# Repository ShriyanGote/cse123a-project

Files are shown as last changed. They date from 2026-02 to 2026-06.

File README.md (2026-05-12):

# 123a-project: Smart Pitcher Base

This repo contains all the code, hardware notes, and documentation for our Smart Pitcher Base project. The system is made up of three pieces:

1. **ESP32C3 firmware** — reads the load cell (HX711) on the pitcher base and POSTs readings to the web server.
2. **Web server / dashboard** — a Vite + React app (deployed on Vercel) that ingests readings into Supabase. Account sign-in and a setup guide live at https://cse123a-project-6a3s.vercel.app/.
3. **Mobile app** — an Expo / React Native app that talks to the web server, displays the water level, and receives low-water push notifications.

Everything lives under [`Code/`](Code). Each sub-project has its own README with run instructions.

```
Code/
├── ESP32/         # firmware (ESP-IDF)
├── web-server/    # Vite + React dashboard + Vercel API routes
├── mobile-app/    # Expo / React Native app
└── 3D Designs/    # printable parts for the base
```

---

# Other things in this repo

- [Documentation/](Documentation) — write-ups and design docs
- [Hardware Notes/](Hardware%20Notes) — schematics, PCB revisions, wiring notes
- [HardwarePicture/](HardwarePicture) — photos of the assembled hardware
- [Meeting Notes/](Meeting%20Notes) — weekly meeting notes
- [Status Updates/](Status%20Updates) — milestone / status reports
- [Code/Links to Test Cases.md](Code/Links%20to%20Test%20Cases.md) — index of test cases
- `git-contribution-report.sh` + `aliases.json` + `folders.json` — helpers for generating per-author contribution metrics

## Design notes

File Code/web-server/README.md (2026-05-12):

# Water Level Web Server

Our Web App: https://cse123a-project-6a3s.vercel.app/

Our Webserver Github Repo: https://github.com/ShriyanGote/cse123a-project/tree/54d26662f9176a54d48d1e06c6b1f1091e2e5d16/Code/web-server

This app shows your latest pitcher level from Supabase and receives new sensor readings through `api/ingest.js`.
It can also send low-water notifications via Expo push when the water level is below 20%.

### Mobile / server API (Vercel)

The React Native app calls these routes instead of Supabase directly:

- `GET /api/app-state` — JSON `{ reading, calibration }` (latest row from `water_readings` and `calibration`).

Set `EXPO_PUBLIC_API_BASE_URL` in the Expo app (optional; defaults to the production URL in `src/api.js`).

## Local dev

Install dependencies:

`npm install`

Run the app:

`npm run dev`

## Testing

Run frontend tests:

`npm run test:run`

## Notification Behavior

- `POST /api/ingest` stores each reading, computes water level percent, and sends low-water alerts via Expo push to tokens registered by the mobile app.

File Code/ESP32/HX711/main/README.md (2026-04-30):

# Custom BLE provisioning (CSE 123A)

Firmware replaces Espressif `wifi_prov_scheme_ble` with a small NimBLE GATT server.

## Build

Requires [ESP-IDF](https://docs.espressif.com/projects/esp-idf/) 5.1+ (test with your installed version).

```bash
cd Code/ESP32/provisioning/custom_ble_prov
idf.py set-target esp32
idf.py fullclean
idf.py build
idf.py -p /dev/ttyUSB0 flash monitor
```

## Configuration

- **API URL**: edit `CSE123A_API_BASE` in `main/main.c` (default matches the deployed Vercel app in this repo).
- **UUIDs**: 128-bit service and characteristics match `ProvisionDeviceScreen.js` defaults (`a0b40001…`–`a0b40004…`).
- **Partition size**: this project uses `partitions.csv` with a 2MB factory app partition (default 1MB is too small for this binary).

## Behavior

1. On boot, Wi‑Fi STA is initialized (not associated). BLE advertises with name `ESP32_XXXXXX` (MAC-based).
2. Serial logs print QR JSON: `{"device_name":"…","device_id":"…"}` (same as on-screen QR if your board supports the component).
3. Mobile app writes **AUTH** (base64 JSON `{"auth_token":"<uuid>"}`) then **WIFI** (base64 JSON `{"ssid":"…","password":"…"}`).
4. **STATUS** notifies: `auth_ok`, `wifi_connecting`, `wifi_connected` / `wifi_failed`.
5. After DHCP, firmware POSTs `POST /api/ingest` with `Authorization: Bearer <auth_token>` and body `device_id`, `weight_g`, `battery_mv`.

Apply `Code/web-server/sql/migration_devices_ble_columns.sql` in Supabase so `devices.auth_token` exists before relying on ingest.

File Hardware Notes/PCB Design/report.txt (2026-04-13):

Info: Processing symbol '3.7v1:'.
Info: Processing symbol '4.1:'.
Info: Processing symbol '4.2:'.
Info: Processing symbol '4.3:'.
Info: Processing symbol '4.4:'.
Info: Processing symbol '4.5:'.
Info: Processing symbol '4.6:'.
Info: Processing symbol '4.7:'.
Info: Processing symbol 'J1:'.
Info: Processing symbol 'L1:'.
Info: Processing symbol 'R1:'.
Info: Processing symbol 'R2:'.
Info: Processing symbol 'R3:'.
Info: Processing symbol 'R4:'.
Info: Processing symbol 'U1:Package_DFN_QFN:QFN-20-1EP_4x4mm_P0.5mm_EP2.5x2.5mm'.
Info: Processing symbol 'U2:'.
Info: Processing symbol 'U3:Package_SO:SOIC-16_3.9x9.9mm_P1.27mm'.
Changed U1 value from QFN-20-1EP_4x4mm_P0.5mm_EP2.5x2.5mm to MCP73871.
Updated U1 symbol association from  to /b3683d0f-a161-44e6-8180-e48fbe466e83.
Updated U1 fields.
Updated U1 sheetname to '/'.
Updated U1 sheetfile to '123-pcb-design.kicad_sch'.
Updated U1 footprint filters to 'QFN*4x4mm*P0.5mm*'.
Add net Net-(J1-CC1).
Connected U1 pin 18 to Net-(J1-CC1).
Add net unconnected-(U1-CE-Pad17).
Connected U1 pin 17 to unconnected-(U1-CE-Pad17).
Add net unconnected-(U1-PROG2-Pad4).
Connected U1 pin 4 to unconnected-(U1-PROG2-Pad4).
Add net unconnected-(U1-~{PG}-Pad6).
Connected U1 pin 6 to unconnected-(U1-~{PG}-Pad6).
Add net Net-(U2-IO6).
Connected U1 pin 20 to Net-(U2-IO6).
Add net unconnected-(U1-PROG1-Pad13).
Connected U1 pin 13 to unconnected-(U1-PROG1-Pad13).
Add net unconnected-(U1-STAT1/~{LBO}-Pad8).
Connected U1 pin 8 to unconnected-(U1-STAT1/~{LBO}-Pad8).
Add net unconnected-(U1-SEL-Pad3).
Connected U1 pin 3 to unconnected-(U1-SEL-Pad3).
Connected U1 pin 1 to Net-(U2-IO6).
Add net unconnected-(U1-THERM-Pad5).
Connected U1 pin 5 to unconnected-(U1-THERM-Pad5).
Add net Net-(U1-V_{SS}-Pad10).
Connected U1 pin 10 to Net-(U1-V_{SS}-Pad10).
Add net Net-(3.7v1-+).
Connected U1 pin 15 to Net-(3.7v1-+).
Connected U1 pin 14 to Net-(3.7v1-+).
Connected U1 pin 21 to Net-(U1-V_{SS}-Pad10).
Add net unconnected-(U1-STAT2-Pad7).
Connected U1 pin 7 to unconnected-(U1-STAT2-Pad7).
Add net unconnected-(U1-PROG3-Pad12).
Connected U1 pin 12 to unconnected-(U1-PROG3-Pad12).
Add net unconnected-(U1-V_{BAT_SENSE}-Pad16).
Connected U1 pin 16 to unconnected-(U1-V_{BAT_SENSE}-Pad16).
Add net unconnected-(U1-VPCC-Pad2).
Connected U1 pin 2 to unconnected-(U1-VPCC-Pad2).
Connected U1 pin 11 to Net-(U1-V_{SS}-Pad10).
Add net unconnected-(U1-~{TE}-Pad9).
Connected U1 pin 9 to unconnected-(U1-~{TE}-Pad9).
Connected U1 pin 19 to Net-(J1-CC1).
Updated U1 unit metadata.
Added U1 (footprint 'Package_DFN_QFN:QFN-20-1EP_4x4mm_P0.5mm_EP2.5x2.5mm').
Changed REF** reference designator to U1.
Added U3 (footprint 'Package_SO:SOIC-16_3.9x9.9mm_P1.27mm').
Changed REF** reference designator to U3.
Changed U3 value from SOIC-16_3.9x9.9mm_P1.27mm to HX711.
Updated U3 symbol association from  to /539b080a-a2a2-44ba-a118-466ed1deb788.
Updated U3 fields.
Updated U3 sheetname to '/'.
Updated U3 sheetfile to '123-pcb-design.kicad_sch'.
Updated U3 footprint filters to '*SO*3.9x9.9mm*P1.27mm*'.
Add net E-.
Connected U3 pin 5 to E-.
Add net GPIO_4/ADC_1.
Connected U3 pin 12 to GPIO_4/ADC_1.
Add net unconnected-(U3-RATE-Pad15).
Connected U3 pin 15 to unconnected-(U3-RATE-Pad15).
Add net unconnected-(U3-XI-Pad14).
Connected U3 pin 14 to unconnected-(U3-XI-Pad14).
Add net unconnected-(U3-XO-Pad13).
Connected U3 pin 13 to unconnected-(U3-XO-Pad13).
Add net unconnected-(U3-BASE-Pad2).
Connected U3 pin 2 to unconnected-(U3-BASE-Pad2).
Add net unconnected-(U3-INB+-Pad10).
Connected U3 pin 10 to unconnected-(U3-INB+-Pad10).
Add net Net-(U3-AVDD).
Connected U3 pin 3 to Net-(U3-AVDD).
Add net unconnected-(U3-DVDD-Pad16).
Connected U3 pin 16 to unconnected-(U3-DVDD-Pad16).
Add net Net-(U3-INA-).
Connected U3 pin 7 to Net-(U3-INA-).
Add net Net-(U3-VBG).
Connected U3 pin 6 to Net-(U3-VBG).
Add net VSUP.
Connected U3 pin 1 to VSUP.
Add net Net-(U3-VFB).
Connected U3 pin 4 to Net-(U3-VFB).
Add net unconnected-(U3-INB--Pad9).
Connected U3 pin 9 to unconnected-(U3-INB--Pad9).
Add net GPIO_5/ADC_2.
Connected U3 pin 11 to GPIO_5/ADC_2.
Add net Net-(U3-INA+).
Connected U3 pin 8 to Net-(U3-INA+).
Updated U3 unit metadata.

Info: Total warnings: 0, errors: 0.

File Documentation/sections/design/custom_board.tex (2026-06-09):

\subsection{Prototype Implementation of Custom Design PCB}

In order to produce large amounts of product, the cheapest and fastest method is to use a custom circuit board. This circuit board would ideally integrate all necessary components with as little extra work as possible. We provide an example prototype implementation using available components. These components can be swapped with other similar types, as long as their main functionality is still met. 

The cost of this custom board will depend on the available components and their individual prices. With the design we have created, the estimated cost for the components of 1 board is \$9.99. This price does not include getting a bare board from a fab, or the cost to place the components. As production scales these costs will go down slightly as higher quantities of materials get a discounted per unit price. This board is designed to be simple to manufacture so that time is not spent in the build process. 

\subsubsection{Processor}

The selected processor is the ESP32-C3-MINI-1. This processor is widely available and was selected for the following reasons. It includes 2.4GHz Wi-Fi and Bluetooth antennas in the packaging. This is ideal for our design as it reduces the number of required components. Adding a separate antenna is possible but would require a different chip selection that includes the required pins for Wi-Fi and Bluetooth. 

The pins we use are the GPIO 4 and 5 pins. On this specific chip they are the ADC channels 0 and 4 respectively. These pins allow us to read data from our amplifier chip, and through the code we are able to interpret that as a weight value. These pins are required for this setup. Using another method like I2C or UART might be possible but would require a complete redesign to match our requirements. Analog to Digital pins are the simplest method for this design. 

The power supply for the chip is provided through the 3.3v pin. We selected a power method that was capable of powering both the amplifier board and the ESP chip. Both can be powered with 3.3 volts. For most of their operational time, the ESP chip will be in standby mode which consumes very little power. The most power intensive time is when transmitting via WiFi as that has a tendency to spike the power consumption. In order to handle this, a power management circuit is required to prevent spikes in current. 

Using a voltage divider to GPIO pin 2, a rough estimate of battery charge can be included in software. The board is set up to make this possible with the proper software implementation. By dividing down the voltage from the battery input, measurements can be made occasionally to determine the voltage output from the battery. This can be used with the knowledge that Lithium Ion batteries have a range in voltage output depending on their store of charge. The lower the output the lower the charge. 

\subsubsection{Power Components}

For this design we provide the MCP73871 as an example chip selection. This is a power management IC that is capable of switching between a USB or AC/DC power source, and a lithium ion battery. When the USB or AC/DC source is providing power, it will power the circuit load and charge the lithium ion battery. This chip selection includes a lot more features than our design takes advantage of, meaning room for expansion of features if desired. 

The requirements a selected chip needs to include are the following. First, it needs to output the correct voltage for the selected amplifier and CPU combo. If not using an amplifier but some other method of data collection, then it needs to be able to output the required power for that method. Second, it needs to take two inputs, a USB or AC/DC input, and a lithium ion battery input. Third, it needs to be capable of charging the lithium ion battery, otherwise the product will only last a single charge and then not be useful to the customer. 

Our selection for this design is to use a USB-C charging receptacle. This would allow us to place a floating port anywhere on the base that would be cheap to supply the cables to users. USB-C is a simple standard that can supply enough power if selecting a part that has only power pins enabled. The selected USB-C port in our designs contains the positive and negative power pins and nothing else. This meets the requirements for the selected power management chip. In order to use the design the way we intend you must select a USB-C or other power method that provides a positive and negative feed to the power chip. 

\subsubsection{Load Cell Amplifier}

The load cell amplifier is a required component for this specific design. Changing the design significantly to where it uses a different load cell than we had intended will require a redesign of this specific circuit component as it is only required for the load cell method selected. The load cell we describe requires a board which amplifies the microvolt output it provides. This chip selection is very important for processing the sensitive weight data produced by a load cell. 

The amplifier board must be powered from the same circuitry as the main chip to keep compatibility. In this design we specify 3.3 volts as the power source, but selecting a chip with a 5 volt or higher input would mean the selected amplifier chip must also be capable of 5 volt power, or wired up using a voltage divider circuit to get the required voltage.

The output of the amplifier board is used by the main CPU and program to determine the current weight placed on the sensor. In our design we specify that output going to analog to digital converter pins meaning the output of this device must be an analog signal, or something that can be interpreted by GPIO pins. 

The inputs for this board come from four pins. We have designed the board so that it can be connected through a 4 pin JST connector. Any four pin connector that is small in form factor and can be soldered to the board horizontally, to lower the height requirements, is the best choice for this design. Keeping the height of the board minimal will mean the plastic base can be smaller and take up less space in a customers fridge. A 4 pin connector keeps the product from requiring soldering wires directly to a board, rather the wires for the load cell can be placed in a connector housing and plugged in directly. In order to seal the product well and prevent movement during shipping, a connector with a locking mechanism is the best choice for the design. 

\subsubsection{Load Cell}

The load cell selection makes a big difference in how much the product can handle. For our prototype and our design we selected a 10 kilogram load cell which should be capable of weighing almost all commercial water filter pitchers. This selection means the most compatibility for the most consumers. Selecting a smaller load cell would limit the number of customers who can purchase it if they have larger pitchers capable of holding more than 4 liters of water. Even if the majority of consumers have smaller pitchers, we hope to provide the most availability. 

The load cell in our design uses four wires to provide readings through a load cell amplifier. The design involves connecting the four wires of the load cell to the board using a 4 pin JST connector. The specific connector choice is described in the amplifier section. The boards will be physically separated by plates that have a small hole for cable routing. The cables should run from the load cell, through the hole, to the pin connection point on the custom PCB. 

\subsubsection{Power Preservation}

The boarded will operating through the use of a battery making it vital for the board to consume less power for longer operation duration. Developing a sleeping cycle to shut off components that do not be turned on all day. Wifi and Bluetooth require the most power in operation, making it necessary to have them on only when necessary, such as sending data or BLE provisioning. Since developing sleep and power, memory must be able to preserved through sleep or sudden power shut offs to not lose data.

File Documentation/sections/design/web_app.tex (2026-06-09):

\subsection{Web Application}

The web application serves as the account-management and onboarding companion to the mobile app. 
It is built using React and deployed on a cloud platform, while being backed by a managed relational database. 
Sensor readings, group membership, device records, and authentication data are all managed within the backend infrastructure, 
which is shared between the web and mobile applications. The interface is organized into two side-by-side panels: 
an \textbf{Account} panel (the Settings page) and a \textbf{Setup guide} panel (the Guide page). The web app exists to let users manage the 
account that the mobile app signs in with, review the devices and groups associated with that account, and consult the first-time setup instructions.

\subsubsection{System Architecture}
The deployed architecture has three coordinated layers:

\begin{itemize}
    \item \textbf{Frontend:} Renders the Settings panel and the Guide panel.
    \item \textbf{Backend Server:} Hosts the sensor-ingestion service used by the microcontroller and authenticated REST services used by both the web app and the mobile app to read and update account, group, and device data.
    \item \textbf{Database:} Provides authentication, a Postgres database for groups/devices/readings, and row-level-security enforcement.
\end{itemize}

\subsubsection{Settings Page}
The Settings page is the Account panel of the web app. It serves two states depending on whether the user is signed in.

\paragraph{Signed out.}
The panel renders a Sign-In form with email and password fields. A hint reminds the user to sign in with the same account they use in the mobile app, since the two clients share the same database authentication system.

\paragraph{Signed in.}
After authentication, the panel displays:
\begin{itemize}
    \item The signed-in user's email and a sign-out control.
    \item \textbf{My Groups} --- a list of the groups the user belongs to, including the user's role in each group and the associated device ID where applicable. Group and device data are fetched from the authenticated REST services.
    \item \textbf{My Devices} --- a list of devices owned by the user, showing each device's name and status.
    \item \textbf{Security} --- a button to sign out of all devices currently signed in to the account and a button to delete the account. Deleting the account will revoke all devices and groups associated with the account.
\end{itemize}

\noindent All requests from the Settings page attach the database access token as a Bearer token; the REST services validate the token before returning data scoped to the user.

\subsubsection{Setup Guide Page}
The Guide page is a static, step-by-step walkthrough for first-time setup of a Smart Base. It is intended to be readable on a desktop screen while the user follows along with the mobile app. The guide covers:

\begin{enumerate}
    \item Unboxing and powering on the base.
    \item Installing the mobile app.
    \item Signing in (or creating an account) and granting Bluetooth and Camera permissions.
    \item Opening the Provision Device flow from the mobile dashboard.
    \item Scanning the QR sticker on the base, which auto-fills the device name and ID.
    \item Entering the Wi-Fi SSID and password the base should join.
    \item Sending the authentication token and Wi-Fi credentials to the base over Bluetooth Low Energy.
    \item Waiting for the base to confirm Wi-Fi connectivity and begin reporting readings.
\end{enumerate}

\noindent The Guide page deliberately mirrors the mobile-app provisioning flow so users have a reference while completing setup on their phone.

\subsubsection{REST API}
The backend server exposes a small REST API shared by the web app, the mobile app, and the microcontroller. User-facing requests carry the database access token as a Bearer credential; sensor uploads use a per-device credential established during provisioning.

\begin{itemize}
    \item \textbf{Authentication} --- Handles email/password sign-in, sign-up, and email verification, and issues access tokens for authenticated sessions. The web Settings sign-in form and the mobile Auth screen obtain tokens through the shared database authentication service; all other user-facing REST endpoints require a valid Bearer token before returning account, group, or device data.
    \item \textbf{Account and profile} --- Read the signed-in user's profile, update display name, sign out all active sessions, and permanently delete the account. Used by the Settings page Security actions.
    \item \textbf{App state} --- Returns aggregated state the clients need on load, including recent reading context for the signed-in user. Used by the Settings page and the Guide page. 
    \item \textbf{Device registry} --- List devices owned by the user and register a new device during mobile BLE provisioning (hardware identity plus one-time credential). Listing is used by the Settings page and mobile dashboard; registration is used by the mobile provisioning flow.
    \item \textbf{Group membership} --- List the user's groups, create a new group, join an existing group by invite code, and fetch detailed group data including members and the latest reading. Listing is used by the Settings page and mobile dashboard; create, join, and detail are used primarily by the mobile app.
    \item \textbf{Group management} --- Rename or delete a group, transfer ownership, and update member roles or remove members. Used by the mobile app.
    \item \textbf{Group calibration} --- Set empty and full reference weights for a group's associated device. Used by the mobile Group screen.
    \item \textbf{Sensor ingestion} --- Accept weight readings from the microcontroller over HTTPS, store them, derive water level from calibration data, and optionally trigger low-water push notifications. Used by the Smart Base firmware.
\end{itemize}

\subsubsection{Data Model}
The shared database stores the entities both clients rely on:

\begin{itemize}
    \item \textbf{Devices} --- Registered bases tied to a user account, including identity, display name, and provisioning credentials where applicable. Shown on the Settings page under My Devices and on the mobile app dashboard.
    \item \textbf{Groups and membership} --- Shared groups with invite codes, role-based membership, associated devices, and per-group calibration values. Shown on the Settings page under My Groups and on the mobile app dashboard.
    \item \textbf{User profiles} --- One record per user, including display name and authentication linkage. Used by both the web app and mobile app.
    \item \textbf{Water readings} --- Timestamped weight readings uploaded by the microcontroller. Consumed by the mobile app to show live water level.
\end{itemize}

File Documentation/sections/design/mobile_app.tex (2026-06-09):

\subsection{Mobile Application}

The mobile application is the primary user-facing interface for the Smart Water Filter Base. 
It is the client that displays live water-level readings for shared groups, handles device provisioning over Bluetooth Low Energy, 
manages device groups, and displays low-water notifications on the user's phone. The web application is limited to 
account management and the setup guide while the mobile app is where day-to-day interaction with the system happens.
The mobile app shares its backend database with the web application. The same email/password account works in both applications, allowing users to manage their account and devices from both the web and mobile interfaces.

\subsubsection{System Architecture}
The mobile app interacts with the rest of the system in three ways:

\begin{itemize}
    \item \textbf{Database Authentication} --- Used for sign-in, sign-up, and live profile state. The same database authentication system is used for the web application and the mobile app.
    \item \textbf{Authenticated REST calls} --- Sent to the backend server to fetch and update account, group, device, and calibration data, using the database access token as a Bearer credential.
    \item \textbf{Bluetooth Low Energy (BLE)} --- For the initial device-provisioning handshake with a Smart Base. The BLE path is currently gated to iOS only.
\end{itemize}

\noindent Low-water notifications are scheduled by the mobile app itself and pushed directly to the user's phone.

\subsubsection{Screens and User Flow}
The mobile app is organized as a stack navigator with the following screens:

\begin{itemize}
    \item \textbf{Intro Screen} --- Shown on first launch. Introduces the product before the user can sign up and sign into the app.
    \item \textbf{Auth Screen} --- Email/password sign-in and sign-up, backed by the database authentication system. Sign-up optionally captures a display name. After account creation, the user receives a confirmation email and is required to verify their email before they can sign in.
    \item \textbf{Dashboard Screen} --- The home screen lists the user's groups and devices, lets the user create a new group, join an existing group by invite code, open the device-provisioning flow, and sign out.
    \item \textbf{Provision Device Screen} --- Walks the user through pairing a new base: scan the QR code on the base, enter Wi-Fi credentials, then transmit them to the base over BLE.
    \item \textbf{Group Screen} --- Detailed view for a single group. Displays the latest reading for the group's associated device, includes calibration controls for empty and full water levels, and is the destination opened when the user taps a low-water notification. Calibration is stored per group rather than as a single global record.
\end{itemize}

\subsubsection{Device Provisioning}
The Provision Device flow is the bridge between an out-of-the-box Smart Base and a cloud-connected device tied to the user's account. The flow proceeds in three stages:

\begin{enumerate}
    \item \textbf{Scan QR} --- The user scans a QR code on the physical base with the device camera. The app decodes the provisioning payload and pre-fills device identity and Bluetooth connection parameters for the next steps.
    \item \textbf{Register on the server} --- The app generates a one-time authentication token and registers the device with the backend so future sensor readings can be attributed to the user's account.
    \item \textbf{Transmit over BLE} --- The app connects to the base over Bluetooth Low Energy, sends the authentication token and Wi-Fi credentials, optionally reads a status response from the base, then polls the server until the newly registered device appears before returning the user to the Dashboard.
\end{enumerate}

\subsubsection{Groups and Sharing}
A user's smart bases are accessed through groups. The Dashboard supports creating a new group (optionally associating it with a device the user owns) and joining an existing group via an invite code. Group owners have the option to remove members, transfer ownership, and delete the group.

The Group screen also allows groups owners to calibrate empty and full reference points. Calibration is stored per group (against the group's associated device) rather than as a single global record.

\subsubsection{Low-Water Notifications}
The mobile app monitors its own group devices for low-water conditions and surfaces local notifications when the level drops below threshold. Three pieces work together:

\begin{itemize}
    \item \textbf{Background monitoring} --- While the user is signed in and the app is active, a background process periodically fetches the latest reading for each group that has an attached device.
    \item \textbf{Threshold detection} --- The app computes each group's water-level percentage and compares it against a fixed low-water threshold. Per-group state ensures one notification per low-water event rather than repeated alerts while the level stays low.
    \item \textbf{Local notifications} --- When a group crosses below threshold, the app schedules a local notification. Tapping it opens the corresponding Group screen.
\end{itemize}

\subsection{Summary of Prototype Implemented Features}

\begin{itemize}

\item \textbf{Smart Base}

\begin{itemize}
    \item \textbf{Implementation:}
    \begin{itemize}
        \item ESP32-C3
        \item 900 mAh Li-ion battery
        \item 3D printed container
        \item Load cell, HX711 amplifier
    \end{itemize}

    \item \textbf{Implemented features:}
    \begin{itemize}
        \item Setup and connection with mobile application
        \item Send weight through HTTPS
    \end{itemize}

    \item \textbf{Missing features:}
    \begin{itemize}
        \item Reset button
        \item Humidity proofing
    \end{itemize}
\end{itemize}

\item \textbf{Mobile App and Server}

\begin{itemize}
    \item \textbf{Implementation:}
    \begin{itemize}
        \item React Native on Expo iOS
        \item Vercel hosting, Supabase database
    \end{itemize}

    \item \textbf{Implemented features:}
    \begin{itemize}
        \item Setup, add, and calibrate devices
        \item Create/join/manage groups
        \item View live water level
        \item Receive low-water notifications
    \end{itemize}

    \item \textbf{Missing features:}
    \begin{itemize}
        \item Customize water level threshold to notify
        \item Full push notifications capabilities (locked by Apple paywall)
    \end{itemize}
\end{itemize}

\end{itemize}

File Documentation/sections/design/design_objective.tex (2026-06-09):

\subsection{Design Objective}

Through the goal statement, it is needed that water level is known at all times to the user.
To approach the goal, two parts needed being what hardware is needed to get accurate readings and what software is needed to communicate
the information to the user.

\subsubsection{Hardware}
We will be collecting data from the users through the weight of their water filters. All of the hardware will be contained in a plastic base which the filter will be set on. This will provide space for all of the internal electronics to be enclosed and kept dry in the humid refrigerator environment. The internal components will need to be sealed in completely to prevent them from getting wet. 

The internal hardware components need to complete a few simple tasks. Detail about specific design choices will be explained in later sections focusing on specific component requirements. The following is a list of requirements for the hardware:

\begin{itemize}
	\item Collect real time weight data
	\item Package weight data in an HTTPS packet and send it through Wi-Fi
	\item Work on battery power for long periods of time
	\item Charge the internal battery using a power port
	\item Have Wi-Fi and Bluetooth for initial setup and active use. 
\end{itemize}

With these requirements in mind, our design uses a few internal components. Most components can be mounted to a custom designed circuit board. Others are connected with built in pins to the circuit board. 

%\subsubsection{Load Cell +  Amplifier + Microcontroller}
%Here are the choices made for the load cell we chose:
%\begin{itemize}
%    \item Using a 20kg Load Cell, it gives sufficient room for most consumer water filter pitchers
%    \item HX711 is a high resolution 24-bit analog to digital converter. The amplifier is specifically built for load cells.
%    \item Microcontroller will have functionalities of Wifi, 2 Pins, GND, 3.3V VCC as essential components.
%    \item Small footprint provided by microcontroller paired with a load cell means saving space and weight.
%\end{itemize}

\subsubsection{Software}

The requirements for the software design involve a few segments. They can be split into categories based on which components they interface with. Starting with the microcontroller code, this code needs to be capable of reading in values from the amplifier which provides serial data through an analog to digital converter. This serial data needs to be converted to a weight value and sent to the data collection server using a secure protocol. The microcontroller should also be capable of sending battery status values including a percentage estimate of the battery charge. 

The software from the microcontroller will send packets containing info to the data collection server. This server must be capable of mapping incoming data to related user accounts that are subscribed to the specific device. Using a unique device ID and authentication token given by the server, incoming data can be assigned to the correct point. The device ID should be sent at the time of setup and will not change through operation. The server should keep tables containing users and their subscribed devices. This server needs to be secure and able to handle the traffic of a large number of devices communicating in real time. 

Once the data is at the server, the mobile application used by users should get up to date information about the status of their filter and active fill value. This data should be updated close to real time in order for features such as notifications to work as intended. The mobile application must be capable of authenticating users using username and passwords unique to the user. The application must include information about each subscribed base, and have accurate information about their status. The app should include a notifications system that will alert users that the fill value has passed below the threshold. The application should communicate using secure protocols to prevent user data from being sent unsafely. 

Notifications will be sent to everyone in the associated group when the water level drops below the threshold. This allows all users to be aware of the water level and give everyone the opportunity to refill it when it is empty, making it more likely that it will be refilled.

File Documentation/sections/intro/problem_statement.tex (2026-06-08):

\subsection{Problem Statement}

Living with roommates can sometimes mean your filtered water device is empty when you need water. 
This can be very frustrating and leave you needing to drink tap water while other roommates get to drink cold refrigerated and filtered water.

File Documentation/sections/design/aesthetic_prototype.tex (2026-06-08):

\subsection{Physical Base Design}
The physical base must consist of:
\begin{itemize}
    \item A compartment containing all components (MCU, battery, load cell, amplifier)
    \item A place to rest a pitcher that can then be weighed
    \item A reset button to restart the device
    \item Humidity-proof seals that allow the device to operate inside the fridge environment
\end{itemize}

\noindent{}Our prototype implementation meets these requirements through the following specifications:\\

The physical base consists of two 3D-printed circular plates sandwiching a 75mm bar-type strain gauge load cell. Each plate is 110mm in diameter and 8mm thick, 
printed in PLA/PETG. The top plate has countersink pockets on the bottom face for M4 bolts 
that secure it to one end of the load cell, and the bottom plate attaches to the other end, sitting flat on the surface. The load cell wires route out to the amplifier and microcontroller on a nearby breadboard.

\subsubsection{Exploded View}
    Figure~\ref{fig:exploded} shows the exploded view of the load cell assembly with all components labeled.
    \begin{figure}[H]
    \centering
    
    \caption{Exploded view of the load cell assembly showing top plate, bottom plate, load cell, and M4 hardware.}
    \label{fig:exploded}
    \end{figure}

\subsubsection{Base Plate Schematic}
    Figure~\ref{fig:schematic} shows the design schematic of the base plate with dimensions and screw hole placement.
    \begin{figure}[H]
    \centering
    
    \caption{Design schematic of the base plate.}
    \label{fig:schematic}
    \end{figure}

\subsubsection{Rendering}
    Figure~\ref{fig:full_assembly} shows how the complete system looks when assembled with a water filter pitcher placed on the scale platform.
    \begin{figure}[H]
    \centering
    
    \caption{Diagram of the full system assembly showing the water filter pitcher resting on the load cell platform, with wiring to the microcontroller and amplifier on the breadboard.}
    \label{fig:full_assembly}
    \end{figure}

\subsubsection{Assembled View}
    Figure~\ref{fig:sideview} shows the assembled base from a side view, with the load cell mounted between the two plates and wired to the breadboard.
    \begin{figure}[H]
    \centering
    
    \caption{Side view of the assembled base showing the two base plates, load cell, and wiring to the microcontroller.}
    \label{fig:sideview}
    \end{figure}

\subsubsection{Completed Prototype}
    Figure~\ref{fig:completed} shows the completed smart base prototype.
    \begin{figure}[H]
    \centering
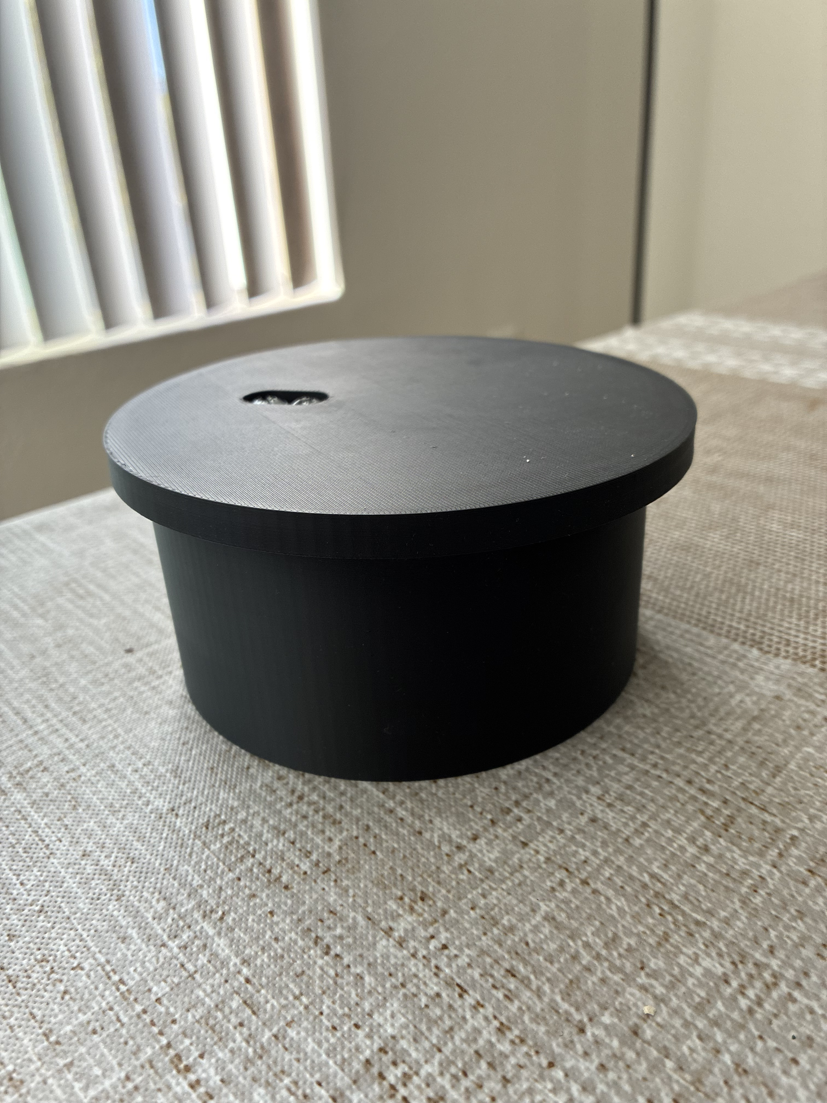
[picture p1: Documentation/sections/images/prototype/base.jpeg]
    
    \caption{Completed smart base prototype sealed.}
    \label{fig:completed}
    \end{figure}

\subsubsection{Typical Use Case}
    Figure~\ref{fig:usecase} shows the finished smart base prototype in a typical use case.
    \begin{figure}[H]
    \centering
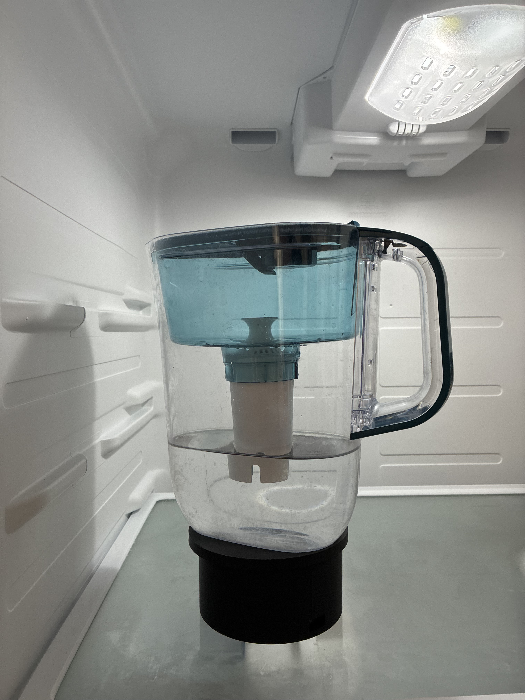
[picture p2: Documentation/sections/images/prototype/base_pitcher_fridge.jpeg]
    
    \caption{Completed smart base prototype with a water filter pitcher on the scale.}
    \label{fig:usecase}
    \end{figure}

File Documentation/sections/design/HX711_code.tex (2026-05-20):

\subsubsection{Amplifier}
The selected load cell for this design requires an amplifier in order to function properly. This amplifier powers the gauge and measures the return voltage through the resistor network. The design includes an amplifier capable of taking in microvolts and outputting 24-bit serial data. This serial data is interpreted by the microcontroller where it is turned to grams. 

\subsubsection{Digital Converter}
To use the design, the software and hardware must be capable of interpreting analog data, converting it to digital data, and performing mathematical operations on the data to convert it to a unit of measurement. Our current design performs the interpretation and conversion to digital at the load cell. The digital data is sent to the microcontroller using GPIO pins where it is operated on by the formulas for conversion to grams. 

\subsubsection{Average Sampling}
To reduce the chance of noise having a heavy affect on our readings, our design implemented an average sampling algorithm, where data is read in for a period of time, averaged, then interpreted as results. This not only prevents high spikes from noise, but also smooths the updating process, so a user placing or removing the filter rapidly will not have an unintended affect on the application, or cause issues like spamming notifications. 

\subsubsection{Tare}
For handling offset, it is required to create to create a baseline state value that represents an empty pitcher. It means future data is can be compared to the baseline value to get the water weight readings. In our prototyping we found the offset value for our specific setup, but this value can change depending on the writing, pathway, and other factors. The offset value must be programmed into the device before is ready to ship.

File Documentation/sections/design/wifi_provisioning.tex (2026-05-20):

\subsection{Smart Base WiFi Provisioning}

In order for the microcontroller to connect to the home network, the user must be able to send the WiFi credentials to the device. This is called WiFi provisioning. In our design, the user connects to the device through BLE and sends the data through the mobile app.

\subsubsection{On Boot}
When the device starts, it will attempt to load saved WiFi credentials and connect to the network. If this fails, it will enter provisioning mode. In our design, the MCU hosts a BLE access point that the user connects to through the mobile app. Once connected, the user will send the WiFi credentials through BLE to the device. The mobile app will also request a unique authentication token from the server for the device to use in the future, which will also be sent over BLE. The MCU will then attempt to connect to the specified WiFi network using the provided credentials. If the connection is sucessful, the device will save the wifi credentials to non-volatile storage and reboot.

\subsubsection{Lost Connection}
If WiFi connection is lost for any reason, the device will enter recovery mode. It will repeatedly attempt to reconnect, exponentially backing off over time to save resources. If connection is restored, the device will go back to normal functioning.

\subsubsection{Manual Reset}
If the user changes WiFi networks or needs to restart the device for any other reason, they can use the reboot button found on the smart base.

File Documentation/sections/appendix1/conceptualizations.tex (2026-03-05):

\subsection{Conceptualizations for Design Approach}
\subsubsection{Contactless Capacitive Water Level Sensing}
A contactless sensor is a small puck that attaches to the side of the water filter. It would work by detecting when the level goes below a certain point, and sending that information to the microcontroller. It's a simple and easy way to do one level detection. It produces a binary output of either above or below the detected level.\\
\noindent\textbf{Pros}
    \begin{itemize}
    \item Low-cost
    \item No contact
    \item Small mechanical approach
    \end{itemize}
\noindent\textbf{Cons}
    \begin{itemize}
    \item Need a good environment for sensor, not humid so not great inside a fridge
    \item Users need to install device themselves, making it hard to standardize what's considered "empty"
    \item Binary output doesn't allow for percentage based information, or any form of consumption metrics. 
    \end{itemize}
    
Because of the noted cons to this design style, we decided to find another solution. The user needing to place the sensor on their own device could throw off any configuration we could complete on our side. It puts too much onto the user for it to work well. 

\subsubsection{Weight based, Load}
The design places the pitcher unto a load cell to measure the weight. We will calibrate it to the changes in weight.\\
\noindent\textbf{Pros}
    \begin{itemize}
    \item Highest accuracy of all designs
    \item Fits to many pitcher dimensions
    \end{itemize}
\noindent\textbf{Cons}
    \begin{itemize}
    \item Need a good environment for sensor, not humid so not great inside a fridge
    \end{itemize}

\subsubsection{Ultrasonic}
An ultrasonic sensor estimates the water level by measuring the echo time of sound waves reflected from the water surface. The sensor would be installed attached to the side of the filter as close to the top of the water compartment. \\
\noindent\textbf{Pros}
    \begin{itemize}
    \item Inexpensive
    \item Easy implementation
    \end{itemize}
\noindent\textbf{Cons}
    \begin{itemize}
    \item Humidity problem
    \item Mounting hardware and wiring sensor is difficult without modifications to container. 
    \end{itemize}
    
If there are modifications to the filter itself in order for a design to work, then the design could not be possible to produce. If we chose this design and needed to modify the pitcher to mount the hardware or get the wiring right, then we would have to sell pre-modified pitchers as well, otherwise users might not be able to use the device properly. Because of these reasons we decided against using this design style. 

\subsubsection{Laser}
A laser or time-of-flight sensor measures the distance from the sensor to the water surface.
The measured distance is converted into liquid height and volume. \\
\noindent\textbf{Pros}
    \begin{itemize}
    \item Continous measurements
    \item Non contact
    \end{itemize}
\noindent\textbf{Cons}
    \begin{itemize}
    \item Humidity problem
    \item Clear line of sight
    \item Mounting problems
    \end{itemize}
    
Some of the same reasons we didn't choose the ultrasonic sensor apply to this laser sensor design. On top of that in order for us to use continuous measurements, the battery power required would raise and we'd have to figure out how to power the device for long periods of time.

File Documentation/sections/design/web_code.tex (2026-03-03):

\subsection{Web Application}

The web application is the user-facing interface for the smart water-level monitor. The design goal is to provide a clear 
real-time estimate of remaining water in the container, allow user calibration for different pitcher sizes, and send refill 
notifications when the water level becomes low.

\subsubsection{Initial Design}

In its most simple form it must be able to display static data on a web page. We have created a .html file with this basic information, shown in the following figure. 

\begin{figure}[h]
\begin{center}

\caption{Output of Initial HTML Code}
\label{basic_html}
\end{center}
\end{figure}

\noindent From here there are a few changes that can be made. These changes follow the line of next steps to test this code and our designs. 

\begin{itemize}
    \item Dynamically updating data with a controller (Proof of concept testing w/ simple text)
    \item Sending and interpreting sensor data 
    \item Graphic interface changes
    \item Sending push notifications to a phone
\end{itemize}

In order to test these things we will create a local server interface using one of our computers that hosts this data. 
Then we will use a microcontroller to send HTTP PUT requests. Finally, using the received data to change what gets displayed. 

\subsubsection{Current Design}

The current design is a React application deployed on Vercel, with a Supabase backend for data storage. The frontend displays the latest water level reading as a percentage, 
along with a visual representation of the water level in the pitcher. Users can calibrate the system by setting empty and full reference points, which allows for accurate 
level estimation regardless of pitcher size or sensor placement. The application also includes functionality to send push notifications to users when the water level falls 
below a certain threshold.

\subsubsection{System Architecture}
The deployed architecture has three coordinated layers:

\begin{itemize}
	\item \textbf{Frontend dashboard:} Displays the latest reading, computes estimated level percentage, and status indicators.
    \item \textbf{Vercel backend:} Receives sensor uploads and notification subscriptions.
	\item \textbf{Supabase Storage:} Stores water readings, calibration parameters, and browser push subscription tokens.
\end{itemize}

\noindent The frontend was designed using the following languages: HTML, CSS, and JavaScript. It utilizes a React framework for building user interfaces. The backend is 
implemented on Vercel, written in JavaScript (Node.js), with API endpoints for data ingestion and notification management. We are using Supabase, which provides a 
PostgreSQL database for persistent storage and real-time capabilities.

\subsubsection{Frontend Design and User Experience}
The current dashboard is minimal and task-focused. Core interface elements are:

\begin{itemize}
	\item A large water-level visualization (pitcher graphic with animated fill height).
	\item A numerical percentage readout for quick interpretation.
	\item A water-present/empty status indicator.
	\item Metadata showing last update timestamp, measured weight, and battery voltage (when available).
\end{itemize}

\noindent Users can quickly assess whether refill action is needed without interpreting raw sensor values.

\subsubsection{API Endpoints}
The application has two primary API endpoints:

\begin{itemize}
    \item \textbf{POST /api/ingest:} Receives sensor readings (device ID, weight, battery) from the microcontroller and stores the data in Supabase. 
    If the weight is below a configured threshold, triggers a low-water notification to registered users.
    
    \item \textbf{POST /api/register-token:} Registers browser push subscriptions from the frontend and saves them in the database.
\end{itemize}

\noindent Sensor data is sent to the ingestion endpoint with an API key, validated, and inserted into a table on Supabase. The dashboard reads the newest 
value from Supabase on a polling interval and renders the latest state. The token registration endpoint enables user devices to register for alert notifications.
When invoked, it associates a device with a user account and stores the device token in a table on Supabase for later use in push notification delivery.

\subsubsection{Supabase Tables}
Supabase serves as persistent storage for both backend APIs and the frontend dashboard state. The ingestion and token-registration endpoints write data to
Supabase using a service-role key, while the frontend dashboard queries the same tables to render the latest readings and calibration settings.\\

\noindent The current deployment uses the following tables:

\begin{itemize}
	\item \textbf{\texttt{water\_readings}} --- Stores time-series sensor uploads from the microcontroller. Each row represents one sample and includes the
	device name, weight in grams, and battery voltage in millivolts (e.g., \texttt{device\_id}, \texttt{weight\_g}, \texttt{battery\_mv}) with a timestamp (\texttt{created\_at}).

	\item \textbf{\texttt{notification\_tokens}} --- Stores browser/device push tokens used for low-water alerts. Tokens are inserted or upserted on
	registration and are later queried by the ingest pipeline when a low-water event occurs.

	\item \textbf{\texttt{calibration}} --- Stores user calibration references for level estimation. The dashboard upserts a single calibration record
	(using \texttt{id} constant) containing empty and full reference values (\texttt{empty}, \texttt{full}), then reads the latest entry when computing displayed percentage.
\end{itemize}

\subsubsection{Calibration}
To support different pitcher geometries and sensor offsets, the application includes user calibration controls:

\begin{itemize}
	\item \textbf{Calibrate empty:} Stores the current reading as the empty reference.
	\item \textbf{Calibrate full:} Stores the current reading as the full reference.
	\item \textbf{Reset calibration:} Clears stored values and falls back to default constants.
\end{itemize}

\noindent The level estimate is computed by linearly mapping measured weight between empty and full references, 
then clamping the result between 0\% and 100\%. This makes the UI behavior predictable while still allowing practical 
adjustments.

\subsubsection{Push Notifications}
The push notification feature is designed as an event-driven subsystem that alerts users only when refill action is needed. 
The implementation uses standard Web Push protocols with VAPID authentication and is integrated into the ingest API used for sensor data.

\paragraph{1) Subscription Registration}

When the dashboard is loaded, the browser requests notification permission. If permission is granted, a service worker is registered and 
a Push API subscription is created (or reused if it already exists). The subscription object is sent to the backend endpoint and stored 
in the \texttt{notification\_tokens} table in Supabase.

\noindent This registration path has two design goals:
\begin{itemize}
	\item maintain a durable list of reachable user devices, and
	\item avoid duplicate subscriptions by upserting on token value.
\end{itemize}

\paragraph{2) Alert Trigger Condition}

Sensor readings are received by the ingestion endpoint and stored in \texttt{water\_readings} table. For each new reading, the backend 
computes current and previous water-level percentages and checks for a low-level threshold crossing. The low-water threshold is currently set to 20\%.
This design prevents repeated notifications while the level remains continuously low.

\paragraph{3) Delivery}

If the trigger condition is true, the backend loads all stored subscriptions and sends a Web Push payload to each valid endpoint. The payload includes a:
\begin{itemize}
	\item notification title
    \item notification body
	\item structured data (event type and level percentage) for client-side handling.
\end{itemize}

\noindent The service worker receives the push event, displays the notification, and handles click interaction by focusing an existing app tab or opening the web page.

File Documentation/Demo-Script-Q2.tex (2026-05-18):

\documentclass[12pt]{article}

\usepackage{graphicx}
\usepackage{fancyhdr}
\usepackage{geometry}
\usepackage{xcolor}
\usepackage{enumitem}
\usepackage{url}

\geometry{margin=1in}

\title{CSE 123 - Demo Script\\Smart Water Pitcher Base\\NOT TURNED IN DONT MAKE IT LOOK GOOD}
\author{Group 8}
\date{}

\begin{document}
\pagestyle{fancy}
\maketitle
\fancyfoot{}
\fancyhead{}
% \fancyfoot[R]{\thepage}

%% --------------------------------------------------------
\section*{Introduction}
\noindent\textbf{Presenter:} Pieter\\  
\noindent\textbf{Estimated Time:} 1.5 minutes

\noindent\textbf{Action:} Hold up or gesture toward the water pitcher.

\bigskip
\noindent\textit{Script:}

\begin{quote}

Sharing a communal water filter can lead to unfortunate moments where you want water, but there is none left in the pitcher. What can be done about this issue? What are the root causes of this problem? And how can we design a solution to reduce the number of times this happens to you. 

We all have that one person who returns the filter back empty. They just took a large bottle's worth of water but didn't take the time to refill the pitcher for the next person. With this smart base two things will happen. First, you will be able to access an app that tells you how much water is in the pitcher at any given time. This can let you know how much water is in the pitcher at any given time. Second, a notification will alert you if the pitcher is returned with water below 20\% full. 

With all of these features in mind, how do they work, and how will you the user interact with our product? 

\end{quote}

%% --------------------------------------------------------
\section{Typical Usage}
\noindent\textbf{Presenter:} TODO\\  
\noindent\textbf{Estimated Time:} TODO\\

\noindent\textbf{Action:} Screen should show app and camera pointed at prototype.

\bigskip
\noindent\textit{Script:}

\begin{itemize}[itemsep=-3pt]
\item screen shows current water lvl
\item \textbf{Action: }\textit{Take out some water}
\item now it shows the new level
\item now i'll completely empty it
\item \textbf{Action: }\textit{Empty pitcher}
\item as you can see the water level updated and everyone in the group rcvd a notification to refill
\item \textbf{Action: }\textit{Refill pitcher}
\item and now it shows that its full again
\end{itemize}

%% --------------------------------------------------------
\section{Account Creation}
\noindent\textbf{Presenter:} TODO\\  
\noindent\textbf{Estimated Time:} TODO\\

\noindent\textbf{Action:} Screen should show app and camera pointed at prototype.

\bigskip
\noindent\textit{Script:}

\begin{itemize}[itemsep=-3pt]
\item create account w email, name etc
\item show email verification and verify
\item sign in on app
\end{itemize}

%% --------------------------------------------------------
\section{Provisioning}
\noindent\textbf{Presenter:} TODO\\  
\noindent\textbf{Estimated Time:} TODO

\bigskip
\noindent\textit{Script:}

\begin{quote}

``When first purchasing product, users need to set up the device. they start by opening app and click setup.''
\vspace{5px}\\\textbf{Action: }\textit{Open setup page on mobile app}\vspace{5px}\\
``First scan qr code that comes with the device to connect to it over bluetooth.''
\vspace{5px}\\\textbf{Action: }\textit{Scan QR code}\vspace{5px}\\
``Next enter the home wifi name and password, which will be sent to the device along with an auth token so it can communicate with the server.''
\vspace{5px}\\\textbf{Action: }\textit{Enter WiFi credentials}\vspace{5px}\\
``Once it is connected, users can create a group and invite other users to it, so they can all see the water level and get notifications when it needs to be refilled.''
\\\textit{}\\
\end{quote}

%% --------------------------------------------------------
\section{Joining a Group}
\noindent\textbf{Presenter:} TODO\\  
\noindent\textbf{Estimated Time:} TODO

\bigskip
\noindent\textit{Script:}

\begin{itemize}[itemsep=-3pt]
\item open group page
\item select device, enter name,  and create group
\item open group and show current water level
\item pour some water out and show it reflects change
\item show group code, let other person join, show that they joined on the group page
\item textbf{hold other phone under camera for other person joining}
\item empty water filter and show both ppl got the notif
\item change group name
\item delete group
\end{itemize}

%% --------------------------------------------------------
\section{Calibration}
\noindent\textbf{Presenter:} Pieter\\
\noindent\textbf{Estimated Time:} 2 minutes

\bigskip
\noindent\textit{Script:}

\begin{itemize}[itemsep=-3pt]
\item open group
\item explain why calibrate
\item do empty and full
\end{itemize}

In order for the product to be useful to every possible customer, a calibration sequence is required when setting it up. This calibration feature is also available at any time if the user purchases a new filter. Setting the calibration requires an empty and a full value. 

We'll start with full. First, take the pitcher at a full level and place it on the base. Then navigate through the app to find the calibration buttons. Once the full pitcher is on the scale, press "Calibrate Full".  Next, pour out the water from the filter until it is all empty. Place the pitcher back on the scale and press "Calibrate Empty". Now the levels will be accurate to your specific water filter. 

%% --------------------------------------------------------
\section{Webpage}
\noindent\textbf{Presenter:} TODO\\
\noindent\textbf{Estimated Time:} TODO

\noindent\textbf{Action:} Screen should show the webpage open in a browser.

\bigskip
\noindent\textit{Script:}

\begin{quote}
``Alongside the mobile app, we also have a webpage that users can access from the browser.''
\vspace{5px}\\\textbf{Action: }\textit{Setup Guide panel}\vspace{5px}\\
``The webpage hosts our setup guide, so a new user can go through the steps and setup their Smart base. These steps cover from openeing the packaage to having it connected to wifi.''
\vspace{5px}\\\textbf{Action: }\textit{Open the webpage and sign in}\vspace{5px}\\
``The second part of thewebpage  focuses on account management. Once a user signs in, they come to their account page, where they can see all the groups they are in  and all the devices linked to their account. They  also have some security features like signing out everywhere and deactiviting their account, in case their phone gets lost or stolen.''
\vspace{5px}\\\textbf{Action: }\textit{Show signing out everywhere feature}\vspace{5px}\\
``Clicking on the singing out feature, will sign all devices that are loggged in this account out.''
\vspace{5px}\\\textbf{Action: }\textit{Show delete account}\vspace{5px}\\
``Clicking on the delete account button, will delete the account. Once you delete it, it is gone. After that you must create a new account.''\end{quote}
%% --------------------------------------------------------

% conclusion
\end{document}

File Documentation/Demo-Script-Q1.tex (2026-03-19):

\documentclass[12pt]{article}

\usepackage{graphicx}
\usepackage{fancyhdr}
\usepackage{geometry}
\usepackage{xcolor}
\usepackage{enumitem}
\usepackage{url}

\geometry{margin=1in}

\title{CSE 123A - Demo Script\\Water Level Monitoring System}
\author{Group 8}
\date{}

\begin{document}
\pagestyle{fancy}
\maketitle
\fancyfoot{}
\fancyhead{}
% \fancyfoot[R]{\thepage}

%% --------------------------------------------------------
\section*{Part 1: Introduction}
\noindent\textbf{Presenter:} Pieter\\  
\noindent\textbf{Estimated Time:} 1 minute

\noindent\textbf{Action:} Hold up or gesture toward the water pitcher.

\bigskip
\noindent\textit{Script:}

\begin{quote}
``Has this ever happened to you? You come home after a long day, you're thirsty, and you go to grab the water filter pitcher---only to find it completely empty. Nobody refilled it.
This is a common problem in shared living spaces---dorms, family homes, offices. Everyone uses the filtered water, but nobody knows when it's running low until it's too late. We want a way to know if the container is out of water when we need water. The goal is if the container is empty, we inform users.
Our project hopes to solve this. We built a smart water level monitoring system that sits underneath your water filter pitcher, continuously tracking how much water is left, and sends a notification to everyone in the household when it's time to refill.''
\end{quote}

%% --------------------------------------------------------
\section*{Part 2: Overview }
\noindent\textbf{Presenter:} Reid\\  
\noindent\textbf{Estimated Time:} 1.5 minutes

\noindent\textbf{Action:} Point at the various system components as they are mentioned.

\bigskip
\noindent\textit{Script:}

\begin{quote}
``Our design has three main components: the smart base, the web server, and the mobile app.

The smart base sits beneath the water pitcher and measures the weight of the pitcher, which can be used later to determine how much water is left. This weight data is sent to our web server over WiFi using HTTP packets, where it's stored in a database and processed. 

The mobile app is connected to the web server and is able to access this weight data. When the water level drops below a certain threshold, the mobile app will send push notifications to the users. The app also allows users to view the current water level and configure various settings.

\textit{[Switch to prototype diagram.]}
Today, we will be demonstrating the prototype of our design. We are simulating the connection between the smart base and the web server through two laptops: one connected to the microcontroller to read the sensor data, and another sending simulated weight data to the web server. Our mobile app is currently in the form of a webapp on a laptop, but still has the core functionality that the mobile app would have.'' 

\end{quote}

%% ------------------------
\section*{Part 3: Hardware \& Live Demo}
\noindent\textbf{Presenters:} Dev \& Logan\\  
\noindent\textbf{Estimated Time:} 3 Minutes

\noindent\textbf{Action:} Dev places the pitcher on the platform with the terminal open on the connected laptop. Logan picks up or points to each hardware component as he explains it.

\bigskip
\noindent\textit{Script:}

\medskip
\noindent\textbf{Dev:}
\begin{quote}
``Let me set up the live demo first. I'm going to place this empty water pitcher on the sensor base. Over here on the laptop we have the terminal open, where you can see the raw weight readings coming in from the microcontroller via USB. The load cell is now measuring the weight of the pitcher.

While this sits on base, Logan is going to walk you through the hardware that makes this work.''
\end{quote}

\medskip
\noindent\textbf{Logan:}
\begin{quote}
So let me break down what's going on inside this base. The system has three main components:

\textbf{First, the load cell.} This is a strain-gauge weight sensor. When weight is applied, it bends slightly, and that bending changes its electrical resistance. The change is very tiny---so we use the \textbf{HX711 amplifier board} to boost the signal into something our microcontroller can read. The HX711 gives us 24-bit resolution, which means we can detect very small changes in weight.

\textbf{Second, the microcontroller.} This is the brain of our system. It reads the weight data from the HX711 and outputs the readings to the terminal you see on the laptop.

\textbf{Third, the mounting base.} We designed and 3D-printed two circular plates that sandwich the load cell. The pitcher sits on top. We designed these with M4 screw holes so everything stays secure and aligned.''
\end{quote}

\medskip
\noindent\textbf{Dev:}
\begin{quote}
``Now that you know how the hardware works, let me show you how it reads in action. So right now the terminal is showing the current weight value with the pitcher on the base.

So now let me pour some water in to simulate a user putting water in the pitcher.

\textit{[Pour water into the pitcher.]}

Now if you watch the terminal, you can see the weight values increasing as we pour water into the pitcher. The microcontroller is reading the load cell continuously, so the changes show up right away.''
Now let me pour some water out to simulate someone using the pitcher throughout the day.

Now let me pour some water out to simulate a user using some of the water from the pitcher.
\textit{[Pour water out of the pitcher into a cup.]}
 
And just like before, you can see the values in terminal drop as the water after we put the pitcher back on the base.

\end{quote}

% show how software works

\section*{Part 5: Software Demo}
\noindent\textbf{Presenter:} Shriyan\\  
\noindent\textbf{Estimated Time:} 4 minutes

\noindent\textbf{Action:} Open laptop to the web server to demonstrate navigating the page

\bigskip
\noindent\textit{Script:}

\begin{quote}
``The initial prototype uses a web dashboard to display important device information. This dashboard is also where the initial configuration of the product happens. When a user first starts up this device, they need to calibrate it with empty and full weights. 

\textit{[Highlight calibration buttons]} Both an empty and a full value are required for the product to work as intended. In the startup sequence the user will be prompted for an empty pitcher of water to be placed on the base. After pressing the calibration button they will be asked to fill it up and return it to the base to calibrate the full value. 

Full and empty values are adjustable and configurable at any time, so if a user buys a new filter that holds a larger quantity of water, they can simply change the calibration values and continue using the device as intended. 

When the values are calibrated, the system is able to use the data sent by the microcontroller to adjust the visible water level."
\end{quote}

% show how notifications work
\section*{Part 6: Notification Demo}
\noindent\textbf{Presenter:} Sam\\  
\noindent\textbf{Estimated Time:} 3 minutes

\noindent\textbf{Action:} Keep the dashboard visible and reset the water level to above the low-water threshold 20\%.

\bigskip
\noindent\textit{Script:}

\begin{quote}
``Now we will demonstrate the push notification feature and how we can subscribe to notifications for when the water level is running low.

\textit{[Point to the current percentage on the dashboard.]}
As you can see here on the dashboard, right now, the water level is at [read water level value]. Our low-water threshold is currently set to 20\% and as you can see, the pitcher level is above 20\% right now, so no notifications will be sent. 
Once the level drops below that threshold, the web app will trigger a push notification to subscribed devices. But to see this happen, we have to first subscribe to notifications. 

\textit{[Point to "Enable Notifications" button on the dashboard.]} Once you click on this button here that says "Enable Notifications", it will prompt you to allow notifications for our web app. Once you press allow on the prompt, your device will be subscribed and ready to receive notifications.
Now lets try clicking on the button and allowing notifications.

\textit{[Click on "Enable Notifications" button and allow]} Ok, now that we have enabled notifications, you can see on the dashboard under the Water Pitcher Status that it says "Notifications are enabled".
Now, we can test it out by first measuring the pitcher when it is near empty. [Water Refiller Person] will now pour out water from the pitcher until it is almost empty and put it back on the base. 

\textit{[Pour out water from the pitcher]} And since our base is currently not integrated with the webapp, we will simulate this change by manually sending a low weight value to the web server to trigger the notification. Once the low weight value is sent, 
you should see the dashboard update to show the new water level and you will also be able to see the push notification appear on the top right corner of the screen, so please watch closely. We will now send the low weight value.

\textit{[Simulate water level to less than 20\%]} As you can see on the dashboard, it now reads [read value below 20\%]. You should've also seen the push notification pop up on the top right corner of the screen. If you were paying attention, you would've seen that the message payload in the notification 
showed that the filter is running low and needs to be refilled. It also showed the current water level percentage. Now [Water Refiller Person] will refill the pitcher to a percentage that is above the low-water threshold. 

\textit{[Refill the pitcher to above the low-water threshold and put on base]} After the pitcher is refilled and the percentage rises, the system returns to normal and waits for the next low-water event.''
\end{quote}

% Q&A

\section*{Part 7: Questions}
\noindent\textbf{Presenter:} Pieter (prof suggested same as intro person)\\  
\noindent\textbf{Estimated Time:} 5 minutes

\noindent\textbf{Action:} Leave all components visible on the center of the demo table, ready to be moved or pointed at for any questions regarding hardware. 

% conclusion
\end{document}

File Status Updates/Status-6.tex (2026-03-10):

% status report 6
\documentclass[12pt]{article}
\usepackage{graphicx}
\usepackage{fancyhdr}
\usepackage{geometry}
\usepackage{hyperref}
\usepackage{xcolor}
\usepackage{url}
\geometry{margin=1in}

\title{CSE 123A - Week 6 Status}
\author{Group 8}
\date{}

\begin{document}
\pagestyle{fancy}
\maketitle

\fancyfoot{}
\fancyhead{}
\fancyfoot[R]{\thepage}

\noindent Link to Status Updates section in our repo \\
\url{https://git.ucsc.edu/pnauwela/123a-project/-/tree/main/Status\%20Updates?ref_type=heads}\\
\noindent Demo\\
\url{https://git.ucsc.edu/pnauwela/123a-project/-/blob/main/Documentation/Demo-Script.pdf?ref_type=heads}\\
\noindent Design Schematic\\
\url{https://git.ucsc.edu/pnauwela/123a-project/-/blob/main/Documentation/Diagrams/Architecture_Diagram.pdf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}\\
 % whats been completed 
\section*{What we Did}
This week we conducted code tests on important system functionality. The tests were created for the microcontroller code and focused on verifying logic for the sensor. We also updated significant portions of documentation and diagrams to prepare for presentations. These design documents will be important when presenting the initial prototype. 

Another major improvement came in the hardware. They were reprinted to recess the screws and create a flat plane for more accurate measurements. We now also have code working for HTTP GET and POST requests from a separate microcontroller. This is just as a proof of concept and will eventually be included in the main system code. 
 
% whats in progress
\section*{What we are Working On}

We are working on preparing a script for the initial prototype presentation. We are also working on system connections to prepare for the next iteration of our prototype. Most of the work in-progress is documentation as we wrote code and now need to document how it works and why we chose to write it this way. 

% what next on the agenda 
\section*{What's next}

The next step is to complete the presentation script. It is also to have a more complete document to provide for the design document. We also need to prepare for the next changes we will be implementing in spring quarter. The next iteration of the design is already in the planning stages and we have an idea of what direction we will be going in. 
% Individual contributions

\section*{Individual Contributions}

\noindent\textbf{Dev Chodavadiya}:

This week I focused on hardware iteration and documentation. 

On the hardware side, I reprinted the base plates to fix a flatness issue — the previous prints were slightly slanted, so I adjusted the print settings to ensure the bottom plate sits level on a surface. 

On the documentation side, I made progress on the design document by writing the research into existing designs section, the sustainability statement, and the aesthetic prototype section with CAD renders and photos of the current assembly.

I will design and print washers to go between the load cell sensor and the plates for better contact and stability. The team will continue working on the demo script to have it ready for the demonstration.\\

\noindent\textbf{Logan Bossuwe}:

This week I focused integrating Wifi and Http post with the weight code using Rieds code. Currently harded coded credentials for network access but HTTP post working correctly with sending Grams. I created a main file to modularize our code for future adds on.

For documentation, I focused on updating Design document for the HX711 sensor. Additionaly, I added towards the brainstorming and conceptualisation that are I already briefly wrote earlier in the quarter. I reformatted and edited it to match the Design Document theme. In addition, I started documenting collaboration.

I will be working on creating a proper Wiring Diagram next week and working toward more test plan documentation and code simulations.\\
\noindent\textbf{Pieter Nauwelaerts}:

This week I created the testing code for the HX711 sensor. The major changes include a different way of approaching how we design the microcontroller code in order to allow us to switch between the microcontroller, and test code. This was done using a C header file to define the shared functions, and having two separate main files, one for microcontroller deployment, and one for testing. 

The test code simulates the Wheatstone bridge sensor and passes the functions data that would come in or out. Simulated weight readings go into the functions, the logic is the same as the logic used by the microcontroller, and the output comes out as is verified agains what we should expect to see. The logic we use in the microcontroller can now be verified and tested. This includes pushing it to the limit by having very fast sequences of activity and checking that the outputs come out in the same order. 

\noindent\textbf{Reid Graham}:

This week, I created the code for the microcontroller to connect to a WiFi network and send HTTP GET and POST requests. I also created header files for organization and relavant functions, as well as helped to integrate this functionality into the main file. I also created some test code for the WiFi provisioning code, including testing important functions like url decoding. For the physical sensor, I installed a new base plate for the scale that made it more stable.

I also worked on the design document, including editing the architecture diagram, adding to the block diagrams section, and writing some of the documentation for the WiFi provisioning functionality.

For the next week, I want to prioritize finalizing the design document, including the sections on test plan and results and MCU HTTP functionality.

\noindent\textbf{Sam Lai}:

This week, I worked on reimplementing the push notification logic for the webapp to use Push API instead of Firebase Cloud Messaging. 
The web app is now able to receive push notifications on all browsers on desktop, android, and on IOS safari home screen apps. The app
will prompt the user to allow notifications, and if they accept, it will subscribe them to push notifications. I also worked on the web 
app section of the design document. This includes writing about the initial design and the current design of the web app which includes 
detailed sub sections about the architecture, frontend design, backend api endpoints, database tables, and the push notification system. 
I will continue to work on the design document and will be focusing on the testing section next. I will also be working on creating unit 
tests for the notification system and subscription prompt.

\noindent\textbf{Shriyan Gote}:

This week, I wrote C files to test the server connection using POST HTTP requests from the microcontroller. I also wrote documentation about the web app code, re-did the calibration flow in the dashboard, and worked on adding environment variables to Vercel for deployment.\\

\end{document}

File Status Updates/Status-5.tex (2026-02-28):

% status report 5
\documentclass[12pt]{article}
\usepackage{graphicx}
\usepackage{fancyhdr}
\usepackage{geometry}
\usepackage{hyperref}
\usepackage{xcolor}
\usepackage{url}
\geometry{margin=1in}

\title{CSE 123A - Week 5 Status}
\author{Group 8}
\date{}

\begin{document}
\pagestyle{fancy}
\maketitle

\fancyfoot{}
\fancyhead{}
\fancyfoot[R]{\thepage}

\noindent Link to Status Updates section in our repo \\
\url{https://git.ucsc.edu/pnauwela/123a-project/-/tree/main/Status%20Updates?ref_type=heads}

 % whats been completed 
\section*{What we Did}
This week, we calibrated the load cell to within 1-2 grams for current tests, redesigned the base plate to be thicker, and changed 
the screw hole layout to ensure the bottom stays flat. We also updated our engineering drawings and architecture diagram 
to match our new initial prototype scope. We restructured the web app to support calibration directly from the UI and also created 
web app unit tests for water-level calculation and calibration logic. The user can now calibrate the empty and full states, which 
are used to calculate the water level percentage. 
 
% whats in progress
\section*{What we are Working On}
We are working on bridging the gap between each others smaller works. Best example is starting to send/recieve data to the webserver. Additionaly, the plates
for the prototype had a mistake in the initial design, so we are revising for more accuracate weight measures. We also began working 
on a demo script for our end-of-quarter presentation and the push notification logic is being reimplemented using Push API instead of 
Firebase Cloud Messaging, which will allow us to send push notifications on IOS devices.

% what next on teh agenda 
\section*{What's next}
We plan to print the newly redesigned base plates, which has a flat bottom to provide more accurate and stable weight 
readings. We are also increasing the plate thickness to handle heavier loads and expanding the plate dimensions to accommodate 
a wider variety of container sizes.

% also have indivudal secitons of what each persion did and is working on

\section*{Individual Contributions}

\noindent\textbf{Dev Chodavadiya}:
This week, I redesigned the base plate to increase its thickness and revised the screw hole layout to a racetrack pattern, 
ensuring the bottom surface sits flat. I also created engineering drawings for the base plates and worked on developing a 
demo script for our end-of-quarter initial prototype presentation.\\

\noindent\textbf{Logan Bossuwe}:
This week I calibrated the weight to the accuracy within 1-2 grams of the weight. I will test future weights heavier than 5kg. I began looking at combining the code Ried wrote so we can start sending data through http.
I also began adding toward the design document with the calibrating code document. \\

\noindent\textbf{Pieter Nauwelaerts}:
Significant updates to diagrams for the initial prototype presentation. Changes include noting that we will be showing the smart base reporting data to a laptop serial connection rather than through a WiFi to server connection. We will also be demonstrating a web app rather than a working phone app. 
I also began the process of creating test programs for the current sensor setup so we can test the code written and determine if any fixes or possible corner cases were left out. This also includes limit testing how fast the data can be updated, as well as how it handles repeated changes to the state. \\

\noindent\textbf{Reid Graham}:
This week, I restructured the design document to better match the outline in Canvas and to include important information on the architecture of our product.
I also updated the architecture diagram after our discussion on communication between the microcontroller and web server. It now shows that the MCU will only send data, the weight, and calculations and calibration will happen on the webapp side. \\ 

\noindent\textbf{Sam Lai}:
This week, I worked on creating unit tests for the web app, specifically for the water level calculation and calibration actions. 
The unit tests cover several cases, such as when there is no weight data available, whether the water level is correctly calculated 
based on the weight data, and whether the calibration action correctly updates the calibration data. I am currently working on reimplementing 
the notifications using Push API instead of Firebase Cloud Messaging. Push API has all the features of Firebase Cloud Messaging, but 
it is able to send push notifications on IOS devices, which is a major advantage over Firebase Cloud Messaging. \\

\noindent\textbf{Shriyan Gote}:
\noindent This week, I worked on calibration and end-to-end testing with the ESP32 by sending sample weight readings and validating 
the computed water level against expected base values. I also restructured the web app to support calibration directly from the UI 
by adding configuration controls (calibrate empty/full) that store values in Supabase and update the percentage calculation based on 
those calibration points.\\

\end{document}

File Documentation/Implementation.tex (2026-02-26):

\documentclass[12pt]{article}
\usepackage{graphicx}
\usepackage{fancyhdr}
\usepackage{geometry}
\usepackage{xcolor}
\usepackage{pgfgantt}
\usepackage{url}
\geometry{margin=1in}

\title{Implementation Doc}
\author{Group 8}
\begin{document}
\pagestyle{fancy}
\section{Design Approach}
\subsection{Contactless Capacitive Water Level Sensing}
The strip will be placed vertically on the exterior side of the brita/pitcher to detect exact water level. 
Works as long as plastic is not too thick which britas fit the description. 

\subsubsection{Pros}
    \begin{itemize}
    \item Low-cost
    \item No contact
    \item Small mechanical approach
    \item Customizable for future addons
    \end{itemize}
\subsubsection{Cons}
    \begin{itemize}
    \item Need a good environment for sensor, not humid so not great inside a fridge
    \end{itemize}

\subsection{Weight based, Load}
The design places the pitcher unto a load cell to measure the weight. We will calibrate it to the changes in weight.
\subsubsection{Pros}
    \begin{itemize}
    \item Highest accuracy of all designs
    \item Fits to many pitcher dimensions
    \end{itemize}
\subsubsection{Cons}
    \begin{itemize}
    \item Need a good environment for sensor, not humid so not great inside a fridge
    \end{itemize}

\subsection{Ultrasonic}
An ultrasonic sensor estimates the water level by measuring the echo time of sound waves reflected from the water surface.
\subsubsection{Pros}
    \begin{itemize}
    \item Inexpensive
    \item Easy implementation
    \end{itemize}
\subsubsection{Cons}
    \begin{itemize}
    \item Humidity problem
    \end{itemize}

\subsection{Laser}
A laser or time-of-flight sensor measures the distance from the sensor to the water surface.
The measured distance is converted into liquid height and volume.
\subsubsection{Pros}
    \begin{itemize}
    \item Continous measurements
    \item Non contact
    \end{itemize}
\subsubsection{Cons}
    \begin{itemize}
    \item Humidity problem
    \item Clear line of sight
    \end{itemize}

    \section{Decision Matrix}

Criteria will be scored on a scale from 1 (poor) to 5 (excellent). Weights were assigned according to relative importance. The final score for is calculated as:

\[
\textbf{Total Score} = sum(weight × score)
\]

\subsection{Evaluation Criteria}

\begin{itemize}
\item \textbf{Cost}: Estimated hardware and implementation expense
\item \textbf{Power}: Power consumption and low-power operation
\item \textbf{Complexity}: Mechanical, electrical, software integration difficulty
\item \textbf{Measurement Data}: Quality of information provided (Continous water level, binary off or on, ability to track water usage)
\end{itemize}

\subsection{Weighted Decision Matrix}

\begin{table}[h]
\centering
\begin{tabular}{lcccc}
\hline
\textbf{Criteria (Weight)} & \textbf{Capacitive} & \textbf{Weight} & \textbf{Laser} & \textbf{Ultrasonic} \\
\hline
Cost (0.30) & 5 & 4 & 3 & 5 \\
Power (0.20) & 5 & 4 & 3 & 4 \\
Complexity (0.25) & 5 & 3 & 2 & 3 \\
Measurement Data (0.25) & 3 & 5 & 3 & 3 \\
\hline
\textbf{Weighted Total} & \textbf{4.40} & \textbf{3.95} & \textbf{2.70} & \textbf{3.85} \\
\hline
\end{tabular}
\caption{Decision matrix comparing feasible sensing approaches (1 = poor, 5 = excellent)}
\end{table}

\end{document}

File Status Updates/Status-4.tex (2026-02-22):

% status report 4

\documentclass[12pt]{article}
\usepackage{graphicx}
\usepackage{fancyhdr}
\usepackage{geometry}
\usepackage{hyperref}
\usepackage{xcolor}
\usepackage{url}
\geometry{margin=1in}

\title{CSE 123A - Week 4 Status}
\author{Group 8}
\date{}

\begin{document}
\pagestyle{fancy}
\maketitle

\fancyfoot{}
\fancyhead{}
\fancyfoot[R]{\thepage}

 % whats been completed 
\section*{What we Did}

% talk about the sensor we are setting up and designing a base for

We have purchased the power module for this device. For the prototype we will be using a 3.7V 950mAh lithium ion 
battery. It will be connected to the ESP32 using the battery contact pins and a soldered on connector. Once we 
have set the device up in a way that we don't need to talk to it using USB for testing, we can power it solely 
from this battery. It should have more than enough power to support the board and the connected sensor. 
We also began designing custom 3D-printed mounting plates for the Digital Load Cell Weight Sensor. The circular 
plates (110mm diameter) went through several design iterations to get the M4 screw hole positioning and sizing 
right, with test prints done to verify fitment against the actual load cell.
 
% whats in progress
\section*{What we are Working On}
We are currently calibrating the load cell sensor now that the mounting plates have been built and tested. This 
involves configuring the HX711 breakout board and tuning the readings to ensure accurate weight measurements. 
We are also working on an improved plate design that includes countersunk screw holes so the base sits flat on 
a surface, as the current version leans slightly due to the screw heads protruding from the bottom. 

% what next on teh agenda 
\section*{What's next}
We will be working on implementing push notifications for users when the water level is low. This will involve 
integrating Firebase Cloud Messaging (FCM) into our web server and setting up the necessary infrastructure to 
send notifications to users. We will also be working on writing unit tests for receiving sample water level data 
and triggering notifications. Additionally, we will continue refining the hardware design and calibration of the 
load cell sensor to ensure accurate and reliable measurements.

% also have indivudal secitons of what each persion did and is working on

\section*{Individual Contributions}

\noindent\textbf{Dev Chodavadiya}:
\begin{itemize}
    \item Designed custom circular mounting plates (110mm diameter) for the Load Cell Weight Sensor using OpenCAD
    \item Went through multiple design revisions to achieve proper M4 screw hole placement, aligning holes at 22mm and 32mm from the 
        plate center to match the load cell mounting points
    \item Test printed plates to verify fitment and adjusted hole diameter sizing to ensure proper M4 screw compatibility
\end{itemize}

\noindent Next steps include designing and printing spacers to go between the load cell and the mounting plates, as well as adding 
a recessed countersink around the screw holes on the bottom of the plate so the screw heads sit flush and the base lays flat on a surface.\\

\noindent\textbf{Logan Bossuwe}:
\begin{itemize}
    \item From Dev's constructed plates, we communicated plate designs and I built the weight prototype with the 3D printed designs. I used 2 screws for both the top and bottom plate to lock them wit the load cell. Additionally added 5 washers with the screws to put a small buffer that will later be a proper 3D printed design.
    \item I soldered the Load Cells, 4 wires to their respective connections on the HX711. The load cell itself is a wheatstoen bridge circuit, and the HX711 is the amplifier.
    \item Successfully communicated a connection between each respective component, ESP32, HX711, and load cell to produce raw data. At the moment it is noisy.
    \item Began making debugging prints for future edge case testing.
\end{itemize}
\noindent Next, I will calibrate the raw data into a useable data being Grams. I will start to build a main file that will connect all ESP32 code together for running.
I will begin creating tests the functions and check the calibration through known weights.
\\

\noindent\textbf{Pieter Nauwelaerts}:
\begin{itemize}
\item Purchased battery and required hardware to mount it to the ESP device. 
\item Updated working document and information regarding testing procedure and initial HTTP Code
\item Created design drawings representing multiple stages of the design process
\item Created design drawing representing the finalized and ideal product deployment. 

\end{itemize}

\noindent\textbf{Reid Graham}:
\begin{itemize}
    \item Created basic architecture diagram for code and communication between the ESP and Webapp
    \item Coded the ESP to host a soft access point for sending WiFi credentials
    \item Coded the ESP host an HTTP server and HTML page which can receive user input
    \item Helped to solder the sensor to the amplifier
\end{itemize}

\noindent My next tasks are to code the ESP to attempt to connect to the given WiFi credentials and exit the setup phase. If it cannot connect, it should stay in setup and ask the user to submit again through the HTML page. I also plan to create the basic HTTP send and receive code so the ESP is able to connect to our web server once it is on the WiFi.
\\

\noindent\textbf{Sam Lai}:

\begin{itemize}
    \item Cloned the separate web server repository and tested if I can deploy to Vercel successfully
    \item Tested the server locally and made myself familiar with the codebase
    \item Researched ways to implement notifications to users when the water level is low
    \item Found two methods: text message notifications and push notifications.
\end{itemize}

\noindent I am leaning towards push notifications since they are more user friendly and can be implemented using a service like 
Firebase Cloud Messaging (FCM). Text message notifications would require integrating with a service like Twilio, which 
have additional costs, while FCM has a free tier that should be sufficient for our needs. I will be working on integrating 
FCM into our web server and setting up the necessary infrastructure to send push notifications to users when the water level 
is low. I will also be working on writing some unit tests for receiving sample water level data and triggering notifications.\\

\noindent\textbf{Shriyan Gote}:
\begin{itemize}
    \item Styled the web dashboard as a Brita water level checker with a pitcher graphic, animated water fill, and percentage display
    \item Added last-updated timestamp and a green status indicator when water is present in the pitcher
    \item Implemented demo mode with mock sensor data so the UI can be tested without live hardware
    \item Fixed the water level animation so it shows the current level immediately on page load and only animates when the value changes from new data
    \item Set up deployment workflow to push to both the UCSC (GitLab) and GitHub repositories
\end{itemize}

\noindent Next steps include keeping the web server in sync with the team repo and continuing to refine the dashboard as sensor data becomes available.\\
\noindent Additionally, I will be working with Sam to implement additional features for the server and web app..\\

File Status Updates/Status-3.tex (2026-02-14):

% mention collabrative tools that we use
% format
% - waht we did 
% what we are currently working
% what to do in the future

%todo:
% script for demonstration
% timeline

% status report 3

% put gitlab link in report and give access to prof and ta
% https://git.ucsc.edu/pnauwela/123a-project/-/tree/d3ba4457ead67f81f786f53da5bf10631144b1ea/

\documentclass[12pt]{article}
\usepackage{graphicx}
\usepackage{fancyhdr}
\usepackage{geometry}
\usepackage{hyperref}
\usepackage{xcolor}
\usepackage{url}
\geometry{margin=1in}

\title{CSE 123A - Week 3 Status}
\author{Group 8}
\date{}

\begin{document}
\pagestyle{fancy}
\maketitle

\fancyfoot{}
\fancyhead{}
\fancyfoot[R]{\thepage}

% talk about what we did week
\section*{What we Did}
For this week we continued researching parts and other components we will need for our project. We also started to think about everything will be implemented and what we want to for our working demo. 
We also now have a few design and concept drawings demonstrating the first design we will be implementing. These drawings will likely change and become more detailed as we iterate over ideas. 

For parts, we have ordered the load cells and amplifier from Amazon and are waiting for them to arrive so we can start work on soldering. Code decisions have been made and we are in the process of setting up initial prototypes for each segment. 

\section*{In progress}
We just emailed BELS about the parts for that we will need for our design, and until they respond, we are researching what is the best type of 
load cell we should use. for the other components we will be using an ESP32c3 as the microcontroller, and we plan on hosting a server using Vercel and Supabase 
for the web app database. For the housing of the project, we will plan various designs and out of those we will 3D print each design and test them to see which one would be the best.

\section*{What we need to}
While waiting on all the components to arrive, we are working on the implementation of the web app and the server, and we are working on the design of the housing. 
We will also start building the firmware for the microcontroller and the sensor, so we can start testing and soon it arrives. For our prototype demonstration, we will have load cell sensor 
connected to our microcontroller to which all of it will be connected to a computer that will output the water level by showing either a graph, or a number that will indicate the water level. 
We will also have a web app that will show the water level, however it will not be fully connected to the microcontroller, but it will be able to show the water level by using a mock data that we will generate.

%Script for the demonstration

\end{document}

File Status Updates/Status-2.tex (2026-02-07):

% mention collabrative tools that we use
% format
% - waht we did 
% what we are currently working
% what to do in the future
% email bels about items we may neeed

%todo:
% morphologic table:
   %% sensor/way of measuring
   %% power source (batteries, rechargable, etc)
   %% how to send/store status (http)
   %% app (webapp, ios app)
   %% app code language, hosting method, etc
% decision table (weight, distance, outside sensor)
% timeline
% items list to bels soon
% status report 2

% put gitlab link in report and give access to prof and ta
% https://git.ucsc.edu/pnauwela/123a-project/-/tree/d3ba4457ead67f81f786f53da5bf10631144b1ea/

\documentclass[12pt]{article}
\usepackage{graphicx}
\usepackage{fancyhdr}
\usepackage{geometry}
\usepackage{hyperref}
\usepackage{xcolor}
\usepackage{url}
\geometry{margin=1in}

\title{CSE 123A - Week 2 Status}
\author{Group 8}
\date{}

\begin{document}
\pagestyle{fancy}
\maketitle

\fancyfoot{}
\fancyhead{}
\fancyfoot[R]{\thepage}

% talk about what we did week
This week, we focused on transition from initial setup into planning the project. We reviewed and refined our overall project timeline to better align the task and goals across the remaining weeks. We also began looking at potential hardware components by identify key parts and comparing possible options using a decision table.

% section timeline
\section*{Timeline}
The team finalized a detailed timeline outlining goals from initial decisions through prototyping and testing. This timeline establishes clear goals for part selection, hardware/software development, and end-to-end testing, providing a structured plan to complete the project within the remaining weeks. By having these goals early on, we have a clear expectation for what we need to deliver and reduce the chances of falling behind during the build and testing phase. 

% section decision table
\section*{Decision Table}
We came up with a few ideas for what hardware we could use. For the microcontroller, we decided on using the esp32 because we are familiar with it from CSE121. Our main discussion was on what sensor we should use to measure the water level in the container. We have the following sensors to decide from: ultrasonic, load cell/weight, laser, camera, and non-contact strip sensor. For the server, we decided on a basic HTTP server for now; there are also other options we could use, like AWS and Vercel. After discussing these resources, we identified some challenges such as wifi connectivity/signal in the fridge, size constraints, contact vs no-contact sensors, and what power source to use (battery, usb, etc).

\section*{Todo Next Week}
In the next week, we plan to finalize our contribution tools using a local LaTeX compiler with the GitLab separated files. Once everyone has switched over, we will delete the older version. We also plan to research possible sensors for our initial and stretch goals, along with ordering them from BELS and downloading the documentation for the sensors. We will also create the decision table, using the details above, so that we can make a final decision during our Monday meeting with the TA.

\section*{Project Decisions}
We have selected GitLab as our project location. We will be using \LaTeX\ documents in the shared repository to keep track of documentation, research, and work completed. We have also decided that our issues tracking manager of choice is in GitLab using their issues board. We have set it up to include starting issues and basic project function goals like research tasks. Our repository with all of these things is linked here: \url{https://git.ucsc.edu/pnauwela/123a-project/-/tree/d3ba4457ead67f81f786f53da5bf10631144b1ea/}

\end{document}

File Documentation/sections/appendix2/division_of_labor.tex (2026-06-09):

\subsection{Division of Labor}

\noindent\textbf{Dev Chodavadiya}:
For this quarter, I focused on the physical design, software features. For hardware, I designed and 3D-printed the housing for the product for the water filter base, iterating on multiple versions to acheive the correct height and correct locking mechanism. For the software, I worked on implementing the user signout feature and account deletion functionality. I also contributed to documentation by writing the design document sections on the physical design and software features, as well as some of the drawings and diagrams.\\

\noindent\textbf{Logan Bossuwe}:
I handled the Load Cell and HX711 sensor hardware to the microcontroller. I soldered the board with Ried that has the amplifier and microcontroller on it to be placed inside the prototype. Additionally, I printed the final iterations toward our aesthetic prototype. For the software, I implemented HX711 sensor code for accurate readings and calibrated it to output grams to be sent via HTTP. I created a main file where I combined other members code related to the microntroller into it and ensured safety with memory depending on the boot cycles.
For the main code file, I added a sleep cycle for power preservation, which had to system designed with the other parts such as BLE, HTTPS Post and NVS. For documentation, the main contribution was conceptualizing design ideas with a decision table and focused on proper documentation load cell amplifier and power preservation methods for the battery. I worked on early implentations of diagrams for the amplifier and microcontroller.\\

\noindent\textbf{Pieter Nauwelaerts}:
My main contribution to this development was in the form of creating a custom board design to match the project requirements. I designed the circuitry and found all of the required components to implement our design properly. I  used these components to design a board layout that could be manufactured as it passes all design rule checks. This board includes all of the features our microcontroller design has, including wifi/bluetooth, power management through a USB port or battery, and the load cell amplifier. 

I also contributed to design document updates in making the document more professional and design focused for someone to try and recreate our design in the future. I created diagrams, images, and designs for the poster, presentation, and design document. \\

\noindent\textbf{Reid Graham}:
I mainly worked on the physical smart base, documentation, and planning. For the smart base, I worked on the physical assembly of the device, including printing, soldering, and plate assembly. For the smart base software, I created an HTTP and HTTPS library, as well as multiple versions of libraries for WiFi connection, reconnection, and provisioning.

I also worked to plan basic feature capabilities as well as the test plans. I organized team meetings and communicate with the course staff about various issues. Since I could not easily work on the mobile application without a Mac device, I also contributed more to the poster, presentation, and design document, as well as created diagrams.  \\
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

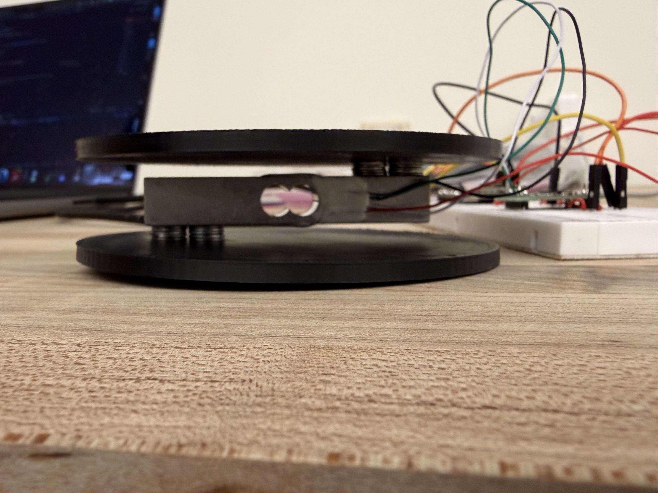
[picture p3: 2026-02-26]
HardwarePicture/sideview.jpg

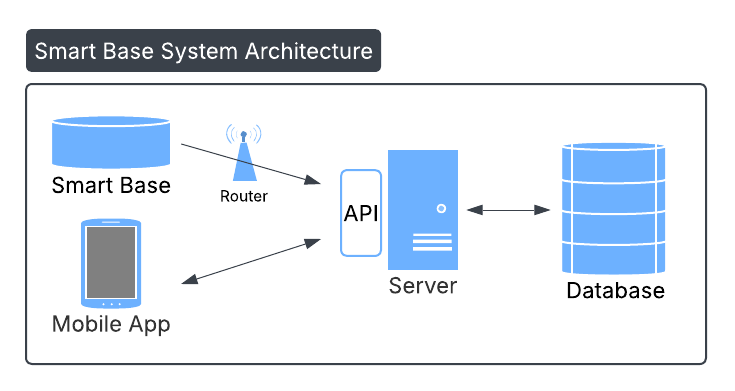
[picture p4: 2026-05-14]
Documentation/Diagrams/basic_system_architecture.png

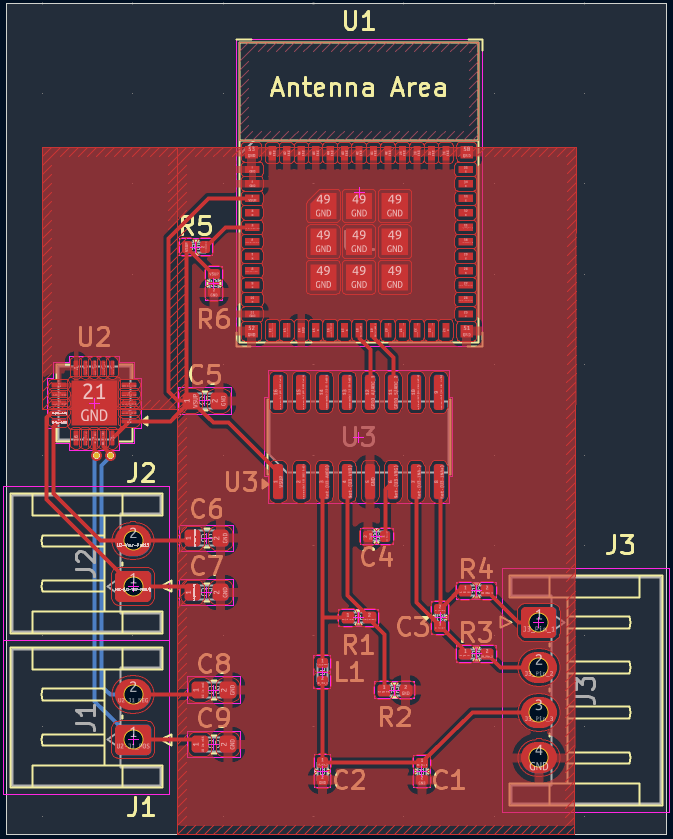
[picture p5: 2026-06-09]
Hardware Notes/PCB Design/layout.png

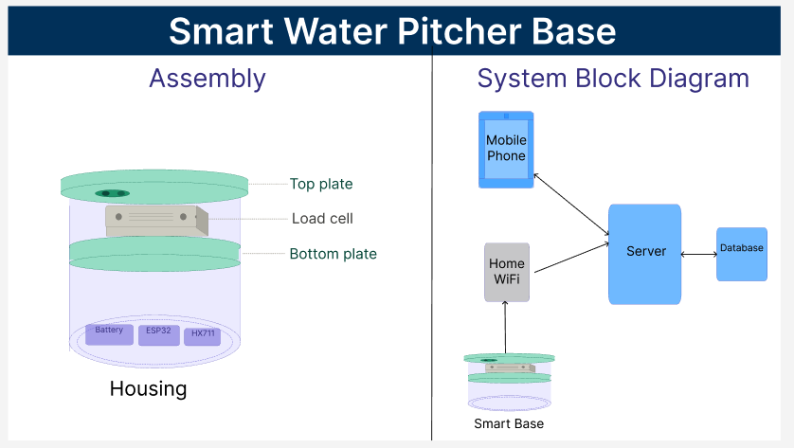
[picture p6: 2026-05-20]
Documentation/Diagrams/system_architecture_diagram_q2.png

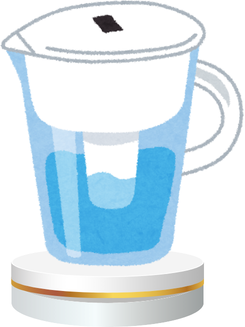
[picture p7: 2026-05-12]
Code/mobile-app/assets/water_filter.png

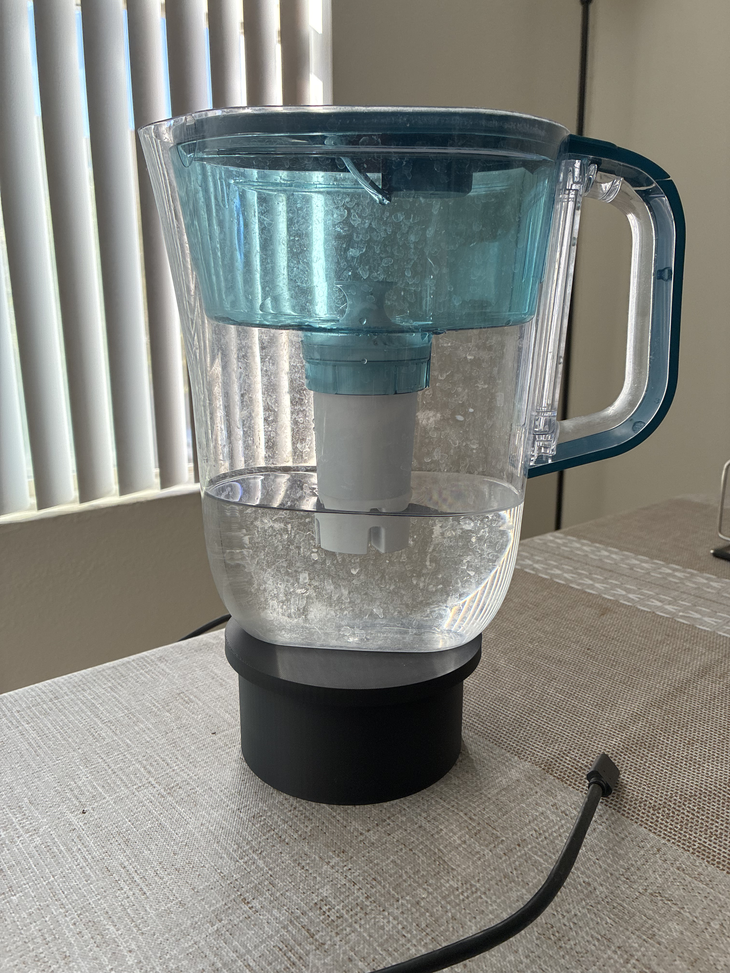
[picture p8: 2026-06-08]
Documentation/sections/images/prototype/base_pitcher.jpeg

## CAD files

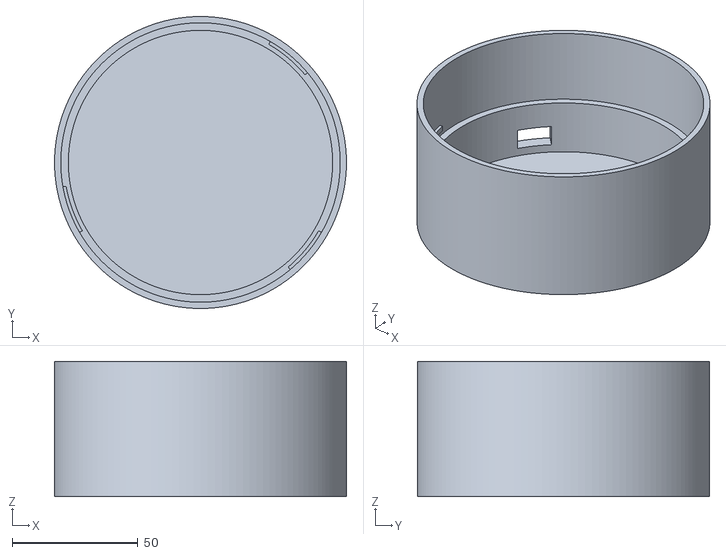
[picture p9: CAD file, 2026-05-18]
Code/3D Designs/compartment_v10.stl
116.0 x 116.0 x 53.8

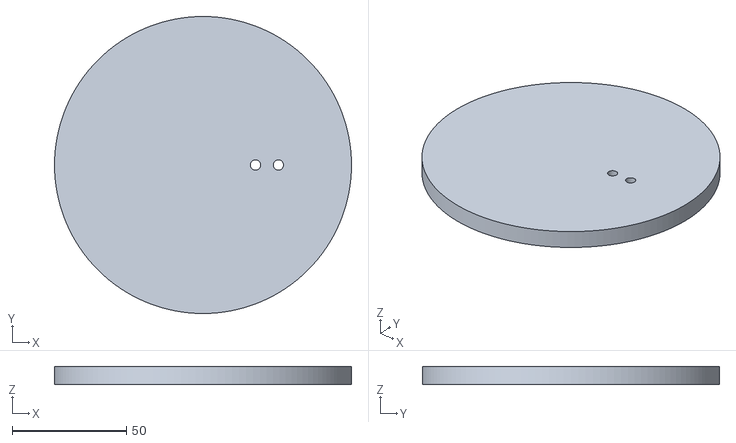
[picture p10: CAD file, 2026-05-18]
Code/3D Designs/top_plate_v2.stl
130.0 x 130.0 x 8.00

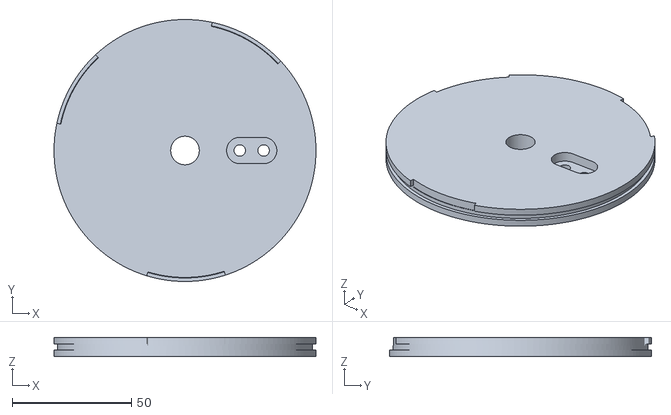
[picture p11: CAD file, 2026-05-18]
Code/3D Designs/base_plate_v13.stl
110.0 x 110.0 x 8.05

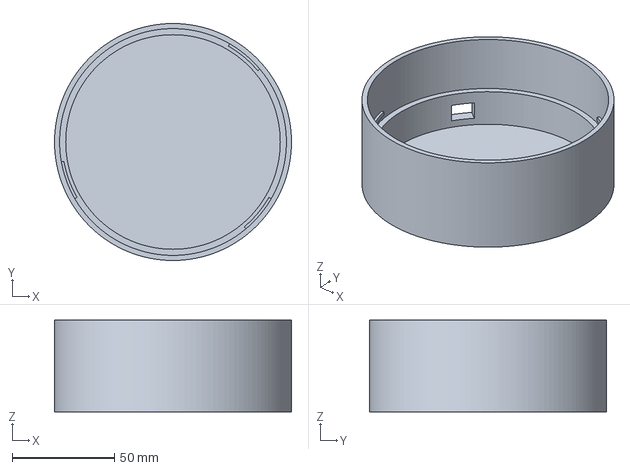
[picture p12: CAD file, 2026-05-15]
Code/3D Designs/compartment_v7.3mf
116.0 x 116.0 x 44.8 mm

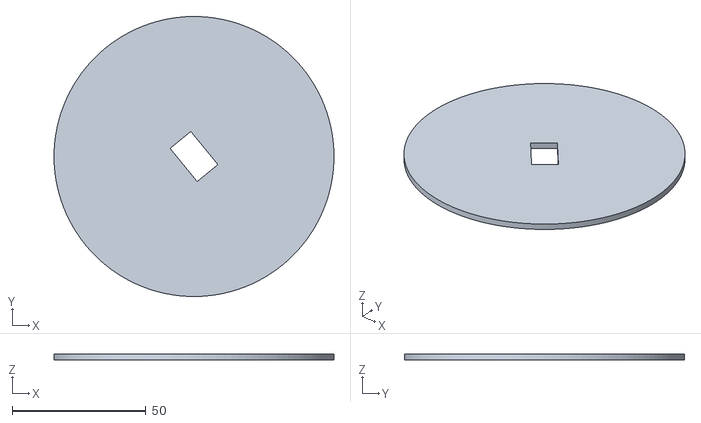
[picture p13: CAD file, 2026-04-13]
Code/3D Designs/compartment_lid_v1.stl
104.6 x 104.6 x 2.30

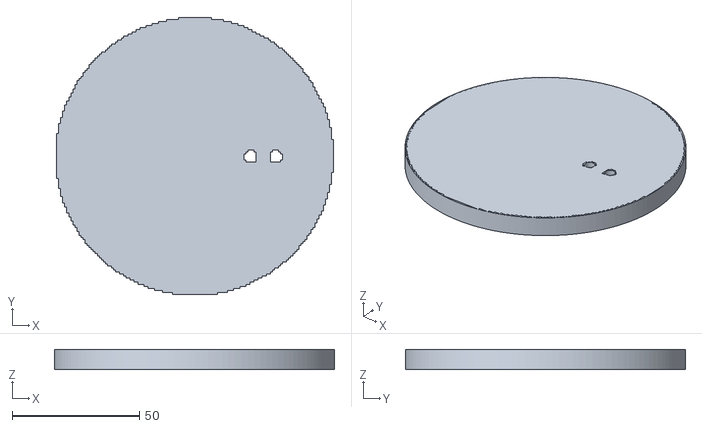
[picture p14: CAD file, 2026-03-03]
Code/3D Designs/base_plat_v8.stl
110.0 x 110.0 x 8.00

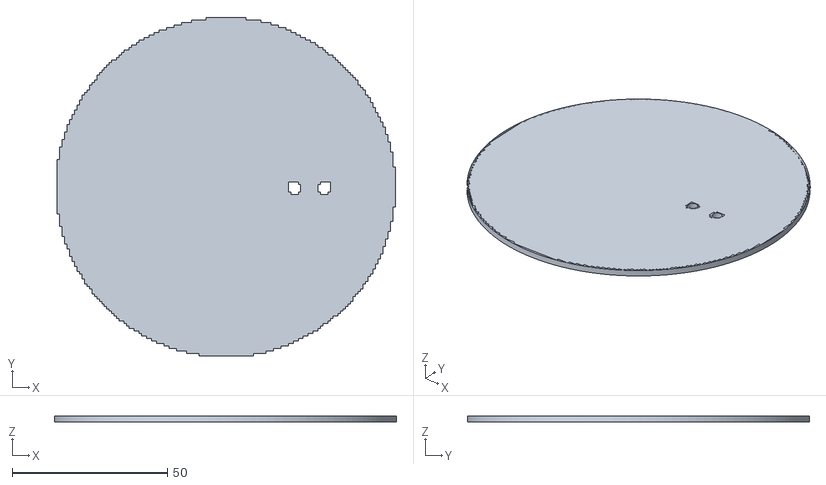
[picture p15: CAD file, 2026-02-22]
Code/3D Designs/test_plate.stl
110.0 x 110.0 x 2.00

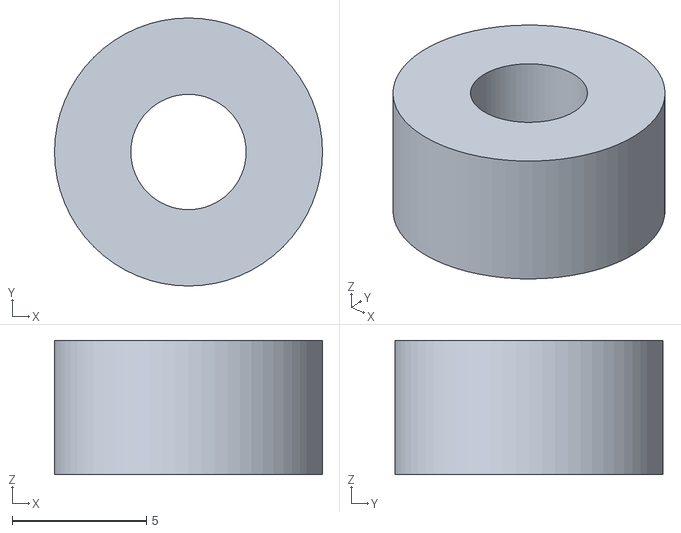
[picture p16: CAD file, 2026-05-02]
Code/3D Designs/washer_m4_v2.stl
10.0 x 10.0 x 5.00

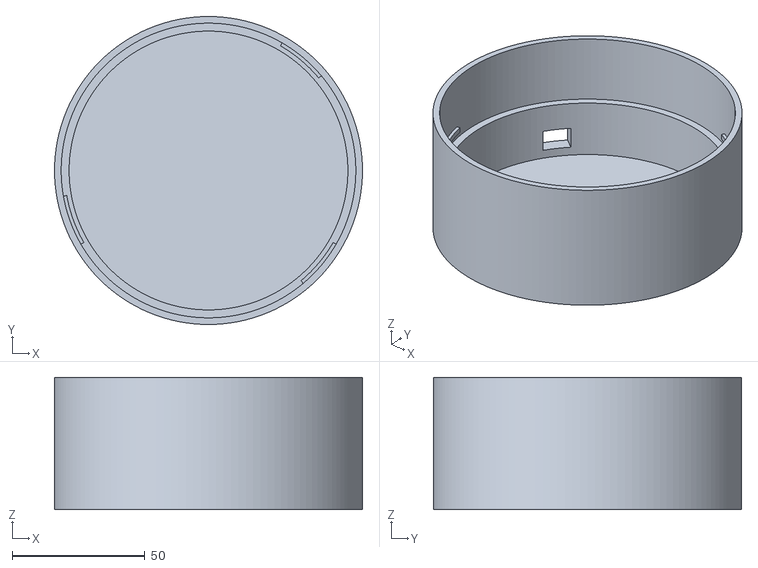
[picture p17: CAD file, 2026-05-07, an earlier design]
Code/3D Designs/compartment_v8.stl
116.0 x 116.0 x 49.8

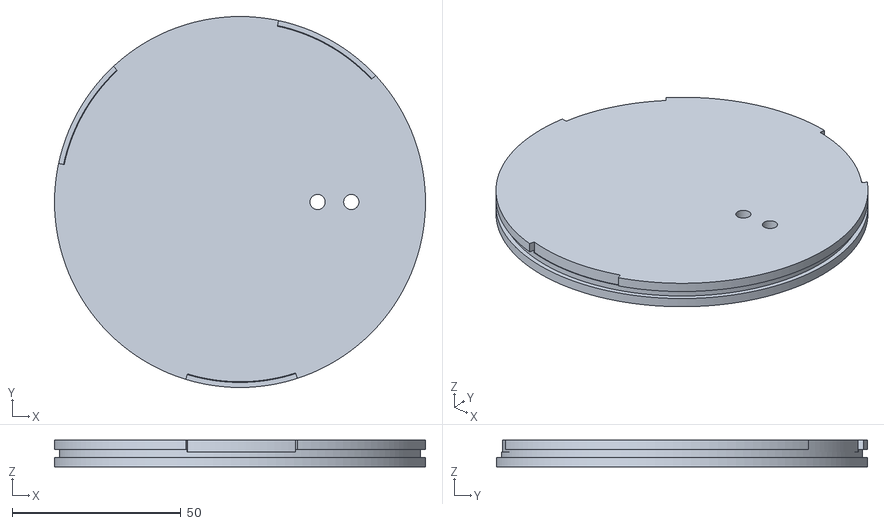
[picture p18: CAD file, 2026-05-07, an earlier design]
Code/3D Designs/base_plate_v11.stl
110.0 x 110.0 x 8.00

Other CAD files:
Documentation/Diagrams/Filter-System.dwg
Documentation/Diagrams/Filter-System-Prototype.dwg
Documentation/Diagrams/Wiring Diagram.dwg
Code/3D Designs/base_plate_v12.3mf
Documentation/Diagrams/Wiring-Diagram-v2.dwg
Code/3D Designs/compartment_v9.stl
Code/3D Designs/top_plate_v1.stl
Code/3D Designs/base_plate_v10.stl
Code/3D Designs/base_plate_v1.stl
Code/3D Designs/base_plate_v12.stl
Code/3D Designs/base_plate_v2.stl
Code/3D Designs/base_plate_v3.stl
Code/3D Designs/base_plate_v4.stl
Code/3D Designs/base_plate_v6.stl
Code/3D Designs/base_plate_v7.stl
Code/3D Designs/base_plate_v8.stl
Code/3D Designs/base_plate_v9.stl
Code/3D Designs/compartment_v1.stl
Code/3D Designs/compartment_v2.stl
Code/3D Designs/compartment_v3.stl
Code/3D Designs/compartment_v4.stl
Code/3D Designs/compartment_v5.stl
Code/3D Designs/compartment_v7.stl
Code/3D Designs/washer_m4.stl

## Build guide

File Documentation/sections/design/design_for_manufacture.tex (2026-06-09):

\subsection{Design for Manufacture}

The design is intended for large scale manufacturing using a custom PCB. This custom PCB includes all required components such as the CPU, RAM, and Flash storage required to function as a microcontroller. It will also include power contacts for the battery, a power management unit for charging the included battery, and components like the WiFi antenna. The PCB design is an outline of what is required. Selected components can be changed and the circuitry altered as required if parts are unavailable.

The PCB will be mounted inside the 3D printed base and all other components will be contained within the base or related plates. The product is intended to be useable, and rechargeable without having to take apart or disconnect any internal components. This is so that it can be properly sealed from humidity to protect the sensitive electronic components. 

The following diagram is the circuit diagram for the PCB we designed with currently available components. Additional components may be required if using different hardware than what we designed. 

\begin{figure}[H]
\centering

\caption{Wiring Diagram for PCB Components}
\end{figure}

\begin{figure}[H]
\centering

\caption{PCB Layout Using Commercial Components}
\end{figure}

\subsubsection{3D-Printed House}
The base assembly consists of three 3D-printed parts: a top plate, a bottom plate, and a compartment at the bottom for the electronics. All parts are printed in PLA. The top and bottom plates are both 110mm in diameter and 8mm thick, with M4 screw holes and racetrack-shaped pockets for mounting the load cell. The plates went through multiple iterations to resolve flatness issues, which affected the stability of the load cell.

The compartment is a circular open-top tray with a 116mm outer diameter and a 110mm inner diameter, sized so the plates sit flush inside it. There is a resting shelf for the bottom plate to sit on, and tabs slightly above it so that when the plates are turned, they are held in place.

In the assembled stack-up, the compartment sits below the bottom plate so that the load cell remains free to flex under load while the electronics remain enclosed. Since the compartment is open at the top, the top plate is slightly wider, serving two purposes: to provide a cover for the compartment, and to be large enough for various sizes of pitchers to be placed on top of it.

In order to fully cover all components the base housing must be large enough to contain the load cell and associated electronics completely. For our design we chose to use two separate compartments within the base to separate out the electronics from the load cell. For a future design with the custom circuit board or a different load cell it could be possible to use a single compartment housing all components. When manufacturing at a large scale, using 3D printers may not be fast enough so the design could be changed to use a resin cast, or some other method of creating plastic components at a large scale for cheap. 

\subsubsection{Load Cell Assembly}

Our design includes a load cell which has screw holes for attaching it to plates. Both plates are required and spacers are needed to bring the load cell off the plane, to a point where it is able to function as intended. This design is intended for a strain gauge load cell capable of measuring up to 20 kilograms. When designing for manufacture this part is a simple install with four screws. The cables required should be placed into a 4 pin connector so that it can interface properly with the custom PCB design. Using connectors rather than soldering will make the manufacturing process easier and reduce the chance that components break during shipping as these wires are very thin. 

\subsubsection{Electronics}

The electronics will be contained inside a separate section of the 3D Printed base. The top section contains the load cell. The bottom section will have all of the mounting for the PCB, battery, and charging input. The wires for the selected load cell will come down through the bottom mounted plate through a small hole, then be connected to pins on the custom PCB. Wiring for the charging port will also mount to connector pins on the PCB. Wire length should be minimized to reduce the movement of internal components during shipping. 

\subsubsection{Power}

A battery is the best method of providing power for this product. In order to keep the user from having to repeatedly charge it and remove it from their fridge, a battery with a sufficiently large storage of milli-amp hours is necessary. Also included in the design is a method of charging the battery that does not require taking the device apart. The charging port will be able to charge the battery and keep the device powered so that users won't lose connection to their device.

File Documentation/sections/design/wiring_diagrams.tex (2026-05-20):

\subsection{Wiring Diagrams}

The wiring diagram for this design includes four pieces. The batter, microcontroller, load cell amplifier, and load cell. These parts all tie together with different wires connected to specific pins on each device. Each pin is labeled and each wire color coded. See Figure 7. 

\begin{figure}[H]
\centering

\caption{Example Wiring Diagram of Components Included in System Design}
\end{figure}

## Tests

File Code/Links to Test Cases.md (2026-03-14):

# All Test Files

Microcontroller
- [Weight sensor value translation](ESP32/HX711/main/test.c)
- [WiFi provisioning](ESP32/Setup/main/testing_wifi_provisioning.c)
- [Test server for demo](ESP32/test_server.py)

Webserver
- [Tests](web-server/src/test)

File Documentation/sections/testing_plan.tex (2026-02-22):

\section*{Testing Plan}

There are multiple sections of our design that require testing individually, then together as a whole. The following list represents the pathway we will take when testing our prototype segments.

\begin{itemize}
\item ESP Data Reporting
\item ESP Web Posting
\item Vercel Receiving and Displaying Data
\item Notification System
\item Phone App Integration
\item Prototype Setup Out-Of-The-Box
\end{itemize}

\subsection*{ESP Data Reporting}

The pressure sensors we use to build the base will output data to our ESP device. We want to be sure the ESP is capable of receiving this data and displaying it to the debug terminal, which will be IDF MONITOR. Once we can verify posting to the terminal we will move to the next stage of the data reporting testing.

With data being displayed properly, we can now use this to interpret what an empty versus full pitcher could be expected to weigh. The first test will include to test a known weight to make sure we get accuracate weight readings. 
Next we will ensure the that when there is no wight on the plate, the data will be read as 0 g.
Once this correct, we will move on to the more complex calibration with Pitcher + water.

We will use different types of containers given the variety of containers possible to be used by customers. We will test at different set water levels, and verify that the expected weight represents the following formula. 

\begin{equation}
W_{total} = W_{container} + V * \frac{g}{mL}
\end{equation}

Water weighs 1 gram per milliliter so if we keep track of the volume we put into the container we know exactly what to expect for output weight if we know the base weight of the container alone. 

\subsection*{ESP Web Posting}

To test this functionality the simplest way is to have the ESP send some sort of HTTP POST pointed at one of our local machines. We can receive and print this data and then move forward to testing sensor data output. 

With a working sensor we can trigger a POST request when an event happens. In this test case it could be picking up the container from the base which triggers a POST request with some set information. Upon successful receipt of this we can confirm that the HTTP method is working on a small scale and move to the next segment of testing. 

\subsection*{Vercel Receiving and Displaying Data}

Once we have confirmed the ESP can send POST requests to a local machine, the next stage is to implement that using Vercel. 

\subsection*{Notification System}

With data being sent out of the ESP, the next stage is to test if we can send a notification on some set event. For a test case this could be a container being placed on the device. The data sent as part of this notification could be a value representing the weight of the container, or an estimate of how much liquid is inside.

If we know how much liquid is inside the container when we place it on the base, it is easy to verify if the value we receive in the notification is the correct volume. Using different volumes we can create a table to show how close the reported volume was, and tweak our math to get it closer to accurate with different containers.

When we pass the fake data tests, we will compare the debug terminal and the notification water levels to ensure that it is correct.

\subsection*{Phone App Integration}

\subsection*{Prototype Setup Out-Of-The-Box}

In order to set up the prototype, the web app must connect to the ESP through its hosted soft AP and scan a QR code to enter the WiFi credentials. To test this, we will try to connect to the ESP on boot multiple times using different devices, such as iOS vs Android, and see if it is still able to connect through soft AP. We will also test different types of WiFi networks, such as mobile hotspots, traditional password-protected networks, and networks with outside authorization such as university WiFi.

The user must also calibrate the device by measuring the empty and full weights of the filter on the weight sensor. On the webapp, they will be given instructions step-by-step to do this. In order to test this process, we will give the device to a new user and see if they are able to clearly follow the instructions and calibrate the device correctly. We will also test robustness by intentionally disobeying the instructions, such as by weighing it empty both times, to see our device handle it.

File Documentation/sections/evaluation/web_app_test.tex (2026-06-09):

\subsection{Web Application Testing}

The web application testing plan verifies both the user-facing interface and the backend API that the web app, mobile app, and microcontroller share. 
Tests run locally with mocked authentication, database responses, and network calls so behavior can be checked without live hardware or a production database. 
Frontend tests use a component test library to render pages and simulate user actions. The backend tests invoke API handlers directly and assert on status codes, response bodies, and error handling. 
All automated tests live under the \texttt{test/} directory in the web-server source tree and are executed with a single test runner command.

\subsubsection{Frontend and User Interface}

Frontend tests focus on the two panels: the Account Settings page and the Setup Guide page. These tests confirm that the application shell renders both sections, 
that unauthenticated users see a sign-in form, and that authenticated users see account information loaded from the API.
For the Settings page, tests cover the full signed-out and signed-in flows. When no session exists, the page shows a loading state and then the sign-in form.
Invalid credentials display an error message from the authentication service. After a successful sign-in, the page lists the user's groups and devices, 
handles API load failures gracefully, and updates when the session changes. Users can sign out, which clears displayed account data. 
Security actions are also verified: account deletion requires confirmation and only proceeds when the user accepts, and cancellation leaves the session intact.
The Setup Guide page is tested at the layout level: both the Account and Setup Guide headings appear together so users can read setup instructions alongside account management. 
Because the guide is largely static content, testing emphasizes correct rendering rather than dynamic data flows.

\subsubsection{Backend API and Authentication}

The web server also hosts REST endpoints used by the mobile app and the microcontroller. A separate set of tests validates server-side logic in isolation. 
Each test calls an API handler with a mock request and inspects the HTTP response, using stand-in database and auth clients so tests do not depend on external services.
Authentication tests verify that user requests without a valid Bearer token are rejected, that device ingestion requests require valid device credentials, 
and that invalid or replayed tokens are not accepted. These checks protect endpoints that read or write user and device data.
Group-management tests cover listing, creating, joining, renaming, and deleting groups, as well as updating calibration values and managing members (including role changes and removal). 
Tests include both successful paths and failure cases such as invalid invite codes, duplicate membership, missing permissions, and database errors.
Device tests verify listing a user's registered devices and the BLE registration flow used during mobile provisioning, including linking a new device to an existing group and handling missing or invalid input.
The sensor ingestion endpoint is tested for correct handling of POST requests, device authentication, weight-to-level conversion using calibration data, storage of readings, 
and optional low-water push notifications. Profile endpoints are tested for reading and updating user information, signing out all active sessions, and deleting an account.
Supporting utility modules, such as push-notification delivery and shared group logic, are also tested so edge cases (empty inputs, network failures, malformed responses) do not propagate into production handlers.

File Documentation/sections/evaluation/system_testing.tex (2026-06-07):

%%%%%%%%%%%%%%%%%%%%%%%%%%%%%%%%%%%%%%%%%%%%%%%%%%%%%%%%%%%%%%%%%%%%%%%%%%%%%%%%%%%%%%%

\subsection{System Testing}

\subsection*{WiFi Capability \& Provisioning}

\noindent{}\textbf{Objective:}
Verify that the Smart Water Pitcher Base can be provisioned with WiFi credentials and
reliably connect to a wireless network for communication with external devices.\\

\noindent{}\textbf{Test Cases:}
\begin{itemize}
\setlength{\itemsep}{0pt}
\setlength{\parskip}{0pt}
\setlength{\parsep}{0pt}
\setlength{\topsep}{0pt}

    \item \textbf{Initial Provisioning Test}
    \begin{itemize}
        \item \textbf{Procedure:} Power on the device in provisioning mode and use the setup interface to enter WiFi SSID and password.
        \item \textbf{Expected Result:} The device stores the credentials and connects to the specified network.
        \item \textbf{Prototype Result:} Pass
    \end{itemize}

    \item \textbf{Automatic Reconnection Test}
    \begin{itemize}
        \item \textbf{Procedure:} Power cycle the device after provisioning has been completed.
        \item \textbf{Expected Result:} The device reconnects automatically to the saved WiFi network without requiring reconfiguration.
        \item \textbf{Prototype Result:} Pass
    \end{itemize}

    \item \textbf{Invalid Credential Handling}
    \begin{itemize}
        \item \textbf{Procedure:} Attempt provisioning using an incorrect WiFi password.
        \item \textbf{Expected Result:} The device fails to connect and indicates a connection error or returns to provisioning mode.
        \item \textbf{Prototype Result:} Pass
    \end{itemize}

    \item \textbf{Network Loss Recovery}
    \begin{itemize}
        \item \textbf{Procedure:} Disconnect the router or move the device out of range, then restore the network.
        \item \textbf{Expected Result:} The device automatically reconnects once the network becomes available.
        \item \textbf{Prototype Result:} Pass
    \end{itemize}

\end{itemize}

\noindent{}\textbf{Success Criteria:}
The device can be provisioned successfully, stores WiFi credentials correctly, and maintains
reliable connectivity to the network during normal operation.

%%%%%%%%%%%%%%%%%%%%%%%%%%%%%%%%%%%%%%%%%%%%%%%%%%%%%%%%%%%%%%%%%%%%%%%%%%%%%%%%%%%%%%%

\subsection*{Group Management Test Plan}

\noindent{}\textbf{Objective:}
Verify that users can join and leave a group associated with a specific Smart Water Pitcher Base and that group membership is updated correctly in the application.\\

\noindent{}\textbf{Test Cases:}
\begin{itemize}
\setlength{\itemsep}{0pt}
\setlength{\parskip}{0pt}
\setlength{\parsep}{0pt}
\setlength{\topsep}{0pt}

\item \textbf{Join Group Test}
\begin{itemize}
\item \textbf{Procedure:} A user enters the group code or selects the filter in the application to join its group.
\item \textbf{Expected Result:} The user is successfully added to the group and gains access to the filter’s information.
\item \textbf{Prototype Result:} Pass
\end{itemize}

\item \textbf{Leave Group Test}
\begin{itemize}
\item \textbf{Procedure:} A user selects the option to leave the group in the application.
\item \textbf{Expected Result:} The user is removed from the group and no longer sees the filter’s data.
\item \textbf{Prototype Result:} Pass
\end{itemize}

\item \textbf{Multiple User Membership Test}
\begin{itemize}
\item \textbf{Procedure:} Multiple users join the same filter group from different devices.
\item \textbf{Expected Result:} All users are successfully added and can view the same filter information.
\item \textbf{Prototype Result:} Pass
\end{itemize}

\item \textbf{Invalid Group Handling}
\begin{itemize}
\item \textbf{Procedure:} Attempt to join a group using an invalid or non-existent group code.
\item \textbf{Expected Result:} The application rejects the request and displays an error message.
\item \textbf{Prototype Result:} Pass
\end{itemize}

\item \textbf{Rename Group Test}
\begin{itemize}
\item \textbf{Procedure:} Attempt to rename a group.
\item \textbf{Expected Result:} The group name is updated correctly for all users.
\item \textbf{Prototype Result:} Pass
\end{itemize}

\item \textbf{Delete Group Test}
\begin{itemize}
\item \textbf{Procedure:} Attempt to delete a group.
\item \textbf{Expected Result:} The group is removed for all users.
\item \textbf{Prototype Result:} Pass
\end{itemize}

\end{itemize}

\noindent{}\textbf{Success Criteria:}
Users can reliably join and leave groups associated with a filter, and group membership is accurately reflected across all devices.

%%%%%%%%%%%%%%%%%%%%%%%%%%%%%%%%%%%%%%%%%%%%%%%%%%%%%%%%%%%%%%%%%%%%%%%%%%%%%%%%%%%%%%%%

\subsection*{Water Level Monitoring and Display}

\noindent{}\textbf{Objective:}
Verify that the Smart Water Pitcher Base accurately measures the water level and correctly displays this information to users through the application.\\

\noindent{}\textbf{Test Cases:}
\begin{itemize}
\setlength{\itemsep}{0pt}
\setlength{\parskip}{0pt}
\setlength{\parsep}{0pt}
\setlength{\topsep}{0pt}

\item \textbf{Sensor Calibration Test}
\begin{itemize}
\item \textbf{Procedure:} Empty the container and select the “Empty” calibration option in the application. Then fill the container to the maximum level and select the “Full” calibration option.
\item \textbf{Expected Result:} The system stores the calibration values and uses them to correctly scale future sensor readings to the displayed water level.
\item \textbf{Prototype Result:} Pass
\end{itemize}

\item \textbf{Water Level Accuracy Test}
\begin{itemize}
\item \textbf{Procedure:} Fill the container to several known levels and record the value reported by the Smart Water Pitcher Base.
\item \textbf{Expected Result:} The reported level closely matches the actual water level within an acceptable error range.
\item \textbf{Prototype Result:} Pass
\end{itemize}

\item \textbf{Empty and Full Level Test}
\begin{itemize}
\item \textbf{Procedure:} Test the system with the container completely empty and completely full.
\item \textbf{Expected Result:} The application correctly displays the minimum and maximum water levels.
\item \textbf{Prototype Result:} Pass
\end{itemize}

\item \textbf{Data Transmission Test}
\begin{itemize}
\item \textbf{Procedure:} Verify that sensor readings are transmitted from the Smart Water Filter Base to the application over WiFi.
\item \textbf{Expected Result:} The application consistently displays the most recent water level data.
\item \textbf{Prototype Result:} Pass
\end{itemize}

\item \textbf{Transmission Speed Test}
\begin{itemize}
\item \textbf{Procedure:} Verify that sensor readings are transmitted from the Smart Water Filter Base to the application within 5 seconds.
\item \textbf{Expected Result:} The application consistently reports water level data within 5 seconds of a physical change.
\item \textbf{Prototype Result:} Pass
\end{itemize}

\end{itemize}

\noindent{}\textbf{Success Criteria:}
The Smart Water Pitcher Base accurately measures water level and reliably communicates this information to the user interface.

%%%%%%%%%%%%%%%%%%%%%%%%%%%%%%%%%%%%%%%%%%%%%%%%%%%%%%%%%%%%%%%%%%%%%%%%%%%%%%%%%%%%%%%%%

\subsection*{Notification System Test Plan}

\noindent{}\textbf{Objective:}
Verify that the system generates and delivers notifications to users when specific conditions occur, such as low water levels or filter maintenance requirements.\\

\noindent{}\textbf{Test Cases:}
\begin{itemize}
\setlength{\itemsep}{0pt}
\setlength{\parskip}{0pt}
\setlength{\parsep}{0pt}
\setlength{\topsep}{0pt}

\item \textbf{Low Water Level Notification}
\begin{itemize}
\item \textbf{Procedure:} Reduce the water level below the defined threshold.
\item \textbf{Expected Result:} A notification is generated and displayed to users indicating that the water level is low.
\item \textbf{Prototype Result:} Pass
\end{itemize}

\item \textbf{Notification Delivery Test}
\begin{itemize}
\item \textbf{Procedure:} Trigger a notification event and verify that it appears in the application interface.
\item \textbf{Expected Result:} The notification is delivered and visible to the user.
\item \textbf{Prototype Result:} Partial pass (Apple Developer Kit prevents full notification access without payment)
\end{itemize}

\item \textbf{Multiple User Notification Test}
\begin{itemize}
\item \textbf{Procedure:} Trigger a notification event while multiple users are members of the same group.
\item \textbf{Expected Result:} All users in the group receive the notification.
\item \textbf{Prototype Result:} Pass
\end{itemize}

\end{itemize}

\noindent{}\textbf{Success Criteria:}
Notifications are reliably generated and delivered to all relevant users when system conditions trigger an alert.

%%%%%%%%%%%%%%%%%%%%%%%%%%%%%%%%%%%%%%%%%%%%%%%%%%%%%%%%%%%%%%%%%%%%%%%%%%%%%%%%%%%%%%%%%

\subsection*{Miscellaneous Functionality Tests}

\noindent{}\textbf{Test Cases:}
\begin{itemize}
\setlength{\itemsep}{0pt}
\setlength{\parskip}{0pt}
\setlength{\parsep}{0pt}
\setlength{\topsep}{0pt}

\item \textbf{Environmental Humidity Test}
\begin{itemize}
\item \textbf{Procedure:} Place the Smart Water Pitcher Base in an environment with known humidity levels similar to a typical indoor refrigerator.
\item \textbf{Expected Result:} The smart base continues to function correctly over long periods of use.
\item \textbf{Prototype Result:} Untested, prototype is not humidity proof
\end{itemize}

\item \textbf{Battery and Power Test}
\begin{itemize}
\item \textbf{Procedure:} Drain the smart base's battery and recharge it.
\item \textbf{Expected Result:} The smart base resumes functionality after being recharged.
\item \textbf{Prototype Result:} Pass
\end{itemize}

\item \textbf{Battery Duration Test}
\begin{itemize}
\item \textbf{Procedure:} Measure how long the battery lasts under normal usage conditions.
\item \textbf{Expected Result:} The smart base remains powered for 3 months without recharge.
\item \textbf{Prototype Result:} Fail, prototype's MCU uses much more power than the actual design's custom PCB
\end{itemize}

\end{itemize}

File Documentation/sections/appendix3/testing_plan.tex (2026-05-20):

\subsection{Overview}

There are multiple sections of our design that require testing individually, then together as a whole. The following list represents the pathway we will take when testing our prototype segments.

\begin{itemize}
\item MCU Data Reporting
\item MCU Web Posting
\item Vercel Receiving and Displaying Data
\item Notification System
\item Phone App Integration
\item Prototype Setup Out-Of-The-Box
\end{itemize}

\subsubsection*{MCU Data Reporting}

The pressure sensors we use to build the base will output data to our MCU device. We want to be sure the MCU is capable of receiving this data and displaying it to the debug terminal. Once we can verify posting to the terminal we will move to the next stage of the data reporting testing.

With data being displayed properly, we can now use this to interpret what an empty versus full pitcher could be expected to weigh. The first test will include to test a known weight to make sure we get accuracate weight readings. 
Next we will ensure the that when there is no wight on the plate, the data will be read as 0g.
Once this correct, we will move on to the more complex calibration with Pitcher + water.

We will use different types of containers given the variety of containers possible to be used by customers. We will test at different set water levels, and verify that the expected weight represents the following formula. 

\begin{equation}
W_{total} = W_{container} + V * \frac{g}{mL}
\end{equation}

Water weighs 1 gram per milliliter so if we keep track of the volume we put into the container we know exactly what to expect for output weight if we know the base weight of the container alone. 

\subsubsection*{MCU Web Posting}

To test this functionality the simplest way is to have the MCU send some sort of HTTPS POST pointed at one of our local machines. We can receive and print this data and then move forward to testing sensor data output. 

With a working sensor we can trigger a POST request when an event happens. In this test case it could be picking up the container from the base which triggers a POST request with some set information. Upon successful receipt of this we can confirm that the HTTPS method is working on a small scale and move to the next segment of testing. 

\subsubsection*{Notification System}

With data being sent out of the MCU, the next stage is to test if we can send a notification on some set event. For a test case this could be a container being placed on the device. The data sent as part of this notification could be a value representing the weight of the container, or an estimate of how much liquid is inside.

If we know how much liquid is inside the container when we place it on the base, it is easy to verify if the value we receive in the notification is the correct volume. Using different volumes we can create a table to show how close the reported volume was, and tweak our math to get it closer to accurate with different containers.

When we pass the fake data tests, we will compare the debug terminal and the notification water levels to ensure that it is correct.

\subsubsection*{Phone App Integration}

With the notification system working, we can now test if the notifications are being sent to the phone app. We will use the same test case as before, which is placing a container on the base. We will verify that the notification is received on the phone and that the data in the notification is correct.

We will also verify that the current fill level of the container is being displayed on the phone app. We will test this by placing a container with a known volume of liquid on the base and verifying that the fill level displayed on the phone app is correct.

\subsubsection*{Prototype Setup Out-Of-The-Box}

In order to set up the prototype, the web app must connect to the MCU through BLE and scan a QR code to enter the WiFi credentials. To test this, we will try to connect to the MCU on boot multiple times using different devices and see if it is still able to connect. We will also test different types of WiFi networks, such as mobile hotspots, traditional password-protected networks, and networks with outside authorization such as university WiFi.

The user must also calibrate the device by measuring the empty and full weights of the filter on the weight sensor. On the mobile app, they will be given instructions step-by-step to do this. In order to test this process, we will give the device to a new user and see if they are able to clearly follow the instructions and calibrate the device correctly. We will also test robustness by intentionally disobeying the instructions, such as by weighing it empty both times, to see our device handle it.

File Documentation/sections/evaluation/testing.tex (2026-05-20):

\subsection{Testing}

Testing is a critical phase in the development of the smart water-level monitor, ensuring that all components function correctly 
and integrate seamlessly. We will conduct testing at multiple levels, including unit testing for individual modules, integration testing 
for combined components, and end-to-end testing for the entire system.

Our local tests for the MCU are linked inside the repository under Code/'Links to Test Cases.md'.

% Write about testing of the esp code, could move the HX711_test text here
% Needs to include the unit tests of for the esp wifi connection, data sensing, and data transmission.
\subsubsection{Microcontroller}

When creating the tests for the microcontroller code, it's important to consider what a user behavior might look like, but also important to understand what level the behavior could get to. How likely is it that a user is putting a full filter on, then an empty one, and back to full, in a matter of milliseconds? How capable is this controller of dealing with sharp spikes and changes? The testing plan covers both simulated behavior for quick and sharp event behavior, as well as a more practical testing plan for typical user behavior. 

In order to verify the function of the code reading from the Wheatstone bridge sensor, we must verify that the logic itself works the way we think. There are multiple parts that require logical verification. 

First, the sensor data will come in with some small variation depending on where the weight is placed on the base, and because ADC values can vary slightly  without any other input. Sensor reading code must also account for the fact that data can change very quickly, so testing the logic through repeated, high frequency changes, can help show its robustness. There is also the issue of whether data inputted to the code is read in correctly through the bit shift operations, so checking the shift operations for correctness is important. 

Testing the microcontroller code in this design involves a separate file that contains simulated amplifier behavior. This behavior is passed into the functions used on the microcontroller, which provide an output back to the test file. These outputs are verified against expected outputs and if they are the same or within a certain level of tolerance, then we can say the code passed the tests. 

To test the behavior that would be seen for a typical user, we must have standard objects that we use for the different levels of weight. A large weight, a small weight, and no weight are the simplest form of this. For example, fitting with the project, say a water filter with 100mL of water, versus a water filter with 3L of water. These two objects have drastically different weights so putting it on the scale and viewing how the code responds could represent a typical user behavior of taking the empty filter, filling it, and returning it to the base. 

\subsubsection{Mobile Application}

When testing the mobile application, we focus on both normal use and edge cases. A normal flow is a user opening the app, calibrating once, and checking the water level. Edge cases include repeated page refreshes, pressing calibration buttons several times, or receiving rapid updates from the sensor. We also test edge cases like if the water level goes beyond expected limits. We want to ensure the app can handle these scenarios without crashing or showing incorrect information.

For frontend unit tests, we check important UI parts one at a time, such as calibration buttons, status messages, and notification prompts. These tests verify that components render correctly, user clicks update state as expected, and displayed values stay consistent with incoming data. Because sensor readings can change often, we also check that the UI updates smoothly and does not show stale values.

For integration testing, we verify that the frontend and backend communicate correctly. The app sends requests for actions like token registration and sensor data ingestion, and we check that the API returns the expected results. We test both valid and invalid payloads to make sure errors are handled clearly and data is not updated incorrectly.

Finally, end-to-end tests cover complete user workflows from start to finish. These include loading the app, calibrating, monitoring water-level changes, and receiving notifications at threshold events. If these tests pass under both normal and adverse conditions, we can conclude the mobile application meets functional testing goals.

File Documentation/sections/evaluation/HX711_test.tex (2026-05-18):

\subsection{Testing the Amplifier}

To test the code written for this project, we first had to create a simulated version of the sensor. Regardless of what the sensor reports we want to make sure that all of our math and interpretation of incoming data is correct. To do this, the functions were adapted to either take input from GPIO pins, or from a specific test file. 

\subsubsection{Test File}

Inside the test file are adapted versions of each function used by the main HX711 file. These include the following:

\begin{itemize}
\item hx711\_set\_sck
\item hx711\_get\_dout
\item read\_raw
\item get\_raw\_weight
\item tare
\item get\_grams
\end{itemize}

With each of these functions, the test file simulates reading data from the sensor. This code was created to simulate our selected load cell and amplifier combo. The design includes this amplifier. The code will need to be adapted for any other amplifier that uses a different form of communication or a different packet structure. This code can be adapted by changing the functions specifically related to the amplifier labeled with HX711. 

\subsubsection{Simulated Data}

Using some set values defined at the top of the file including a hardcoded offset and scaling factor, the test file first sets the weight and tares it. Then based on a random number between 0 and 2, it sends either a 0, small weight, or large weight value. 

When the test file calls to the read weight functions, some small noise of $\pm1g$ is used simulate the variability of the sensor reading. The sensor sends data in 24 bit samples, so the test code also includes the 24 bit shifting. Once the simulated data is created, the main function compares it to the expected result. If it's within one gram of the expected low high or zero value, then the value passes. This tolerance is arbitrary for the testing and will be different for the production code.

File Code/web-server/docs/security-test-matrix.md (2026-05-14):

# Security Test Matrix

## Automated

- `test/api/_lib/auth.test.js`
  - Bearer parsing
  - Nested JWE + JWT verification
  - Replay rejection (`jti` reuse)

Run:

```bash
cd Code/web-server
npm run test:run
```

## Manual API verification checklist

1. **User JWT accepted**
   - Sign in from mobile/web and call `GET /api/app-state` with Bearer token.
   - Expect `200`.
2. **User JWT rejected**
   - Remove `Authorization` header.
   - Expect `401`.
3. **Device nested JWE/JWT accepted**
   - Call `POST /api/ingest` using valid nested token.
   - Expect `200` and insert row in `water_readings`.
4. **Replay blocked**
   - Replay same device token (`jti` unchanged).
   - Expect `401` replay rejection.
5. **Expired token blocked**
   - Use device/user token with past `exp`.
   - Expect `401`.
6. **Provision start/complete**
   - `POST /api/auth/provision-start` with user token returns `session_id` and `nonce`.
   - `POST /api/auth/provision-complete` stores `devices`, `device_credentials`, and `device_user_bindings`.
7. **Mobile refresh behavior**
   - Keep mobile app open on group/dashboard.
   - Submit valid ingest payload to server.
   - Confirm water level updates on the next refresh cycle.

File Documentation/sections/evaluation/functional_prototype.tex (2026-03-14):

% Go into a lot of detail on how our prototype works right now, include photographs

\subsection{Functional Prototype}
The prototype consists of weight sensor readings sent to an HTTP server via POST requests. The web application displays the latest measurements in a simple dashboard, allows users to calibrate the empty/full weights of the water pitcher, and has a notification feature that works on web browsers.

\subsubsection{Hardware}
The plates used above and below the load cell are made for functional prototype purposes to fit the need of measure weight readings rather than
handling various water filter pitchers. Temporary HTTP server made to display and mimick how data is shown/handled.

\subsubsection{Web Application}
The current web application uses a clean, single-page dashboard layout. It is currently hosted at \url{https://cse123a-project-6a3s.vercel.app/}. It shows the water level 
as both a percentage and a pitcher graphic. The pitcher graphic fills or empties based on the latest sensor reading, so users can quickly see how much water is left. A 
status message shows whether the water pitcher has water or is empty, and recent update details are shown to confirm data is being received correctly.\\

\begin{figure}[H]
\begin{center}
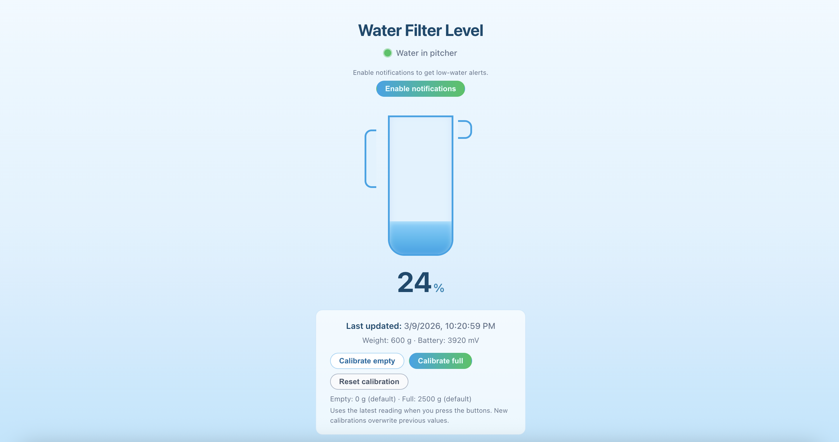
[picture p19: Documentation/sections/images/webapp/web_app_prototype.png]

\caption{Current Web Application Prototype Interface}
\label{web_app_prototype_eval}
\end{center}
\end{figure}

\noindent The web application works as follows:
\begin{enumerate}
	\item The microcontroller sends a new sensor reading to the server.
	\item The server stores the reading and makes it available to the dashboard.
	\item The dashboard fetches the latest value and updates the displayed percentage and water-level visual.
    \item Users can calibrate the system by pressing "Calibrate empty" when the latest value is an empty pitcher and "Calibrate full" when the latest value is a full pitcher.
	\item If the value is below the low-water threshold, the app sends a refill alert to users who enabled notifications.
\end{enumerate}

\noindent To calibrate the system, users will place an empty pitcher on the base and press "Calibrate empty" to set the empty value. Assuming the latest updated weight was 600 grams, you can see in 
figure \ref{web_app_calibrate_empty_eval} that under the calibrate buttons, empty is now set to 600 grams and the water level is set to 0\%.

\begin{figure}[H]
\begin{center}
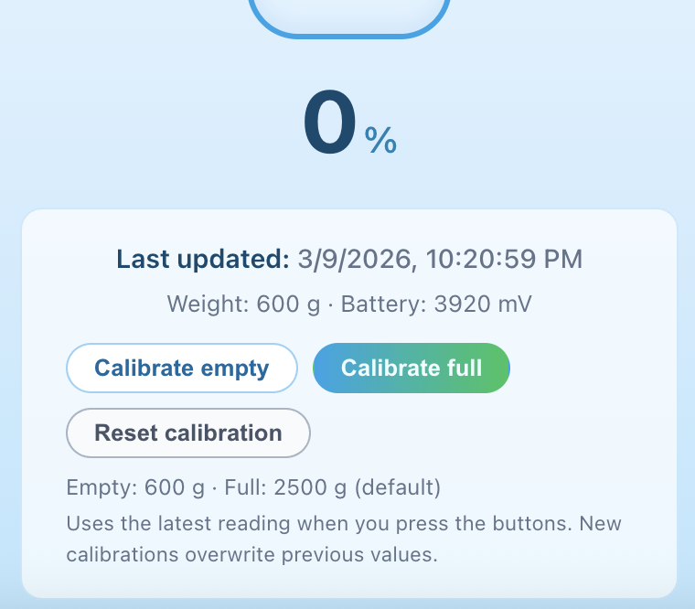
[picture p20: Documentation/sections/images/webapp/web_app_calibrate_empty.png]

\caption{Web Application After Calibrate Empty}
\label{web_app_calibrate_empty_eval}
\end{center}
\end{figure}

\noindent After calibrating the empty value, users can fill the pitcher to the full level and place it back on the base. Pressing "Calibrate full" will set the full value. 
Assuming the new latest updated weight was 1500 grams, you can see in figure \ref{web_app_calibrate_full_eval} that under the calibrate buttons, full is now set to 1500 grams and the water level will be adjusted to 100\%.
Users can also reset the calibration values at any time by simply pressing "Reset Calibration" button. This sets the empty and full values back to the default values, 0 grams and 2500 grams respectively.\\

\begin{figure}[H]
\begin{center}
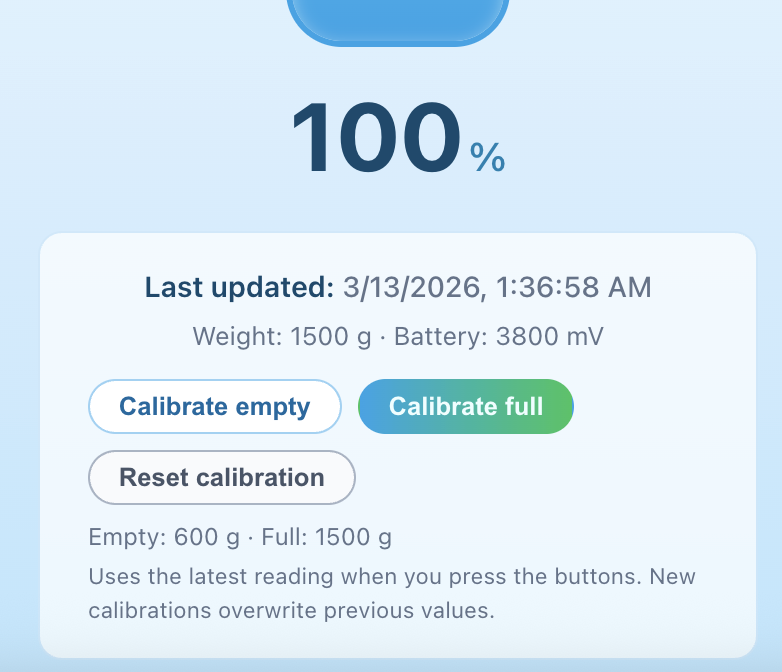
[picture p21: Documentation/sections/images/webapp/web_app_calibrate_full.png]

\caption{Web Application After Calibrate Full}
\label{web_app_calibrate_full_eval}
\end{center}
\end{figure}

\noindent To subscribe to notifications, users can click the "Enable Notifications" button. This will trigger a permission prompt in the browser as shown in figure \ref{web_app_enable_notif_prompt_eval}.

\begin{figure}[H]
\begin{center}
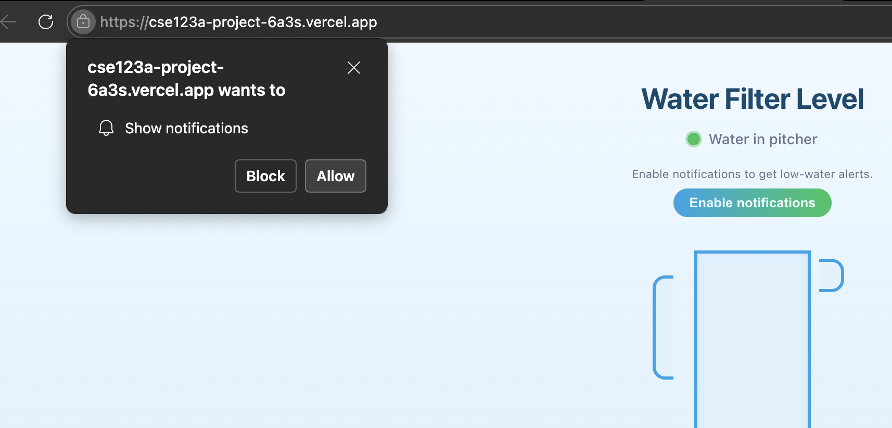
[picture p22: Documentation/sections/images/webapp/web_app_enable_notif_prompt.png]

\caption{Web Application Notification Permission Prompt}
\label{web_app_enable_notif_prompt_eval}
\end{center}
\end{figure}

\noindent If users allow notifications, they will be subscribed to receive alerts when the water level drops below the low-water threshold. The UI will also update to show that notifications are enabled 
under the water status indicator as shown in figure \ref{web_app_prototype_notif_enabled_eval}.

\begin{figure}[H]
\begin{center}
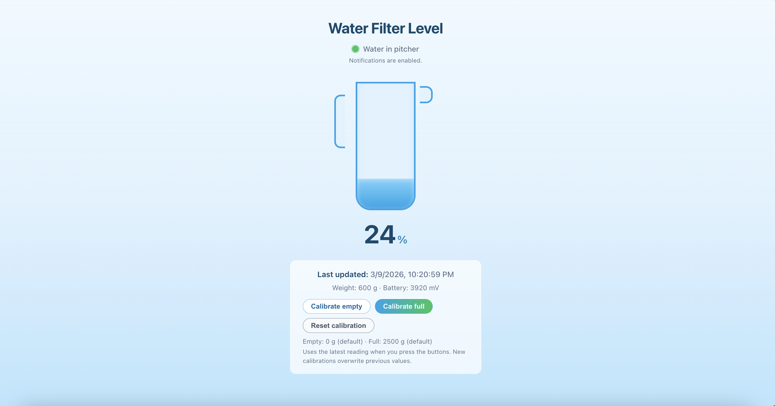
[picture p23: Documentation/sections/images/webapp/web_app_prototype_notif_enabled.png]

\caption{Web Application with Notifications Enabled}
\label{web_app_prototype_notif_enabled_eval}
\end{center}
\end{figure}

\noindent When the water level crosses the low-water threshold, which is currently set at 20\%, the browser will display a refill notification popup as shown in figure \ref{web_app_notif_popup_eval}.
Clicking on the notification will take users to the dashboard where they can see the current water level and recent updates.

\begin{figure}[H]
\begin{center}

\caption{Low-Water Notification Popup}
\label{web_app_notif_popup_eval}
\end{center}
\end{figure}

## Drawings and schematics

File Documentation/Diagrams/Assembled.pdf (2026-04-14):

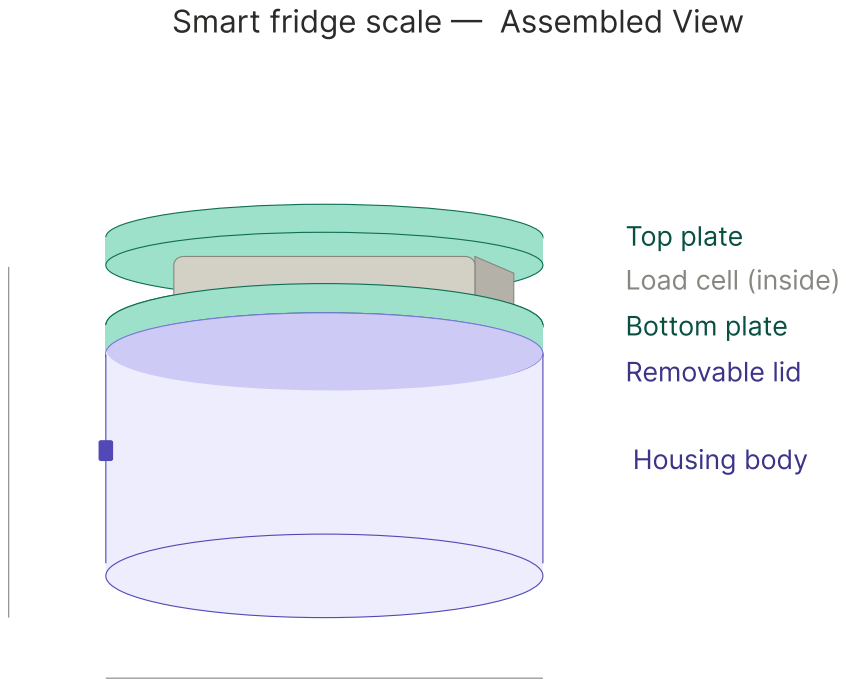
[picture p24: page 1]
Housing body

Smart fridge scale — Assembled View

Top plate
Load cell (inside)
Bottom plate
Removable lid

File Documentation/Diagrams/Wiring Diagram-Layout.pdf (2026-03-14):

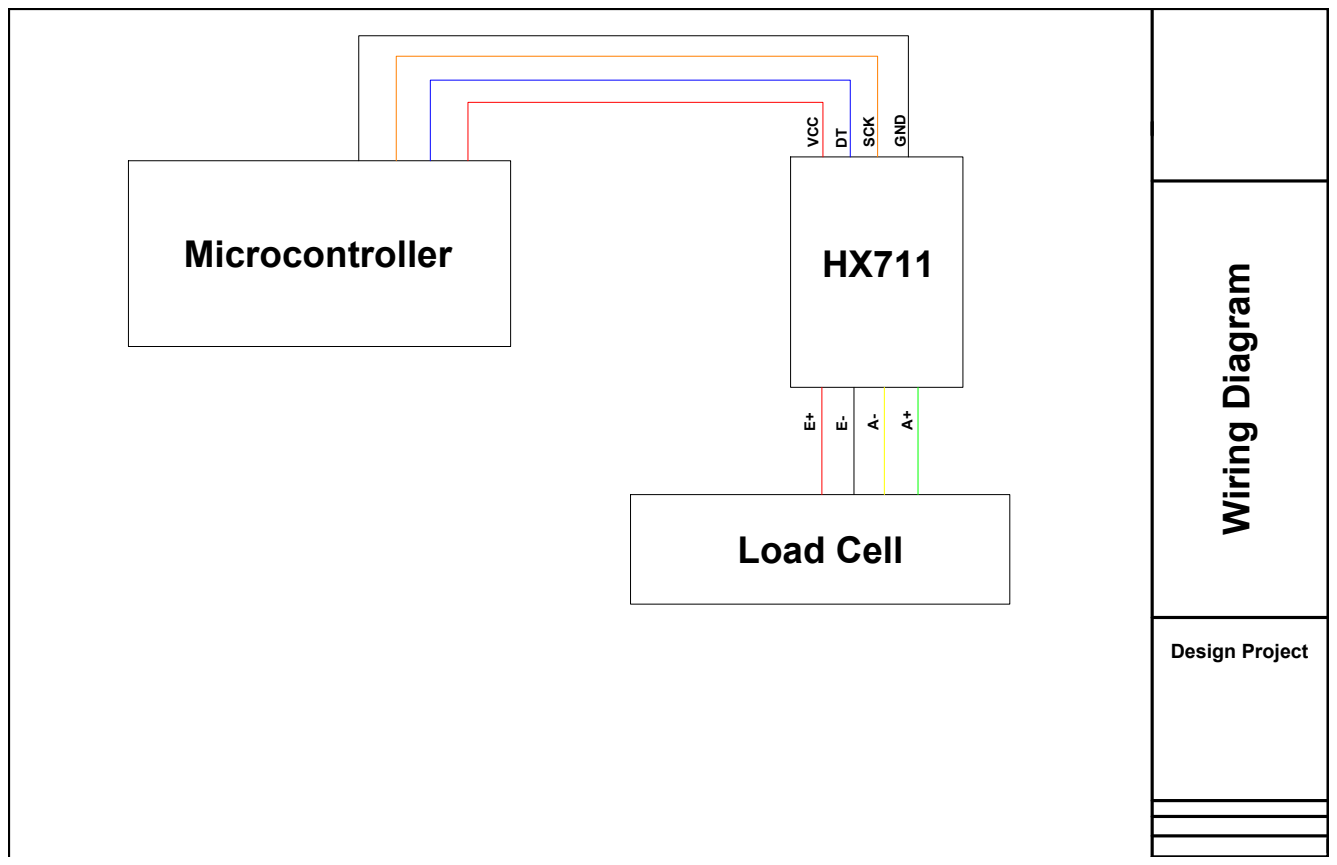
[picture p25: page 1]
Wiring Diagram; Design Project Microcontroller

GND Load Cell

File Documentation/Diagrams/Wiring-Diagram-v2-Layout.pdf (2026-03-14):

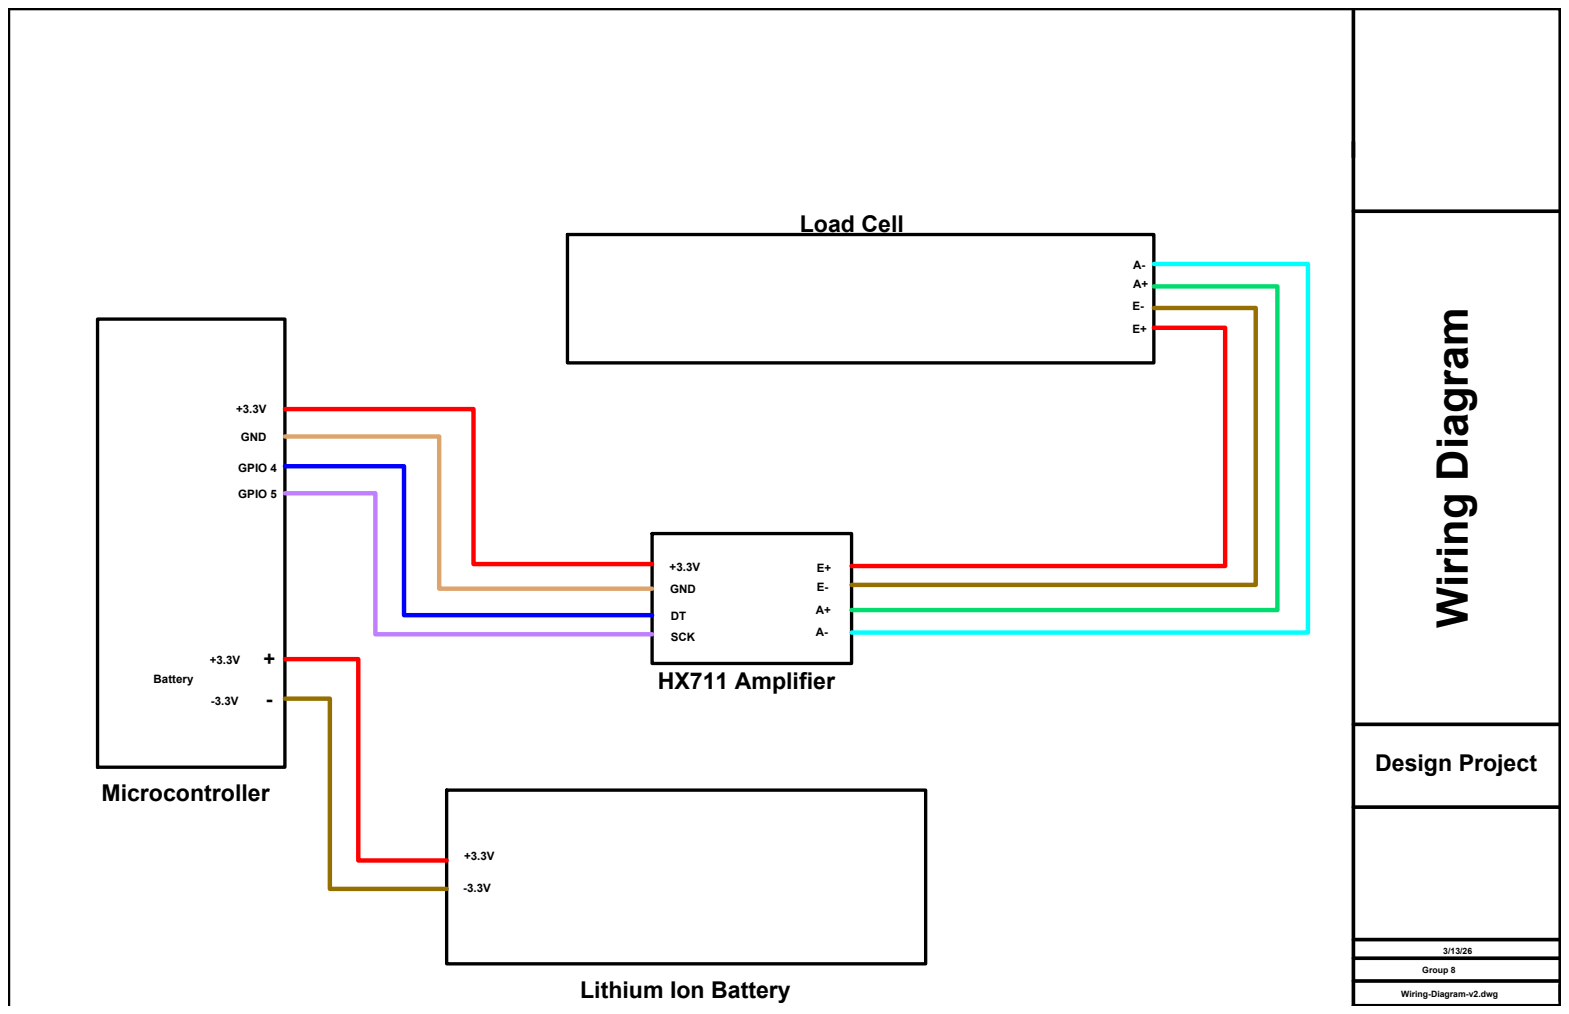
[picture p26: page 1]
+3.3V GND GND GPIO 4; DTSCK GPIO 5 Battery

Wiring Diagram Design Project 3/13/26 Group 8 Wiring-Diagram-v2.dwg Microcontroller Lithium Ion Battery HX711 Amplifier Load Cell +3.3V -3.3V +3.3V -3.3V

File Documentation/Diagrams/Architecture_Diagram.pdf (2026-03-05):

# Smart Filter System Architecture Diagram

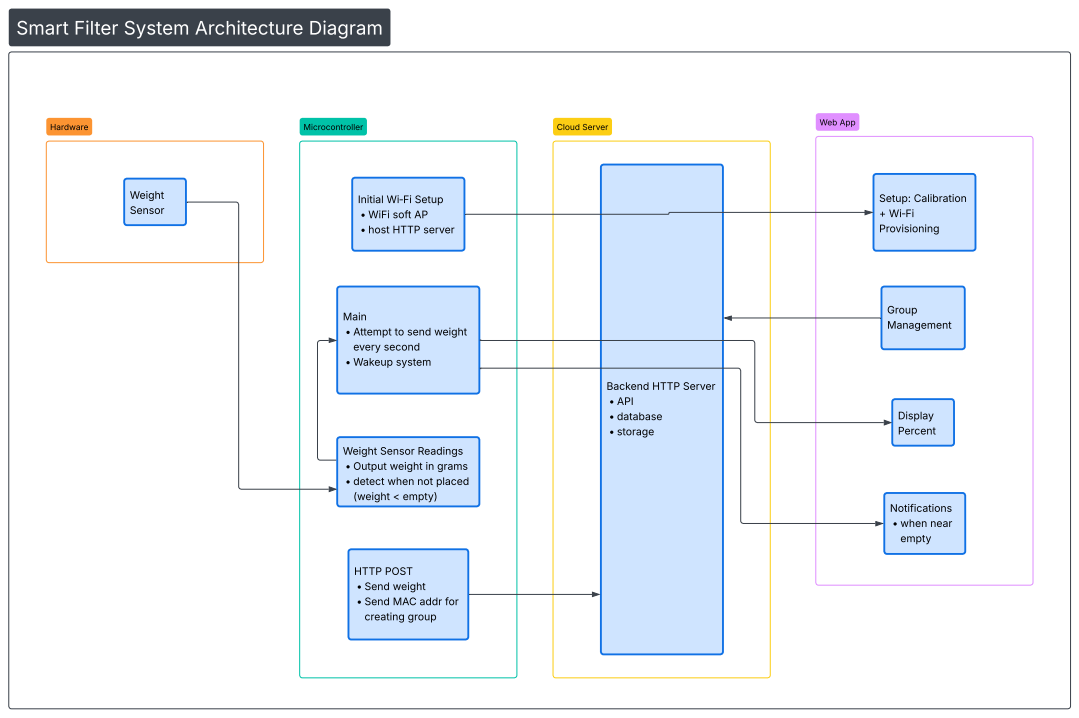
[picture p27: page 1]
Weight Sensor; Hardware; Cloud Server; Setup: Calibration + Wi?Fi Provisioning; Web App; Group Management; Display Percent; Microcontroller; Notifications - when near empty

Initial Wi?Fi Setup
- WiFi soft AP
- host HTTP server

Main
- Attempt to send weight
every second
- Wakeup system

Backend HTTP Server
- API
- database
- storage

Weight Sensor Readings
- Output weight in grams
- detect when not placed
(weight < empty)

HTTP POST
- Send weight
- Send MAC addr for
creating group

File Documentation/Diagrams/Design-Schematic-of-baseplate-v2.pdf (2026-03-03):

## Top View

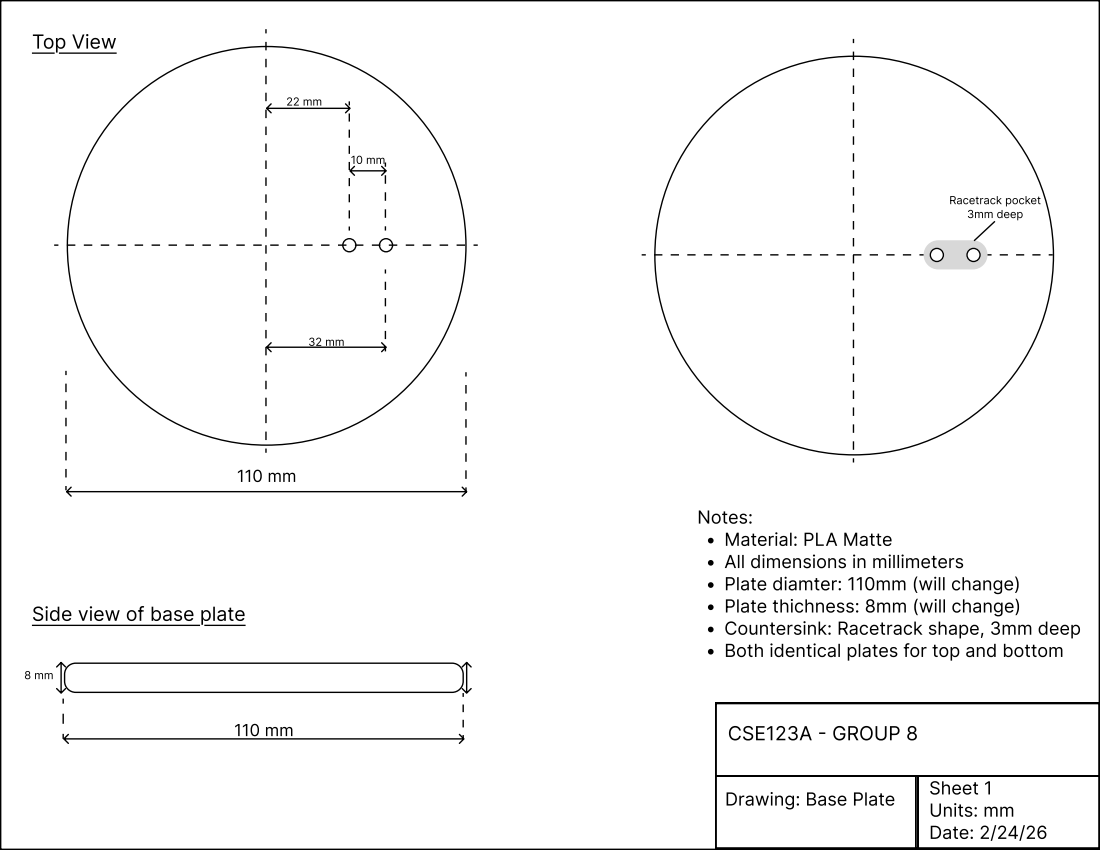
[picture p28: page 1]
CSE123A - GROUP 8; Drawing: Base Plate; Sheet 1(Units: mm Date: 2/24/26

Racetrack pocket(3mm deep

Notes: Material: PLA Matte All dimensions in millimeters Plate diamter: 110mm (will change) Plate thichness: 8mm (will change) Countersink: Racetrack shape, 3mm deep Both identical plates for top and bottom

Side view of base plate

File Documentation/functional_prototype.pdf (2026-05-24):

# Smart Water Pitcher Base

Assembly | System Block Diagram

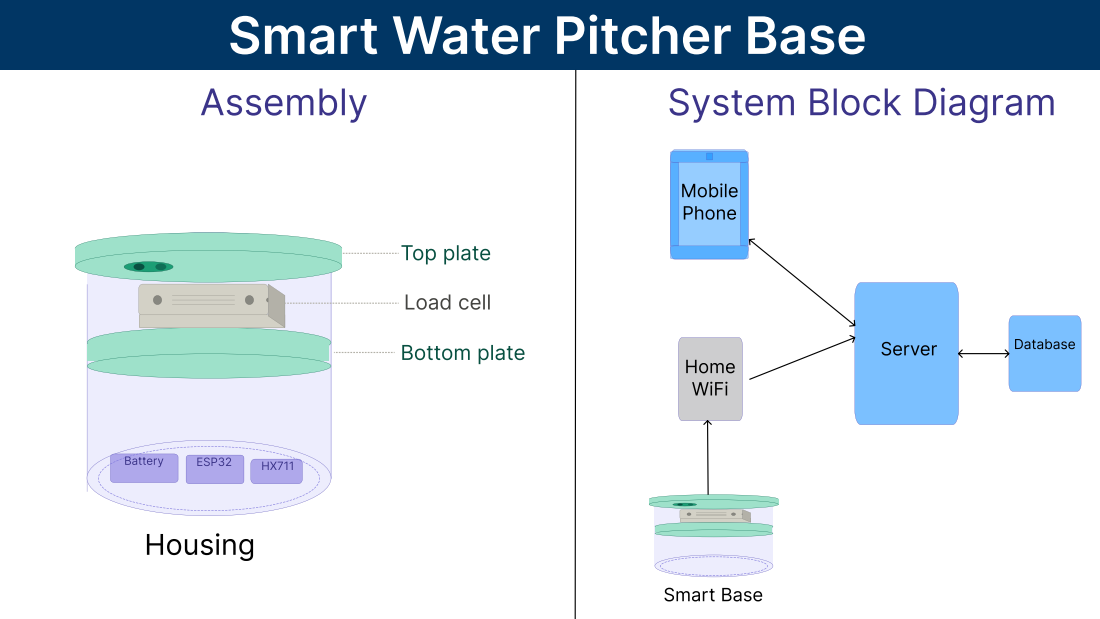
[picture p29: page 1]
Mobile; Phone; Top plate; Load cell; Bottom plate; Database Server Home; WiFi; Battery; ESP32; Housing; Smart Base

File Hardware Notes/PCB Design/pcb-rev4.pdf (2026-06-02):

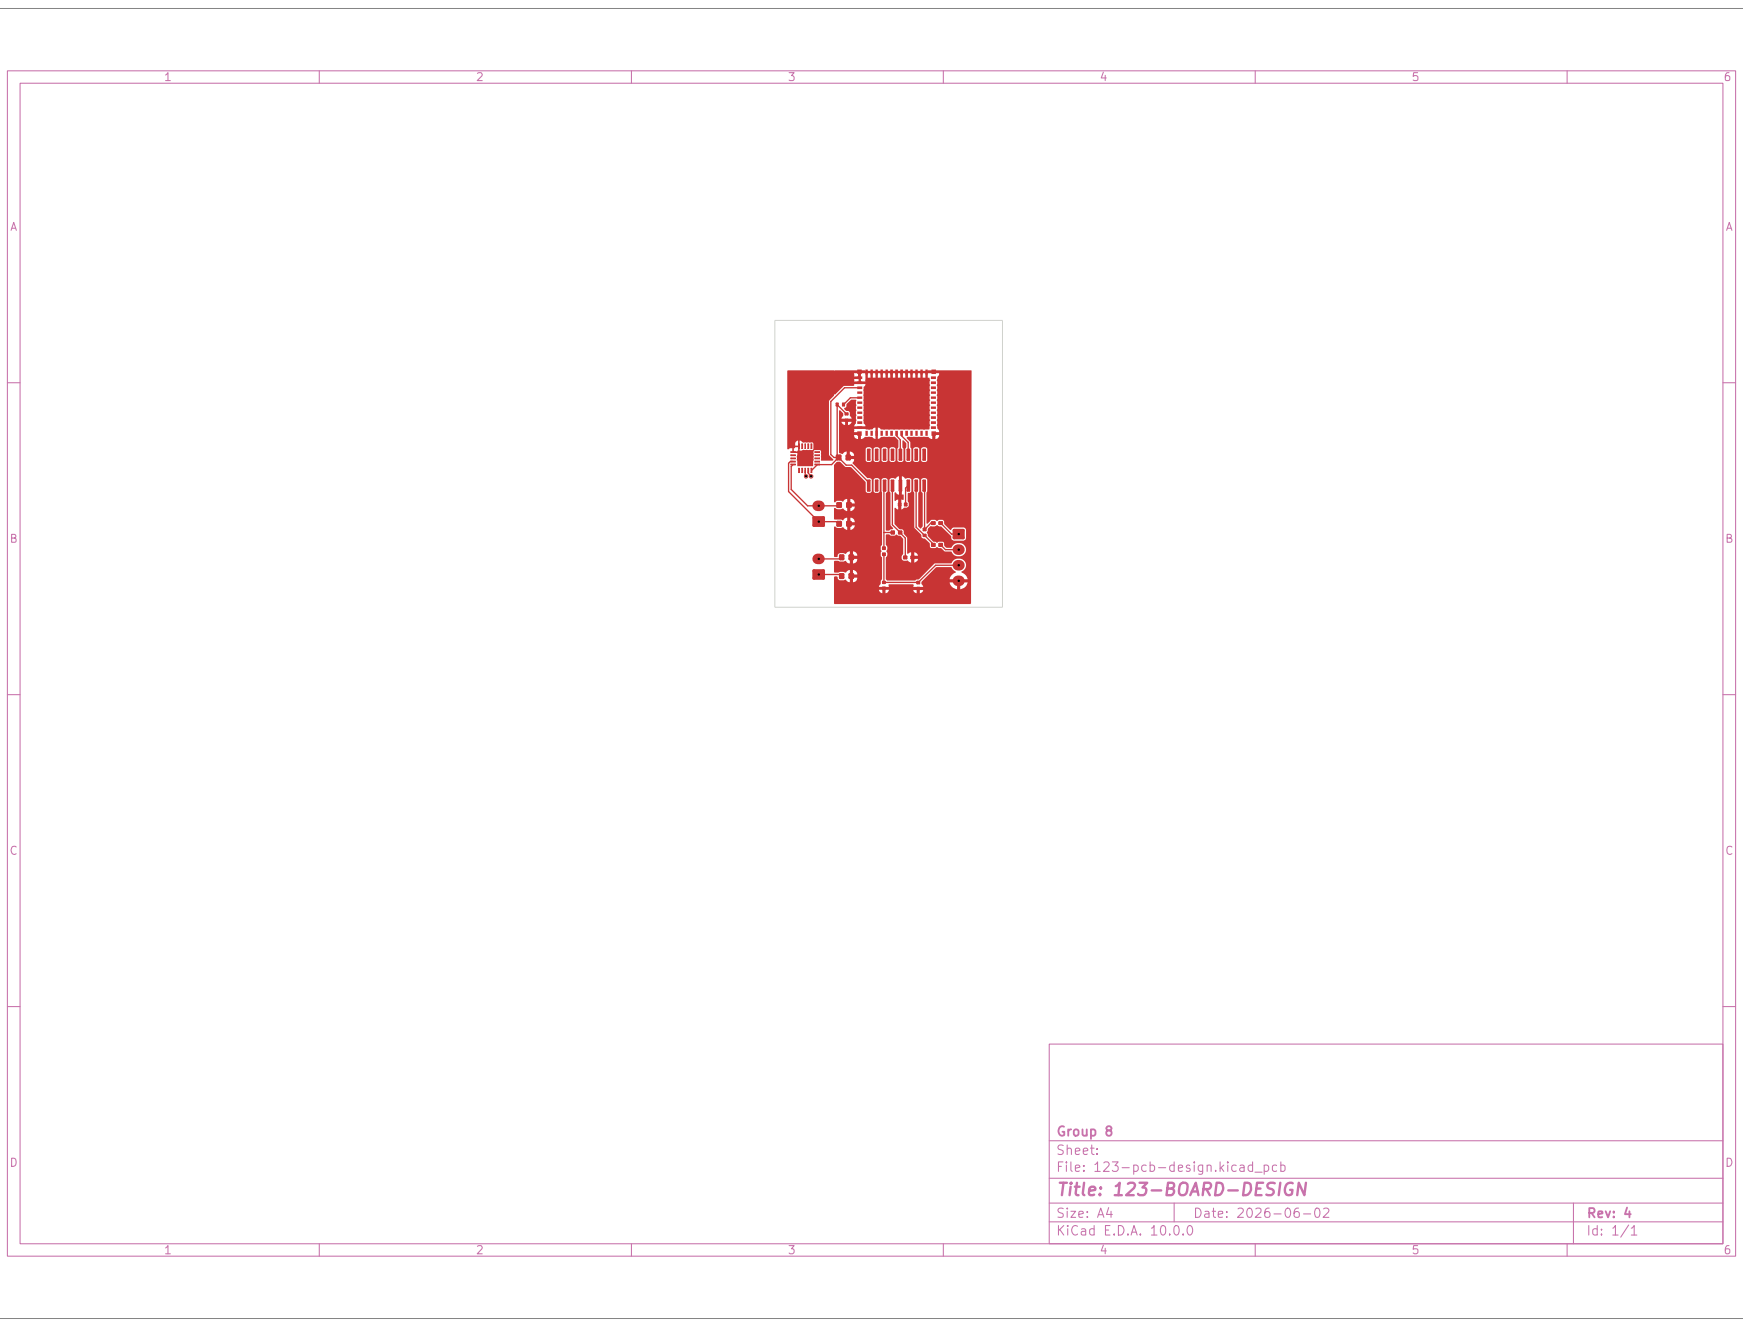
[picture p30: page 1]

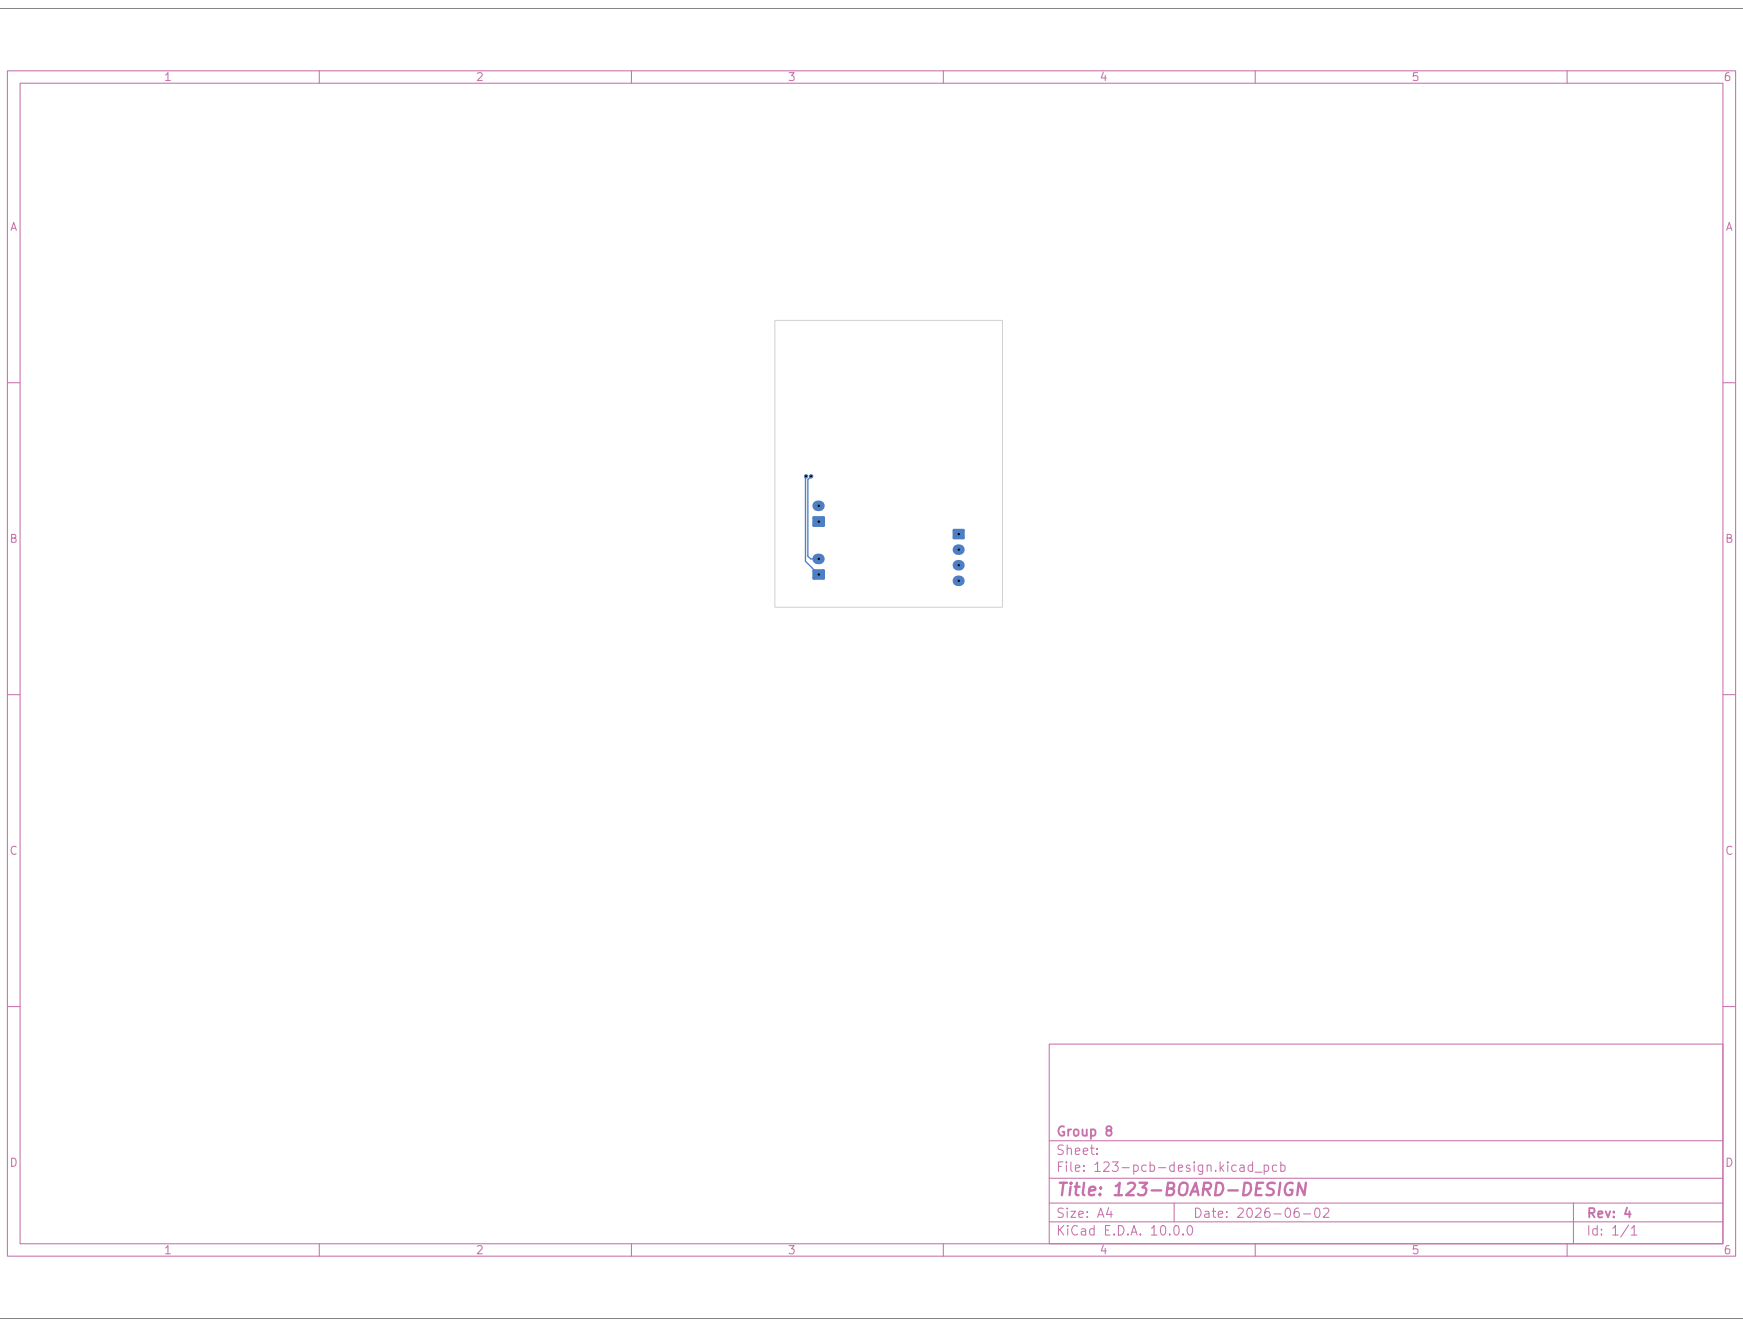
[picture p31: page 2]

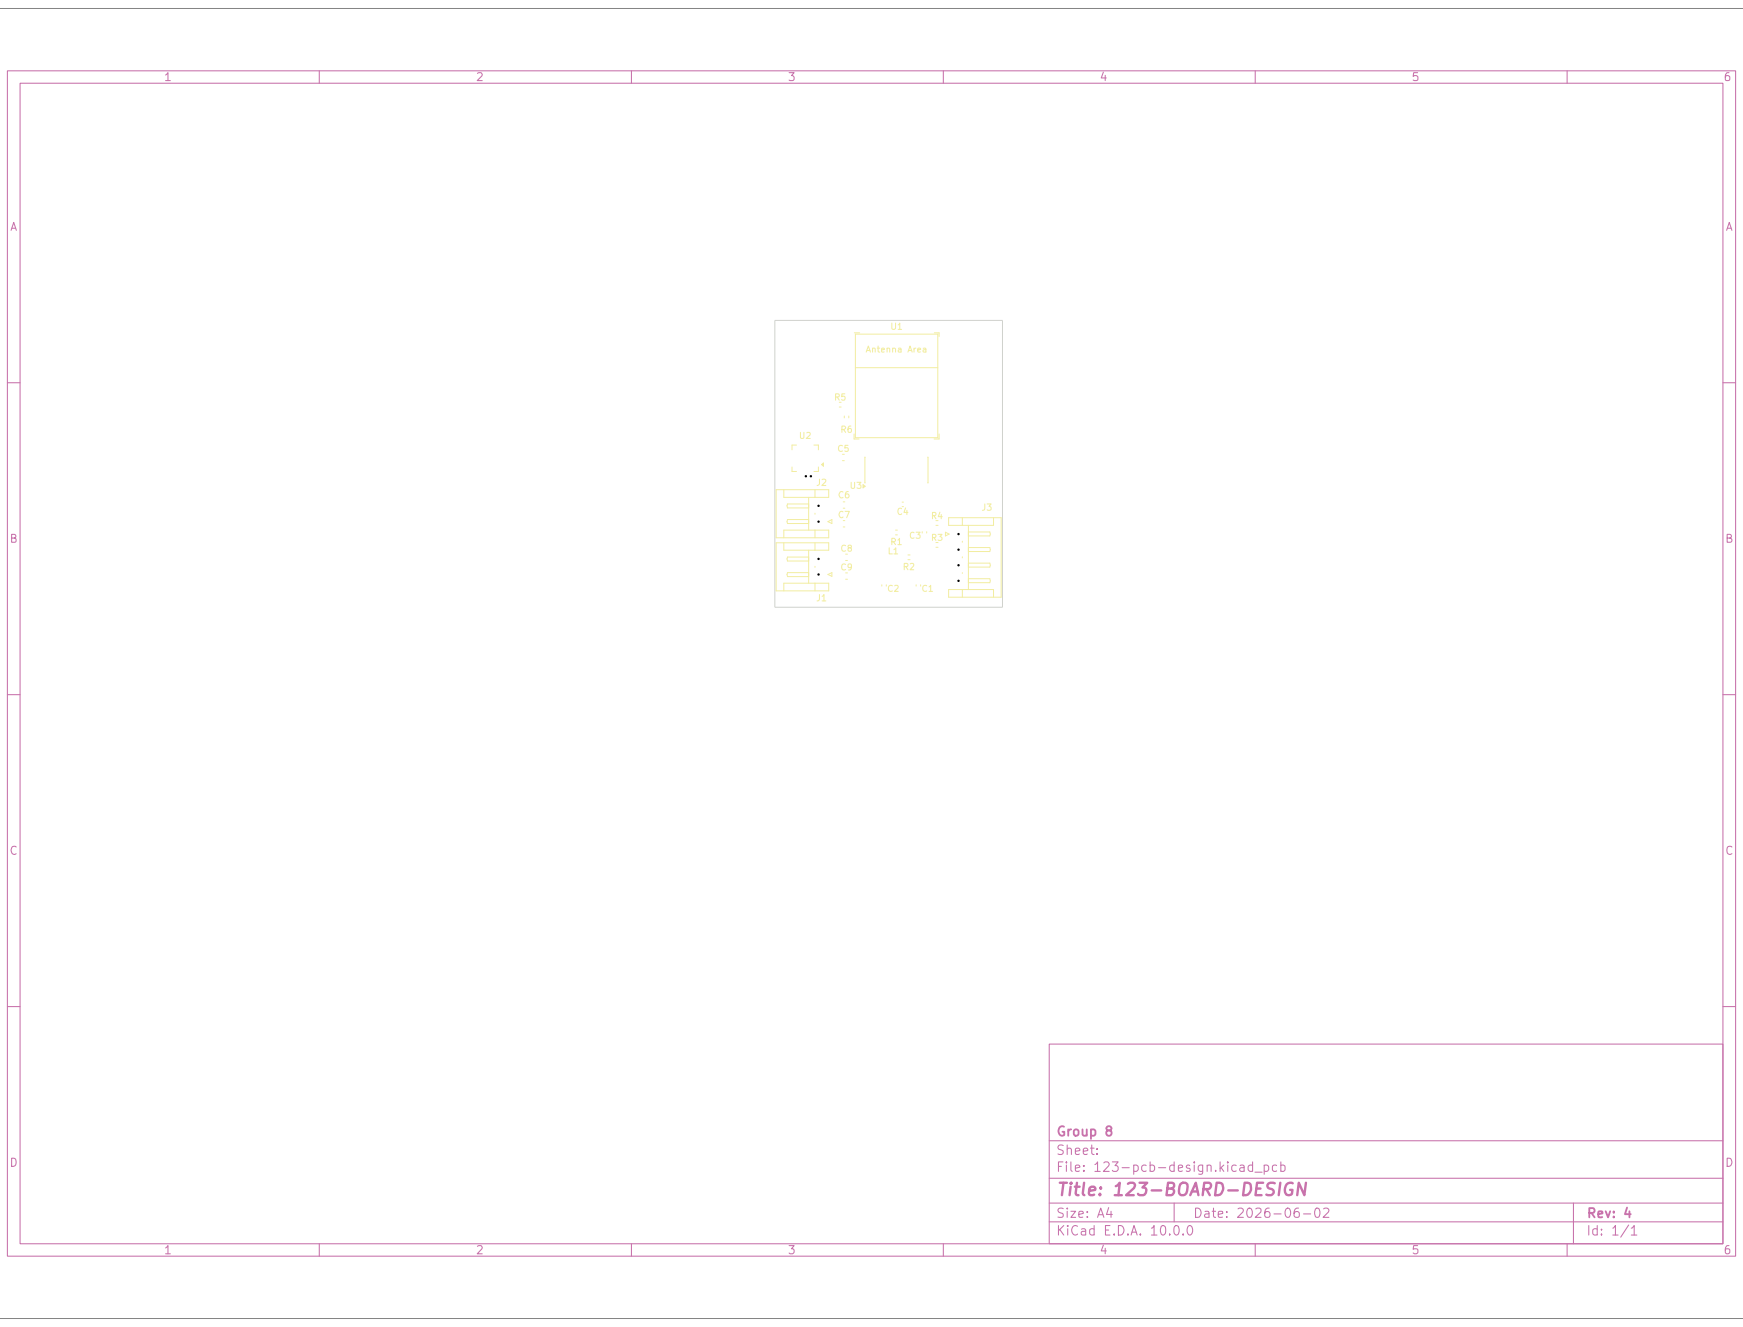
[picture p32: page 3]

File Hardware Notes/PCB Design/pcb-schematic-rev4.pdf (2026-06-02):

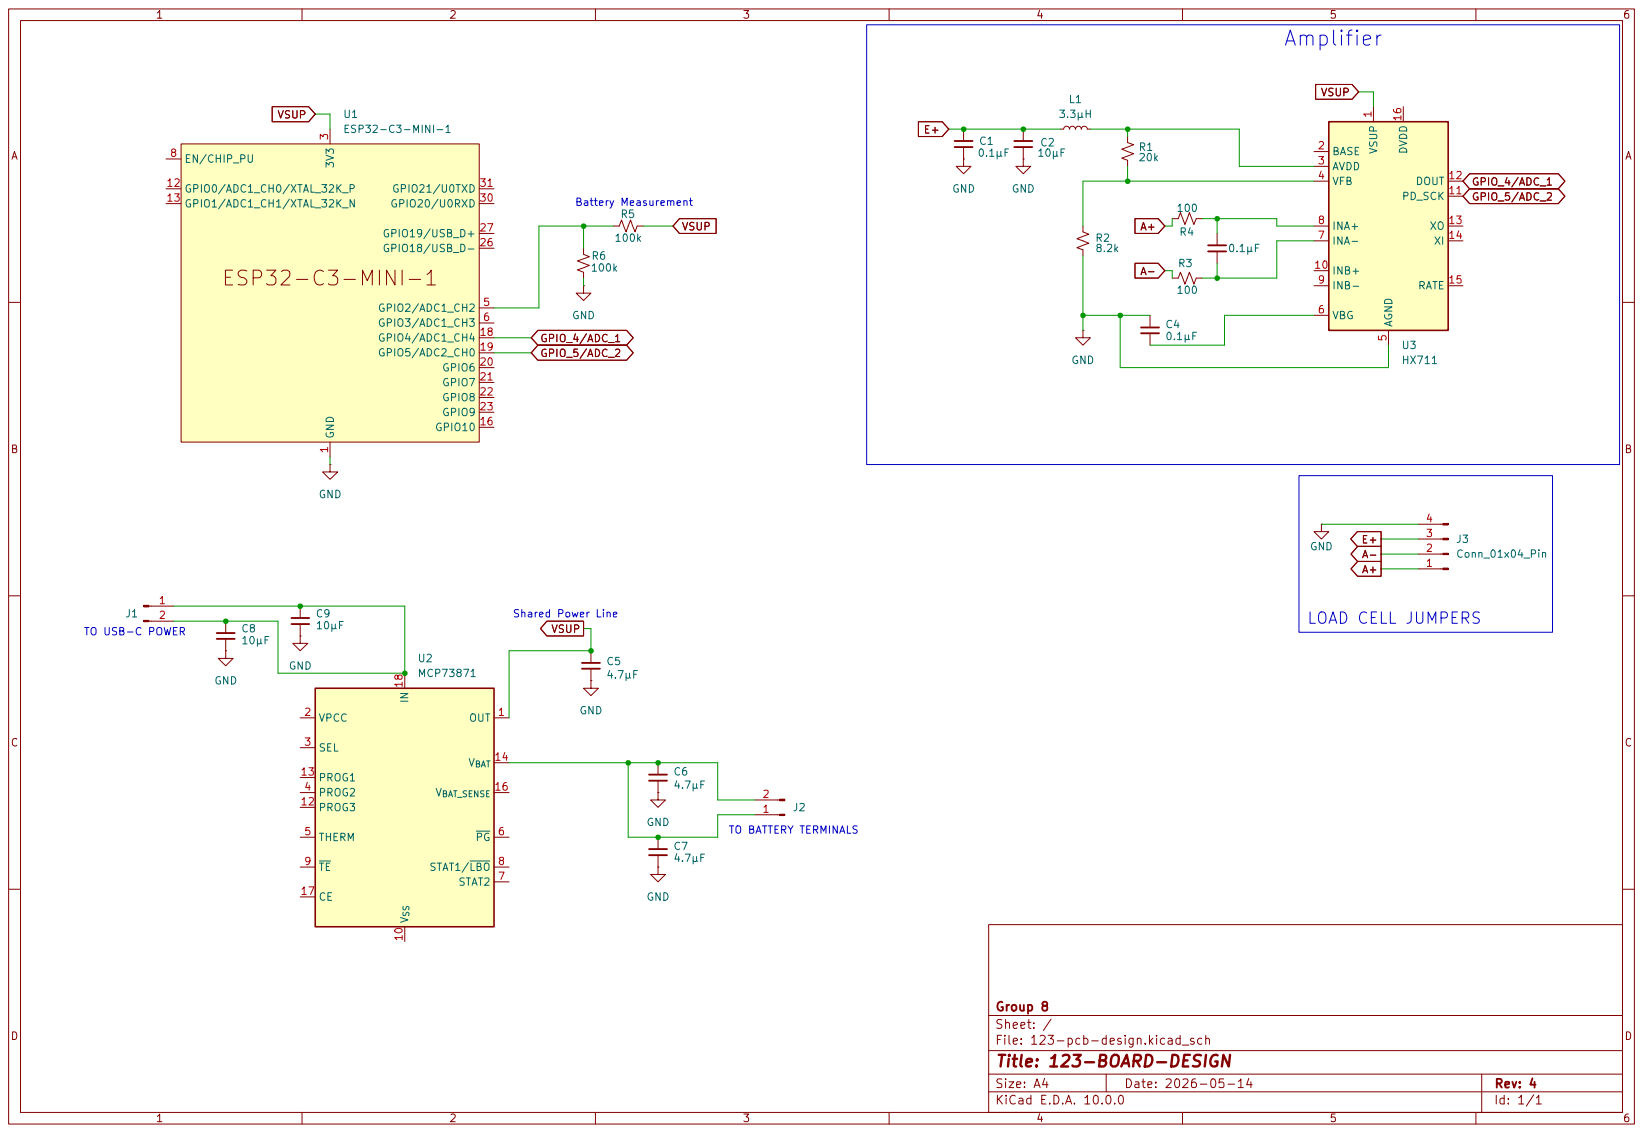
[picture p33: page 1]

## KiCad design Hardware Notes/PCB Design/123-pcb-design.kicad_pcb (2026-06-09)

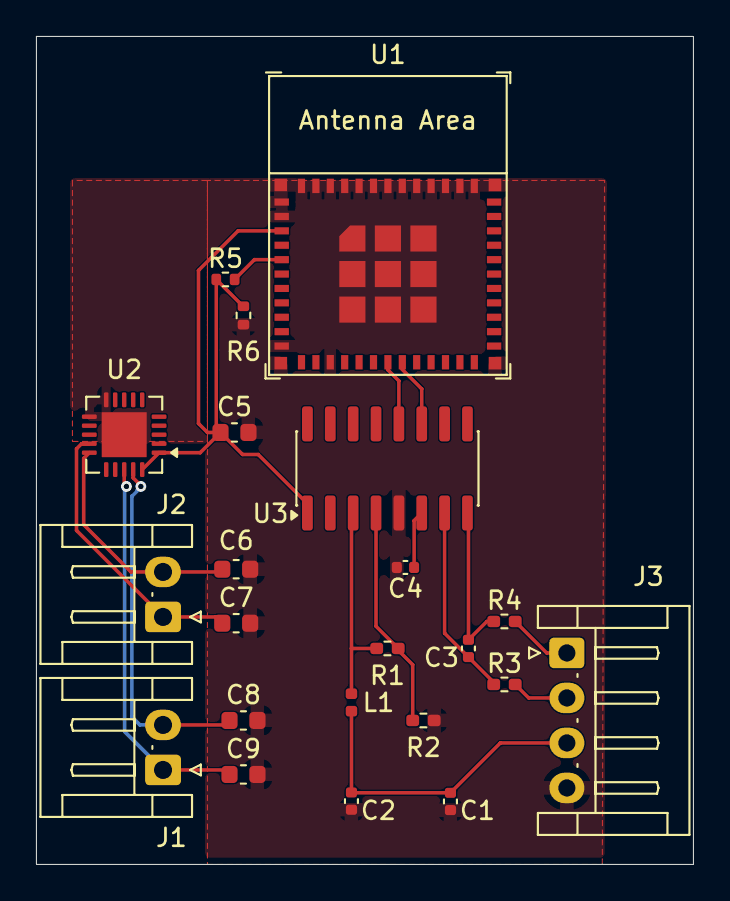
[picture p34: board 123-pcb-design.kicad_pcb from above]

Board: 2 copper layers, 36.5 x 46.0 mm, 22 parts (0 on the bottom side), 17 nets.

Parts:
C1, C3, C4: 0.1μF; C_0402_1005Metric
C2: 10μF; C_0402_1005Metric
C5, C6, C7: 4.7μF; C_0603_1608Metric
C8, C9: 10μF; C_0603_1608Metric
J1, J2: JST 1x02; JST_EH_S2B-EH_1x02_P2.50mm_Horizontal
J3: JST 1x04; JST_EH_S4B-EH_1x04_P2.50mm_Horizontal
L1: 3.3μH; L_0402_1005Metric
R1, R2: 20k; R_0402_1005Metric_Pad0.72x0.64mm_HandSolder
R3, R4: 100; R_0402_1005Metric_Pad0.72x0.64mm_HandSolder
R5: 100k; R_0402_1005Metric
R6: 100K; R_0402_1005Metric
U1: ESP32-C3-MINI-1
U2: MCP73871; QFN-20-1EP_4x4mm_P0.5mm_EP2.5x2.5mm
U3: HX711; SOIC-16_3.9x9.9mm_P1.27mm

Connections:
GND: C1.2, C2.2, C4.2, C5.2, C6.2, C7.2, C8.2, C9.2, J3.4, R2.2, R6.2, U1.1 (GND), U1.2 (GND), U1.11 (GND), U1.14 (GND), U1.36 (GND), U1.37 (GND), U1.38 (GND), U1.39 (GND), U1.40 (GND), U1.41 (GND), U1.42 (GND), U1.43 (GND), U1.44 (GND), U1.45 (GND), U1.46 (GND), U1.47 (GND), U1.48 (GND), U1.49 (GND), U1.50 (GND), U1.51 (GND), U1.52 (GND), U1.53 (GND), U2.10 (V_{SS}), U2.11 (V_{SS}), U2.21 (V_{SS}), U3.5 (AGND)
GPIO_4/ADC_1: U1.18 (GPIO4/ADC1_CH4), U3.12 (DOUT)
GPIO_5/ADC_2: U1.19 (GPIO5/ADC2_CH0), U3.11 (PD_SCK)
J3_Pin_1: J3.1, R4.2
J3_Pin_2: J3.2, R3.2
J3_Pin_3: C1.1, C2.1, J3.3, L1.2
unnamed: R5.2, U1.5 (GPIO2/ADC1_CH2)
unnamed: C7.1, J2.1, U2.14 (V_{BAT})
unnamed: L1.1, R1.1, U3.3 (AVDD)
unnamed: C3.2, R4.1, U3.8 (INA+)
unnamed: C3.1, R3.1, U3.7 (INA-)
unnamed: C4.1, U3.6 (VBG)
unnamed: R1.2, R2.1, U3.4 (VFB)
U2-J1_NEG: C8.1, J1.2
U2-J1_POS: C9.1, J1.1, U2.18 (IN)
U2-V_{BAT}-Pad15: C6.1, J2.2, U2.15 (V_{BAT})
VSUP: C5.1, U1.3 (3V3), U2.1 (OUT), U2.20 (OUT), U3.1 (VSUP)

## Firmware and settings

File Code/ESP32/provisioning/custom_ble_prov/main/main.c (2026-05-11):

/*
 * CSE 123A — Custom BLE provisioning (no Espressif wifi_prov_scheme_ble).
 *
 * QR JSON: {"device_name":"ESP32_XXX","device_id":"..."}
 * GATT: service + AUTH (write) + WIFI (write) + STATUS (read/notify)
 * Payloads: base64( UTF-8 JSON ). AUTH: {"auth_token":"<uuid>"}. WIFI: {"ssid","password"}
 *
 * Edit CSE123A_API_BASE to your deployed web-server origin (HTTPS).
 */
#include <assert.h>
#include <stdio.h>
#include <string.h>

#include "esp_log.h"
#include "esp_nimble_hci.h"
#include "esp_system.h"
#include "esp_wifi.h"
#include "esp_event.h"
#include "esp_netif.h"
#include "esp_http_client.h"
#include "esp_crt_bundle.h"
#include "nvs.h"
#include "nvs_flash.h"

#include "freertos/FreeRTOS.h"
#include "freertos/task.h"

#include "nimble/nimble_port.h"
#include "nimble/nimble_port_freertos.h"
#include "host/ble_att.h"
#include "host/ble_gatt.h"
#include "host/ble_hs.h"
#include "host/ble_uuid.h"
#include "host/util/util.h"
#include "services/gap/ble_svc_gap.h"
#include "services/gatt/ble_svc_gatt.h"
#include "store/config/ble_store_config.h"

#include "cJSON.h"
#include "qrcode.h"

static const char *TAG = "cse_ble_prov";
extern void ble_store_config_init(void);

#ifndef CSE123A_API_BASE
#define CSE123A_API_BASE "https://cse123a-project-6a3s.vercel.app"
#endif

/* NVS namespace + keys where provisioning state is persisted. After a
 * successful BLE provisioning the firmware writes auth_token, ssid and
 * password to NVS, then reboots. On the next boot we skip BLE entirely
 * and connect to Wi-Fi using the stored credentials. */
#define PROV_NVS_NS        "prov"
#define PROV_KEY_AUTH      "auth_token"
#define PROV_KEY_SSID      "wifi_ssid"
#define PROV_KEY_PWD       "wifi_pwd"

/* 128-bit UUIDs — byte order for NimBLE BLE_UUID128_INIT (reverse of canonical string). */
static const ble_uuid128_t svc_uuid =
    BLE_UUID128_INIT(0x01, 0x8e, 0x2c, 0x4b, 0x2f, 0x9f, 0xc8, 0xa8, 0x61, 0x4d, 0x67, 0x92,
                     0x01, 0x00, 0xb4, 0xa0);
static const ble_uuid128_t chr_auth_uuid =
    BLE_UUID128_INIT(0x01, 0x8e, 0x2c, 0x4b, 0x2f, 0x9f, 0xc8, 0xa8, 0x61, 0x4d, 0x67, 0x92,
                     0x02, 0x00, 0xb4, 0xa0);
static const ble_uuid128_t chr_wifi_uuid =
    BLE_UUID128_INIT(0x01, 0x8e, 0x2c, 0x4b, 0x2f, 0x9f, 0xc8, 0xa8, 0x61, 0x4d, 0x67, 0x92,
                     0x03, 0x00, 0xb4, 0xa0);
static const ble_uuid128_t chr_status_uuid =
    BLE_UUID128_INIT(0x01, 0x8e, 0x2c, 0x4b, 0x2f, 0x9f, 0xc8, 0xa8, 0x61, 0x4d, 0x67, 0x92,
                     0x04, 0x00, 0xb4, 0xa0);

static char s_device_id[20];
static char s_device_name[24];
static char s_auth_token[96];
static char s_status[48] = "idle";
static uint16_t s_status_val_handle;
static uint16_t s_conn_handle = BLE_HS_CONN_HANDLE_NONE;

static int gatt_svr_chr_access(uint16_t conn_handle, uint16_t attr_handle,
                               struct ble_gatt_access_ctxt *ctxt, void *arg);

static void ble_app_advertise(void);
static int gap_event(struct ble_gap_event *event, void *arg);

static const struct ble_gatt_svc_def gatt_svr_svcs[] = {
    {
        .type = BLE_GATT_SVC_TYPE_PRIMARY,
        .uuid = &svc_uuid.u,
        .characteristics =
            (struct ble_gatt_chr_def[]){
                {.uuid = &chr_auth_uuid.u,
                 .access_cb = gatt_svr_chr_access,
                 .flags = BLE_GATT_CHR_F_WRITE | BLE_GATT_CHR_F_WRITE_NO_RSP},
                {.uuid = &chr_wifi_uuid.u,
                 .access_cb = gatt_svr_chr_access,
                 .flags = BLE_GATT_CHR_F_WRITE | BLE_GATT_CHR_F_WRITE_NO_RSP},
                {.uuid = &chr_status_uuid.u,
                 .access_cb = gatt_svr_chr_access,
                 .flags = BLE_GATT_CHR_F_READ | BLE_GATT_CHR_F_NOTIFY,
                 .val_handle = &s_status_val_handle},
                {0},
            },
    },
    {0},
};

static void set_status(const char *msg)
{
    strncpy(s_status, msg, sizeof s_status - 1);
    s_status[sizeof s_status - 1] = '\0';
    ESP_LOGI(TAG, "status: %s", s_status);
}

static void notify_status(const char *msg)
{
    set_status(msg);
    if (s_conn_handle == BLE_HS_CONN_HANDLE_NONE) {
        return;
    }
    struct os_mbuf *om = ble_hs_mbuf_from_flat(msg, strlen(msg));
    if (!om) {
        return;
    }
    int rc = ble_gatts_notify_custom(s_conn_handle, s_status_val_handle, om);
    if (rc != 0) {
        ESP_LOGW(TAG, "notify failed rc=%d", rc);
        os_mbuf_free_chain(om);
    }
}

static esp_err_t prov_save_to_nvs(const char *auth_token, const char *ssid, const char *pwd)
{
    nvs_handle_t h;
    esp_err_t err = nvs_open(PROV_NVS_NS, NVS_READWRITE, &h);
    if (err != ESP_OK) return err;
    if ((err = nvs_set_str(h, PROV_KEY_AUTH, auth_token)) != ESP_OK) goto done;
    if ((err = nvs_set_str(h, PROV_KEY_SSID, ssid)) != ESP_OK) goto done;
    if ((err = nvs_set_str(h, PROV_KEY_PWD,  pwd))  != ESP_OK) goto done;
    err = nvs_commit(h);
done:
    nvs_close(h);
    return err;
}

static bool prov_load_from_nvs(char *auth_token, size_t auth_size,
                               char *ssid,       size_t ssid_size,
                               char *pwd,        size_t pwd_size)
{
    nvs_handle_t h;
    esp_err_t err = nvs_open(PROV_NVS_NS, NVS_READONLY, &h);
    if (err != ESP_OK) return false;

    size_t s;
    s = auth_size;
    if ((err = nvs_get_str(h, PROV_KEY_AUTH, auth_token, &s)) != ESP_OK) {
        nvs_close(h);
        return false;
    }
    s = ssid_size;
    if ((err = nvs_get_str(h, PROV_KEY_SSID, ssid, &s)) != ESP_OK) {
        nvs_close(h);
        return false;
    }
    s = pwd_size;
    err = nvs_get_str(h, PROV_KEY_PWD, pwd, &s);
    nvs_close(h);
    return err == ESP_OK;
}

/* Reboot from a non-BLE task so the BLE notify above has a chance to flush. */
static void delayed_restart_task(void *arg)
{
    (void)arg;
    vTaskDelay(pdMS_TO_TICKS(800));
    ESP_LOGI(TAG, "restarting to apply stored provisioning...");
    esp_restart();
}

static int handle_auth_write(struct os_mbuf *om)
{
    uint16_t pktlen = OS_MBUF_PKTLEN(om);
    ESP_LOGI(TAG, "handle_auth_write called, pktlen=%d", pktlen);
    if (pktlen == 0 || pktlen >= sizeof(s_auth_token)) {
        return BLE_ATT_ERR_INVALID_ATTR_VALUE_LEN;
    }

    int rc = ble_hs_mbuf_to_flat(om, s_auth_token, sizeof(s_auth_token) - 1, NULL);
    if (rc != 0) {
        return BLE_ATT_ERR_UNLIKELY;
    }
    s_auth_token[pktlen] = '\0';

    ESP_LOGI(TAG, "auth token stored: %s (len=%d)", s_auth_token, pktlen);
    notify_status("auth_ok");
    return 0;
}

static int handle_wifi_write(struct os_mbuf *om)
{
    uint16_t pktlen = OS_MBUF_PKTLEN(om);
    ESP_LOGI(TAG, "handle_wifi_write called, pktlen=%d", pktlen);
    char wifi_str[256];
    if (pktlen == 0 || pktlen >= sizeof(wifi_str)) {
        return BLE_ATT_ERR_INVALID_ATTR_VALUE_LEN;
    }
    int rc = ble_hs_mbuf_to_flat(om, wifi_str, sizeof(wifi_str) - 1, NULL);
    if (rc != 0) return BLE_ATT_ERR_UNLIKELY;
    wifi_str[pktlen] = '\0';

    ESP_LOGI(TAG, "wifi payload received (len=%d)", pktlen);

    char *colon = strchr(wifi_str, ':');
    if (!colon) return BLE_ATT_ERR_INVALID_ATTR_VALUE_LEN;
    *colon = '\0';
    const char *ssid = wifi_str;
    const char *pwd  = colon + 1;

    if (s_auth_token[0] == '\0') {
        ESP_LOGW(TAG, "wifi received but auth token not set yet");
        notify_status("auth_missing");
        return BLE_ATT_ERR_UNLIKELY;
    }

    /* Persist auth_token + Wi-Fi creds to NVS, then reboot. On the next
     * boot the firmware will skip BLE, connect to Wi-Fi automatically,
     * and POST /api/ingest with the saved auth token. */
    esp_err_t err = prov_save_to_nvs(s_auth_token, ssid, pwd);
    if (err != ESP_OK) {
        ESP_LOGE(TAG, "prov_save_to_nvs: %s", esp_err_to_name(err));
        notify_status("nvs_failed");
        return BLE_ATT_ERR_UNLIKELY;
    }

    ESP_LOGI(TAG, "provisioning saved to NVS; restarting in ~1s");
    notify_status("saved_restarting");

    BaseType_t ok = xTaskCreate(delayed_restart_task, "prov_restart", 2048, NULL, 5, NULL);
    if (ok != pdPASS) {
        ESP_LOGE(TAG, "failed to create restart task");
        return BLE_ATT_ERR_UNLIKELY;
    }
    return 0;
}

static int gatt_svr_chr_access(uint16_t conn_handle, uint16_t attr_handle,
                             struct ble_gatt_access_ctxt *ctxt, void *arg)
{
    (void)conn_handle;
    (void)attr_handle;
    (void)arg;

    if (ctxt->op == BLE_GATT_ACCESS_OP_READ_CHR) {
        if (ble_uuid_cmp(ctxt->chr->uuid, &chr_status_uuid.u) == 0) {
            int rc = os_mbuf_append(ctxt->om, s_status, strlen(s_status));
            return rc == 0 ? 0 : BLE_ATT_ERR_INSUFFICIENT_RES;
        }
        return BLE_ATT_ERR_UNLIKELY;
    }

    if (ctxt->op == BLE_GATT_ACCESS_OP_WRITE_CHR) {
        if (ble_uuid_cmp(ctxt->chr->uuid, &chr_auth_uuid.u) == 0) {
            return handle_auth_write(ctxt->om);
        }
        if (ble_uuid_cmp(ctxt->chr->uuid, &chr_wifi_uuid.u) == 0) {
            return handle_wifi_write(ctxt->om);
        }
    }
    return BLE_ATT_ERR_UNLIKELY;
}

static void gatt_svr_register_cb(struct ble_gatt_register_ctxt *ctxt, void *arg)
{
    (void)arg;
    char buf[BLE_UUID_STR_LEN];
    switch (ctxt->op) {
    case BLE_GATT_REGISTER_OP_CHR:
        ESP_LOGD(TAG, "characteristic %s handle=%d",
                 ble_uuid_to_str(ctxt->chr.chr_def->uuid, buf), ctxt->chr.val_handle);
        break;
    default:
        break;
    }
}

static int gatt_svr_init(void)
{
    int rc;

    ble_svc_gap_init();
    ble_svc_gatt_init();

    rc = ble_gatts_count_cfg(gatt_svr_svcs);
    if (rc != 0) {
        return rc;
    }

    rc = ble_gatts_add_svcs(gatt_svr_svcs);
    if (rc != 0) {
        return rc;
    }

    return 0;
}

static void ble_app_advertise(void)
{
    struct ble_gap_adv_params adv_params;
    struct ble_hs_adv_fields fields;
    const char *name;
    int rc;

    memset(&fields, 0, sizeof fields);
    fields.flags = BLE_HS_ADV_F_DISC_GEN | BLE_HS_ADV_F_BREDR_UNSUP;
    fields.tx_pwr_lvl_is_present = 1;
    fields.tx_pwr_lvl = BLE_HS_ADV_TX_PWR_LVL_AUTO;

    name = ble_svc_gap_device_name();
    fields.name = (uint8_t *)name;
    fields.name_len = strlen(name);
    fields.name_is_complete = 1;

    rc = ble_gap_adv_set_fields(&fields);
    if (rc != 0) {
        ESP_LOGE(TAG, "adv_set_fields failed rc=%d", rc);
        return;
    }

    memset(&adv_params, 0, sizeof adv_params);
    adv_params.conn_mode = BLE_GAP_CONN_MODE_UND;
    adv_params.disc_mode = BLE_GAP_DISC_MODE_GEN;
    rc = ble_gap_adv_start(BLE_OWN_ADDR_PUBLIC, NULL, BLE_HS_FOREVER, &adv_params, gap_event, NULL);
    if (rc != 0) {
        ESP_LOGE(TAG, "adv_start failed rc=%d", rc);
    }
}

static int gap_event(struct ble_gap_event *event, void *arg)
{
    (void)arg;
    switch (event->type) {
    case BLE_GAP_EVENT_CONNECT:
        if (event->connect.status == 0) {
            s_conn_handle = event->connect.conn_handle;
            ESP_LOGI(TAG, "connected handle=%d", s_conn_handle);
            int mtu_rc = ble_gattc_exchange_mtu(s_conn_handle, NULL, NULL);
            ESP_LOGI(TAG, "MTU exchange requested rc=%d", mtu_rc);
        } else {
            s_conn_handle = BLE_HS_CONN_HANDLE_NONE;
            ble_app_advertise();
        }
        break;
    case BLE_GAP_EVENT_DISCONNECT:
        ESP_LOGI(TAG, "disconnect reason=%d", event->disconnect.reason);
        s_conn_handle = BLE_HS_CONN_HANDLE_NONE;
        ble_app_advertise();
        break;
    case BLE_GAP_EVENT_ADV_COMPLETE:
        ble_app_advertise();
        break;
    case BLE_GAP_EVENT_MTU:
        ESP_LOGI(TAG, "MTU negotiated conn=%d mtu=%d",
                 event->mtu.conn_handle, event->mtu.value);
        break;
    default:
        break;
    }
    return 0;
}

static void on_reset(int reason)
{
    ESP_LOGE(TAG, "nimble reset reason=%d", reason);
}

static void on_sync(void)
{
    int rc = ble_hs_util_ensure_addr(0);
    if (rc != 0) {
        ESP_LOGE(TAG, "ensure_addr rc=%d", rc);
        return;
    }

    uint8_t own_addr_type;
    rc = ble_hs_id_infer_auto(0, &own_addr_type);
    if (rc != 0) {
        ESP_LOGE(TAG, "infer_auto rc=%d", rc);
        return;
    }

    rc = ble_svc_gap_device_name_set(s_device_name);
    if (rc != 0) {
        ESP_LOGE(TAG, "gap_device_name_set rc=%d", rc);
    }
    ble_app_advertise();
}

static void nimble_host_task(void *param)
{
    (void)param;
    nimble_port_run();
    nimble_port_freertos_deinit();
}

static void show_qr_payload(void)
{
    char payload[192];
    snprintf(payload, sizeof payload, "{\"device_name\":\"%s\",\"device_id\":\"%s\"}", s_device_name,
             s_device_id);
    ESP_LOGI(TAG, "QR JSON (scan with app): %s", payload);
    esp_qrcode_config_t cfg = ESP_QRCODE_CONFIG_DEFAULT();
    esp_qrcode_generate(&cfg, payload);
}

static void do_ingest_task(void *arg)
{
    (void)arg;
    char url[160];
    snprintf(url, sizeof url, "%s/api/ingest", CSE123A_API_BASE);

    esp_http_client_config_t cfg = {
        .url = url,
        .method = HTTP_METHOD_POST,
        .timeout_ms = 15000,
        .crt_bundle_attach = esp_crt_bundle_attach,
    };
    esp_http_client_handle_t client = esp_http_client_init(&cfg);
    if (client == NULL) {
        ESP_LOGE(TAG, "esp_http_client_init failed");
        vTaskDelete(NULL);
        return;
    }

    char auth_hdr[160];
    snprintf(auth_hdr, sizeof auth_hdr, "Bearer %s", s_auth_token);
    esp_http_client_set_header(client, "Authorization", auth_hdr);
    esp_http_client_set_header(client, "Content-Type", "application/json");

    char body[192];
    snprintf(body, sizeof body, "{\"device_id\":\"%s\",\"weight_g\":0,\"battery_mv\":0}",
             s_device_id);
    esp_http_client_set_post_field(client, body, strlen(body));

    esp_err_t err = esp_http_client_perform(client);
    if (err == ESP_OK) {
        ESP_LOGI(TAG, "ingest HTTP %d", esp_http_client_get_status_code(client));
    } else {
        ESP_LOGE(TAG, "ingest failed: %s", esp_err_to_name(err));
    }
    esp_http_client_cleanup(client);
    vTaskDelete(NULL);
}

static void wifi_event_handler(void *arg, esp_event_base_t base, int32_t id, void *data)
{
    (void)arg;
    (void)data;
    if (base == WIFI_EVENT && id == WIFI_EVENT_STA_START) {
        ESP_LOGI(TAG, "WIFI_EVENT_STA_START");
    } else if (base == WIFI_EVENT && id == WIFI_EVENT_STA_DISCONNECTED) {
        ESP_LOGW(TAG, "WIFI_EVENT_STA_DISCONNECTED");
        notify_status("wifi_failed");
    } else if (base == IP_EVENT && id == IP_EVENT_STA_GOT_IP) {
        ESP_LOGI(TAG, "got IP");
        notify_status("wifi_connected");

        if (s_auth_token[0] == '\0') {
            ESP_LOGW(TAG, "no auth token; skip ingest");
            return;
        }

        BaseType_t task_ok = xTaskCreate(do_ingest_task, "ingest", 8192, NULL, 5, NULL);
        if (task_ok != pdPASS) {
            ESP_LOGE(TAG, "failed to create ingest task");
        }
    }
}

static void init_wifi_and_ids(void)
{
    ESP_ERROR_CHECK(esp_netif_init());
    ESP_ERROR_CHECK(esp_event_loop_create_default());
    esp_netif_create_default_wifi_sta();

    wifi_init_config_t wcfg = WIFI_INIT_CONFIG_DEFAULT();
    ESP_ERROR_CHECK(esp_wifi_init(&wcfg));
    ESP_ERROR_CHECK(esp_event_handler_register(WIFI_EVENT, ESP_EVENT_ANY_ID, wifi_event_handler, NULL));
    ESP_ERROR_CHECK(esp_event_handler_register(IP_EVENT, IP_EVENT_STA_GOT_IP, wifi_event_handler, NULL));
    ESP_ERROR_CHECK(esp_wifi_set_mode(WIFI_MODE_STA));
    ESP_ERROR_CHECK(esp_wifi_start());

    uint8_t mac[6];
    ESP_ERROR_CHECK(esp_wifi_get_mac(WIFI_IF_STA, mac));
    snprintf(s_device_id, sizeof s_device_id, "%02x%02x%02x%02x%02x%02x", mac[0], mac[1], mac[2],
             mac[3], mac[4], mac[5]);
    snprintf(s_device_name, sizeof s_device_name, "ESP32_%02X%02X%02X", mac[3], mac[4], mac[5]);
}

void app_main(void)
{
    esp_err_t ret = nvs_flash_init();
    if (ret == ESP_ERR_NVS_NO_FREE_PAGES || ret == ESP_ERR_NVS_NEW_VERSION_FOUND) {
        ESP_ERROR_CHECK(nvs_flash_erase());
        ret = nvs_flash_init();
    }
    ESP_ERROR_CHECK(ret);

    init_wifi_and_ids();

    char stored_ssid[64] = {0};
    char stored_pwd[96]  = {0};
    bool have_stored_prov = prov_load_from_nvs(
        s_auth_token, sizeof s_auth_token,
        stored_ssid,  sizeof stored_ssid,
        stored_pwd,   sizeof stored_pwd);

    if (have_stored_prov) {
        ESP_LOGI(TAG, "found stored provisioning; skipping BLE and connecting Wi-Fi");

        wifi_config_t cfg = {0};
        strncpy((char *)cfg.sta.ssid,     stored_ssid, sizeof cfg.sta.ssid - 1);
        strncpy((char *)cfg.sta.password, stored_pwd,  sizeof cfg.sta.password - 1);
        ESP_ERROR_CHECK(esp_wifi_set_config(WIFI_IF_STA, &cfg));

        esp_err_t w = esp_wifi_connect();
        if (w != ESP_OK) {
            ESP_LOGE(TAG, "esp_wifi_connect: %s", esp_err_to_name(w));
        }
        /* wifi_event_handler will run /api/ingest once IP is acquired. */
        return;
    }

    /* No stored creds → run BLE provisioning flow. */
    show_qr_payload();

    ESP_ERROR_CHECK(nimble_port_init());
    ble_att_set_preferred_mtu(512);

    ble_hs_cfg.reset_cb = on_reset;
    ble_hs_cfg.sync_cb = on_sync;
    ble_hs_cfg.gatts_register_cb = gatt_svr_register_cb;
    ble_hs_cfg.store_status_cb = ble_store_util_status_rr;
    ble_hs_cfg.sm_bonding = 0;
    ble_hs_cfg.sm_mitm = 0;
    ble_hs_cfg.sm_sc = 0;

    int rc = gatt_svr_init();
    assert(rc == 0);

    ble_store_config_init();
    nimble_port_freertos_init(nimble_host_task);
}

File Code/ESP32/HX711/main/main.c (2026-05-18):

#include <inttypes.h>
#include "freertos/FreeRTOS.h"
#include "freertos/task.h"
#include "esp_log.h"
#include "https_client.h"
#include "wifi_manager.h"
#include "nvs_flash.h"
#include "esp_sleep.h"

#include "ble.h"
#include "nvs.h"

#include "HX711.h"

#define WIFI_CONNECT_TIMEOUT_MS 15000
#define DEBUG 1

static bool tareDone = false;
static bool notFirstBoot = false;
static int32_t gramBefore = 0;
static bool wifiWasValidated = false;

static const char *TAG = "MAIN";



static void load_state(void)
{
    nvs_handle_t h;
    ESP_ERROR_CHECK(nvs_open("scale", NVS_READWRITE, &h));

    nvs_get_u8(h, "tareDone", (uint8_t *)&tareDone);
    nvs_get_u8(h, "notFirst", (uint8_t *)&notFirstBoot);
    nvs_get_i32(h, "gramBefore", &gramBefore);
    nvs_get_u8(h, "wifiValid", (uint8_t *)&wifiWasValidated);

    int32_t saved_offset = 0;
    if (nvs_get_i32(h, "offset", &saved_offset) == ESP_OK) {
        hx711_set_offset(saved_offset);
    }

    nvs_close(h);
}

static void save_state(void)
{
    nvs_handle_t h;
    ESP_ERROR_CHECK(nvs_open("scale", NVS_READWRITE, &h));

    nvs_set_u8(h, "tareDone", tareDone);
    nvs_set_u8(h, "notFirst", notFirstBoot);
    nvs_set_i32(h, "gramBefore", gramBefore);
    nvs_set_u8(h, "wifiValid", wifiWasValidated);

    nvs_set_i32(h, "offset", hx711_get_offset());
    
    ESP_ERROR_CHECK(nvs_commit(h));
    nvs_close(h);
}

/** POST /api/ingest with Bearer auth (same contract as custom_ble_prov). */
static void post_ingest_grams(int32_t grams)
{
    char device_id[24] = {0};
    char auth_token[96] = {0};
    char body[192];

    wifi_get_device_id_from_mac(device_id, sizeof device_id);
    if (wifi_get_prov_auth_token(auth_token, sizeof auth_token) != ESP_OK || auth_token[0] == '\0') {
        ESP_LOGW(TAG, "No auth token in NVS; skip ingest");
        return;
    }

    snprintf(body, sizeof body, "{\"device_id\":\"%s\",\"weight_g\":%" PRId32 ",\"battery_mv\":0}", device_id,
             grams);

    ESP_LOGI(TAG, "ingest POST: %s", body);
    esp_err_t err = https_post_bearer(CSE123A_INGEST_URL, body, auth_token);
    if (err != ESP_OK) {
        ESP_LOGE(TAG, "ingest POST failed: %s", esp_err_to_name(err));
    }
}

static void reboot_to_provisioning(void)
{
    ESP_LOGW(TAG, "Wi-Fi failed; clearing provisioning and rebooting to BLE prov");

    wifi_clear_prov();   // implement this to erase saved SSID/password/token if needed
    save_state();        // optional, only if you want to preserve scale state

    vTaskDelay(pdMS_TO_TICKS(500));
    esp_restart();
}

void app_main(void)
{
    esp_err_t ret = nvs_flash_init();
    if (ret == ESP_ERR_NVS_NO_FREE_PAGES || ret == ESP_ERR_NVS_NEW_VERSION_FOUND) {
        ESP_ERROR_CHECK(nvs_flash_erase());
        ret = nvs_flash_init();
    }
    ESP_ERROR_CHECK(ret);

    ESP_ERROR_CHECK(wifi_init());
    load_state();

    if (!prov_credentials_saved()) {
        ESP_LOGI(TAG, "No NVS provisioning; starting BLE (same flow as custom_ble_prov)");
        ESP_ERROR_CHECK(ble_provisioning_init());
        return;
    }

    ESP_LOGI(TAG, "Provisioning found in NVS; connecting Wi-Fi");
    ESP_ERROR_CHECK(wifi_apply_prov_and_connect());
    
    
    if (!wifi_wait_connected_timeout(pdMS_TO_TICKS(WIFI_CONNECT_TIMEOUT_MS))) {
        if (!wifiWasValidated) {
            ESP_LOGW(TAG, "First Wi-Fi validation failed; clearing provisioning");
            reboot_to_provisioning();
        } else {
            ESP_LOGW(TAG, "Wi-Fi already validated before; router may be off. Sleeping/retrying later");

            hx711_power_down();
            esp_sleep_enable_timer_wakeup(15 * 1000000ULL);
            esp_deep_sleep_start();
        }
    }

    if (!wifiWasValidated) {
        ESP_LOGI(TAG, "Wi-Fi validated successfully");

        wifiWasValidated = true;
        save_state();
    }

    sensor_init();
    hx711_power_up();
    vTaskDelay(pdMS_TO_TICKS(500));
    ESP_LOGI(TAG, "Waking Up");
    vTaskDelay(pdMS_TO_TICKS(200));

    if (!tareDone) {
        tare(20);
        tareDone = true;
        save_state();
        ESP_LOGI(TAG, "Tare complete");
    }

    int32_t raw = get_raw_weight(10);
    int32_t grams = get_grams(raw);
    ESP_LOGI(TAG, "grams=%" PRId32 ", gramBefore=%" PRId32, grams, gramBefore);

    if (!notFirstBoot) {
        /* One-time baseline: POST the actual reading so the server has a real weight, not a
         * synthetic zero. After this we only POST when weight moves past the threshold. */
        post_ingest_grams(grams);
        gramBefore = grams;
        notFirstBoot = true;
        save_state();
        ESP_LOGI(TAG, "First Boot Completed");
    } else if ((grams > gramBefore + 15) || (grams < gramBefore - 15)) {
        ESP_LOGI(TAG, "Weight changed; ensure Wi-Fi and POST ingest");
        /* wifi_apply_prov_and_connect() clears WIFI_CONNECTED_BIT; calling it while already
         * associated often does not raise IP_EVENT_STA_GOT_IP again → wifi_wait_connected()
         * blocks forever. Skip reconnect if we already have an IP from boot. */
        if (!wifi_sta_has_ip()) {
            ESP_ERROR_CHECK(wifi_apply_prov_and_connect());
            wifi_wait_connected();
        }

        vTaskDelay(pdMS_TO_TICKS(1000));

        post_ingest_grams(grams);

        gramBefore = (int32_t)grams;
        save_state();
    } else {
        ESP_LOGI(TAG, "No significant change");
    }

    hx711_power_down();
    ESP_LOGI(TAG, "Going to sleep");

    esp_sleep_enable_timer_wakeup(5 * 1000000ULL);
    esp_deep_sleep_start();
}

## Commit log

2026-02-12 System Drawing
    [Filter-System.dwg]
2026-02-12 updated line weights for visibility
    [Filter-System.dwg]
2026-02-13 Base concept drawing
    [Base-Concept.dwg]
2026-02-14 updated status 3
    [Base-Concept.dwg]
2026-02-15 moved diagrams to new directory
    [Base-Concept.dwg, Filter-System.dwg]
2026-02-16 Adding base plates for load cell
    [plates_v1.stl]
2026-02-17 Added a screw hole in base plate
    [plates_v2.stl]
2026-02-17 Starter base idea of initial reading + going to have debug calibration if it changes
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2026-02-19 load cell rework
    [Base-Concept.dwg]
2026-02-19 updated filter system drawing and pdfs
    [Base-Concept.dwg, Filter-System.dwg]
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2026-02-20 Updated base plates design
    [base_plates_v3.stl, base_plates_v4.stl, base_plates_v5.stl]
2026-02-20 Fixed the spacing for the holes in the plates
    [base_plate_thin.stl, base_plate_v6.stl]
2026-02-20 Made it m4 compitable
    [base_plate_v7.stl]
2026-02-20 fixing m4 hole size
    [base_plate_v8.stl]
2026-02-20 removing bad design
    [base_plate_v8.stl]
2026-02-21 Shows raw data, offset, weightChange, grams not calibrated not actual grams
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2026-02-25 Fixed names, + calibrating
    [HX711.c]
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2026-02-27 Added reset calibration button
2026-02-27 Added sample ingest data command in injest.js comments
2026-02-28 combo layout w/ Initial Prototype layout
    [Filter-System.dwg]
2026-02-28 fixing layers and web vs phone
    [Filter-System.dwg]
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2026-03-03 Made the plate thicker and added flat bottom
    [base_plat_v8.stl]
2026-03-03 lineweight and separation
    [Filter-System.dwg]
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2026-03-10 Replaced all instances of esp32 and brita with appropriate terms
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2026-03-11 made a design for the washer
    [washer_m4.stl]
2026-03-12 documents split in two
    [Filter-System-Prototype.dwg, Filter-System.dwg]
2026-03-13 revision changes to prototype doc
    [Filter-System-Prototype.dwg]
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2026-03-13 First edit
    [Wiring-Diagram.dwg]
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2026-03-14 finished wire diagram
    [Wiring Diagram.dwg, Wiring-Diagram.dwg]
2026-03-14 wiring diagram update, more docs updates
    [Wiring-Diagram-v2.dwg]
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2026-03-18 Quick calibration refresh fix
2026-03-19 diagram updates
    [Filter-System-Prototype.dwg, Filter-System.dwg]
2026-03-19 presentation pdf
    [Filter-System.dwg]
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2026-04-11 pcb prototype setup
    [123-pcb-design.kicad_pcb, 123-pcb-design.kicad_sch]
2026-04-11 ADC file added
    [123-pcb-design.kicad_sch]
2026-04-11 USBC connector and HX711 wiring
    [123-pcb-design.kicad_sch]
2026-04-13 amplifier circuit added
    [123-pcb-design.kicad_pcb, 123-pcb-design.kicad_sch]
2026-04-13 adding compartment for base
    [Compartment_v1.stl]
2026-04-13 Adding lid for compartment
    [lid_v1.stl]
2026-04-14 adding updating compartment file
    [Compartment_v1.stl, compartment_v1.stl]
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2026-04-16 updated to v1 circuit
    [123-pcb-design.kicad_pcb, 123-pcb-design.kicad_sch]
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2026-04-18 updated design for housing
    [compartment_v2.stl]
2026-04-18 moved opening down
    [compartment_v3.stl]
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2026-04-23 pcb rev2 and routing complete
    [123-pcb-design.kicad_pcb, 123-pcb-design.kicad_sch]
2026-04-23 Added notches to make sure the plate doesnt fall out
    [compartment_v4.stl]
2026-04-23 added new base plate design
    [base_plate_v9.stl]
2026-04-23 Lowered the shelf
    [compartment_v5.stl]
2026-04-23 simple BLE provisioning
    [partitions.csv]
2026-04-28 Increased the height of walls
    [compartment_v7.stl]
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2026-04-30 base plate desing
    [base_plate_v10.stl]
2026-04-30 Add custom BLE provisioning flow across app, backend, and ESP firmware.
    This aligns QR/BLE onboarding with hardcoded UUIDs, token-based device registration, and ESP32 custom GATT provisioning so iOS dev builds can provision and ingest reliably.
    Made-with: Cursor
    [partitions.csv]
2026-04-30 Stabilize BLE provisioning across app and ESP32.
    Use compact BLE payload writes with stronger scanner/device discovery handling in the mobile app, and move HTTPS ingest off the Wi-Fi event task into a dedicated ESP32 worker to prevent TLS stack overflows.
    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
    [main.c]
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2026-05-02 made top plate wider
    [top_plate_v1.stl]
2026-05-02 Made a washer design
    [washer_m4_v2.stl]
2026-05-03 board rev3
    [123-pcb-design.kicad_pcb, 123-pcb-design.kicad_sch]
2026-05-05 Add my-devices list API and dashboard device picker for groups.
    Expose GET /api/devices for the signed-in user, require device ownership when attaching a device to a new group, and let the home screen select a registered device instead of typing an id.
2026-05-05 Updated design/renamed designs
    [base_plate_v1.stl, base_plate_v11.stl, base_plate_v2.stl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]
2026-05-05 added hole for wire passthrough
    [base_plate_v12.stl]
2026-05-05 making walls higher'
    [compartment_v8.stl]
2026-05-06 Adding feature where users can deactive/activite their accounts via web-app
    [top_plate_v1.3mf]
2026-05-08 BLE + Main
    [partitions.csv]
2026-05-11 Persist provisioning on ESP, simplify web shell, polish provisioning UX
    - Firmware (custom_ble_prov): save auth_token + Wi-Fi SSID/password to NVS
    on the WIFI characteristic write, then restart. On boot, skip BLE when
    stored creds exist and auto-reconnect Wi-Fi so the first /api/ingest
    POST still fires unchanged.
    - Mobile (ProvisionDeviceScreen): after BLE writes, poll /api/devices for
    the new device_id and pop back to Home as soon as the server sees it;
    cancels the BLE connection cleanly while the ESP reboots.
    - Web (api/groups): list groups the user owns even when no group_members
    row exists yet, so creator-owned groups always show in My Groups.
    - Web (App/Settings/Guide): coll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
    [main.c]
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2026-05-12 poster added, pcb rev3 updated
    [123-pcb-design.kicad_pcb, 123-pcb-design.kicad_sch]
2026-05-12 fix(web): set groups.device_id in ble-register so ingest finds the group.
2026-05-13 feat(HX711): provisioning, Wi-Fi, ingest flow; fix web ingest group link; Expo Babel preset
    - HX711: BLE/NVS provisioning aligned with custom_ble_prov, Wi-Fi connect fixes,
    Bearer HTTPS ingest, conditional ingest posts (no spurious weight_g 0),
    wifi_sta_has_ip to avoid duplicate-connect deadlock.
    - sdkconfig: enable NimBLE, custom partitions (2MB factory), 4MB flash.
    - sdkconfig.defaults: preserve BT + partition + flash for set-target.
    - web-server: ingest resolves/auto-links groups.device_id from devices.owner.
    - mobile-app: add babel-preset-expo for Metro bundling.
    [main.c]
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2026-05-14 Fix ingest to multiple groups with the same device id
2026-05-15 pcb rev 4 w/ battery monitor circuit
    [123-pcb-design.kicad_pcb, 123-pcb-design.kicad_sch]
2026-05-15 removed resistor from voltage supply path
    [123-pcb-design.kicad_pcb]
2026-05-15 Made walls 4mm higher
    [compartment_v7.3mf, compartment_v9.stl]
2026-05-15 adding webpage section
    [compartment_v9.3mf]
2026-05-15 Updating demo script
    [compartment_v9.3mf, top_plate_v1.3mf]
2026-05-17 Made USB hole wider
    [compartment_v10.stl]
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2026-05-18 fixing pocket sizes
    [base_plate_v12.3mf, base_plate_v13.stl, top_plate_v2.stl]
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2026-06-02 DRC passes for schematic
    [123-pcb-design.kicad_pcb, 123-pcb-design.kicad_sch]
2026-06-02 new pcb documents, references added to schematic
    [123-pcb-design.kicad_pcb, 123-pcb-design.kicad_sch]
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2026-06-09 PCB picture for document
    [123-pcb-design.kicad_pcb]
